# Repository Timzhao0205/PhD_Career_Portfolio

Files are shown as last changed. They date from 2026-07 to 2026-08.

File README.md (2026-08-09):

# PhD_Career_Portfolio

Yiming "Tim" Zhao — Stanford EE PhD (Senesky group). Three tracks, kept
separate on purpose.

| Folder | What lives there | Index |
|---|---|---|
| `01_PhD_Research/` | GaN Hall-effect magnetic sensing for fusion diagnostics in the HSX stellarator: the experimental line, its publications, and the analysis packages built around it. | `01_PhD_Research_Folder_Info.md` |
| `02_Startup/` | Venture research — five rounds of searching for a company to found around 2029–2030 — plus two hands-on technical projects spun out of it. | `02_Startup_Folder_Info.md` |
| `03_Investments_and_Finance/` | Market learning lab and equity benchmarking missions. | — |

## Conventions

Two-digit prefixes order folders at every level, and the same numbering runs
inside each project: `01_` mission, `05_`/`80_` durable state, `90_` sources,
`98_` run metrics, `99_` audit.

Most numbered folders are self-contained Claude Code packages with their own
binding `CLAUDE.md`, a `00_README_START_HERE.md`, and `.claude/agents/`. Launch
`claude` from the package folder, not from here, so its rules and agents load.

Markdown is the source of truth everywhere. `.html` files are generated mirrors
— regenerate rather than edit them.

## Two things worth knowing about

- **`02_Startup/00_SOURCE_DATABASE/`** — every source any startup round ever
  gathered, 3,432 of them, merged into one queryable database with full
  provenance. Search it before starting new research.
- **Snapshot folders.** Two run packages vendored full copies of research that
  already lives elsewhere in this repository. Those copies were removed and
  replaced by a manifest and a `rehydrate.py` that rebuilds them on demand:
  `01_PhD_Research/09_PAP06_Career_Portfolio_Synthesis_2026-07/sources/` and
  `02_Startup/07_Frontier_Ideas_Interactive_2026-07/src/06/`. Each has a README.

`REORGANIZATION_2026-08.md` records the 2026-08-08 cleanup that produced the
current layout.

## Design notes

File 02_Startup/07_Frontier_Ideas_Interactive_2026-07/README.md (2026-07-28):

# Folder 06 interactive Fable rerun — no budget stop

This is a fresh standalone package for Windows PowerShell 5.1 and Claude Code
interactive mode. It preserves the complete validated Folder 06 corpus but
does not reuse the previous PowerShell stream parser, response sentinel,
per-stage child launchers, or budget/turn-stop machinery.

## One command to start or resume

Extract to a short path, preferably:

```text
C:\AI\F06I
```

Open **Windows PowerShell**, enter the extracted folder, and run:

```powershell
powershell -NoProfile -ExecutionPolicy Bypass -File .\START.ps1
```

The same command:

1. checks the exact PowerShell target and package/source hashes;
2. parses every active PowerShell script using the installed PS 5.1 parser;
3. runs offline fixtures for every stage and every hook;
4. starts a persistent interactive Claude Code session on Fable 5/xhigh;
5. resumes the recorded session on later runs;
6. keeps working through all eight stage pilots and full stages;
7. validates and checkpoints every stage;
8. stops only after the final audited release passes.

There is no package-defined monetary, turn, token, or time shutdown.

## Required setup

1. Use the memorized runtime:

   ```text
   Windows PowerShell 5.1.26100.8875 Desktop
   Build 10.0.26100.8875
   CLR 4.0.30319.42000
   ```

2. Install and sign in to Claude Code. Confirm:

   ```powershell
   claude --version
   claude
   ```

   If Claude opens successfully, exit that test session and return to this
   folder.

3. Keep the package at a short path. Do not run it from inside another Claude
   project.

4. Run the one command above. Claude opens interactively and begins
   automatically. You may observe it, but routine input is not required.

## Model and effort route

| Stage | Main accepted work | Auxiliary work | Pilot |
|---|---|---|---|
| 10_refresh | Fable 5/xhigh reconciliation | Sonnet/high retrieval | Required |
| 20_p4 | Fable 5/xhigh scoring | Sonnet/high mechanical check | Required |
| 30_redteam | Fable 5/xhigh judgment | Sonnet/high retrieval | Required |
| 40_select | Fable 5/xhigh selection | Sonnet/high mechanical check | Required |
| 45_packs | Fable 5/xhigh acceptance | Sonnet/high retrieval/check | Required |
| 50_deep | Fable 5/xhigh deep analysis | Sonnet/high retrieval/check | Required |
| 60_synth | Fable 5/xhigh synthesis | Sonnet/high mechanical check | Required |
| 70_audit | Fable 5/xhigh final audit | Sonnet/high retrieval/check | Required |

The main session remains Fable throughout, so the package no longer has to
switch or parse models between stages.

## Full permissions

The launcher uses:

```text
--permission-mode bypassPermissions
```

This provides unattended read/edit/tool permission. It is powerful. Run only
inside this dedicated folder, preferably in a Windows Sandbox or VM. Project
instructions prohibit writes outside the package and prohibit modification of
`src\06`, but bypass mode itself is not an operating-system sandbox.

## Logging

| File | Contents |
|---|---|
| `logs\status.jsonl` | Model, effort, tokens, context, duration, cost telemetry, limits |
| `logs\events.jsonl` | Session, failure, subagent, compaction, and stop events |
| `state\ACTIVE_SESSION.json` | Resumable session ID and observed model |
| `state\stages\<stage>.json` | Validation result, model/effort, files, hashes |
| `pilot\<stage>` | Required pre-stage pilot |
| `outputs\<stage>` | Accepted full-stage work |
| `outputs\70_audit\FINAL` | Canonical audited package |

Reported dollar values are telemetry; they are not a local spending cutoff.

## Pausing and resuming

- To pause manually, press `Ctrl+C`. The Stop hook does not override a user
  interrupt.
- To resume, rerun the same `START.ps1` command.
- If Claude Code reports an external usage or authentication limit, close it,
  resolve/wait for the external issue, and run the same command.
- Do not delete `state`, `outputs`, `logs`, or `pilot`.

Optional diagnostics:

```powershell
# Offline checks and fixtures only
powershell -NoProfile -ExecutionPolicy Bypass -File .\START.ps1 -CheckOnly

# Verify all completed stages and the final release
powershell -NoProfile -ExecutionPolicy Bypass -File .\VALIDATE.ps1 -All

# Start a fresh interactive session while retaining durable outputs
powershell -NoProfile -ExecutionPolicy Bypass -File .\START.ps1 -NewSession

# Explicitly authorize a fresh attempt after a protected second model event
powershell -NoProfile -ExecutionPolicy Bypass -File .\START.ps1 -RetryFableAfterReview
```

`-AllowCompatiblePS51` accepts another Windows PowerShell 5.1 Desktop patch
level. Use it only when you intentionally changed Windows; the default remains
the exact memorized runtime.

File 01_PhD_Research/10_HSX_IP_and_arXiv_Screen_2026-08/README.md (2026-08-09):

# HSX IP/arXiv review — native Claude Code package

This is a self-contained, publication-only research package. It launches the
native Claude Code interface from Windows PowerShell, requests Claude Fable 5 at
xhigh effort for the parent and critical judgment stages, assigns Sonnet 5 to
cost-efficient support stages, and saves checkpoints after every stage.

It does **not** inherit state, outputs, source counts, or errors from any earlier
package. The large PhD and startup archives are intentionally excluded because
the task is limited to technologies actually disclosed in this manuscript.

## Recommended setup

1. Extract this folder to a short local path, preferably `C:\HSX_IP` or
   `D:\HSX_IP`. Do not run it from inside the ZIP.
2. Open **Windows PowerShell** in that extracted folder.
3. If native Claude Code is not installed, run once:

   ```powershell
   irm https://claude.ai/install.ps1 | iex
   ```

4. If you have never signed in, run `claude` once and complete authentication.
5. Begin or resume with the same single command:

   ```powershell
   powershell -NoProfile -ExecutionPolicy Bypass -File .\START.ps1
   ```

`START.ps1` performs a deterministic preflight, opens the interactive Claude
Code interface, and uses a named session. On later runs it resumes from
`state/STATE.json` and the latest checkpoint.

## Permission warning

The command uses `--dangerously-skip-permissions` because full read/write access
was requested. Native Windows does not sandbox this mode. The project rules tell
Claude to work only in this folder, but the operating-system permission is
broader. Use a dedicated folder and do not place credentials or unrelated
sensitive files beside it. Claude Code may display its own one-time confirmation
the first time bypass mode is used; a project cannot suppress that safeguard.

## Model integrity

- Parent/orchestrator: Fable 5 / xhigh.
- Critical IP, UHV/GDC, red-team, and final stages: Fable 5 / xhigh.
- Structured extraction and source-heavy stages: Sonnet 5 at medium to xhigh.
- Automatic model switching on a safety flag is disabled.
- A first Fable flag is quarantined and retried once with a narrower benign
  prompt; a second pauses with a durable checkpoint.
- No provider or model substitution is silently accepted.

See `MODEL_PLAN.md` for the full table. Actual model, effort, duration, turns,
tokens, web activity, and cost are logged only when Claude Code exposes them;
unknown values are recorded as `not_exposed` rather than guessed.

## Intended outputs

The main decision documents will appear under `outputs`:

- `70_FINAL_OTL_BRIEF.md`
- `70_EXEC_SUMMARY.md`
- `70_MODEL_REPORT.md`
- `50_ARXIV_RISK.md`
- `40_UHV_PACKAGE_VERDICT.md`

The workflow performs research and drafts only. It does not file a patent,
contact Stanford OTL or counsel, modify the submitted manuscript, or upload to
arXiv.

## If interrupted

Run the same command again. Do not delete `state`, `outputs`, or `.claude`.
Consult `RESUME.md` only if the workflow explicitly writes `state/PAUSE.md`.

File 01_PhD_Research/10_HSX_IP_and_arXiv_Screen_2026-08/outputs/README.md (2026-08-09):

# Generated outputs

Claude Code writes stage deliverables here. This placeholder prevents an empty
directory from disappearing during ZIP extraction.

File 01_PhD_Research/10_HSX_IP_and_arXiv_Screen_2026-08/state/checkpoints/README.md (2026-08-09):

# Checkpoints

The parent writes one `XX_done.json` file after each accepted stage. These are
the authoritative resume boundaries.

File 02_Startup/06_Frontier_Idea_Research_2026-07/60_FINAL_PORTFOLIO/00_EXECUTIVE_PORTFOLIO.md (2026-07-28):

# Executive frontier portfolio

## Outcome

The portfolio contains exactly 24 launch-2030 concepts that pass the seven hard gates after adversarial review. It is intentionally a set of testable options rather than a forced single winner: score ranges overlap, buyer access remains unproven for several concepts, and the 2026-2029 program is designed to remove those uncertainties before company formation.

| Rank | Idea | Concept | Lane | Archetype | US | China | Score | Evidence posture |
|---:|---|---|---|---|:---:|:---:|---:|---|
| 1 | `P3R2-D-02` | Reel-to-reel contactless REBCO tape quality metrology (Hall-array critical-current mapping + delamination screening) sold to tape vendors and magnet builders as certified acceptance instrumentation. | L03 | industrial | Y | Y | 65.6 | evidence-rich |
| 2 | `P3R2-C-22` | Electrolyzer stack degradation-emulation and bankability test systems: programmable ripple/intermittency benches that turn stack warranties into measurable engineering | L11 | industrial | Y | Y | 64.6 | evidence-rich |
| 3 | `P3R2-D-01` | Merchant quench-detection-and-protection subsystem for REBCO/HTS magnets: co-wound distributed fiber-optic sensing plus sub-millisecond active energy extraction, sold with a qualification dossier to fusion companies and national labs. | L03 | scientific_big_physics | Y | N | 62.8 | mixed evidence |
| 4 | `P3R2-F-01` | Solid-state microsecond impedance-matching engines (switched SiC/PIN capacitor arrays replacing motorized vacuum-capacitor matchboxes) for pulsed and tailored-waveform RF plasma tools | L06 | industrial | Y | Y | 59.8 | evidence-rich |
| 5 | `P3R2-C-01` | 800-VDC rack power-path protection: integrated solid-state breaker + precharge/inrush control + insulation monitoring + hot-swap sequencing unit for AI racks and power sidecars | L02 | infrastructure_utility_transport | Y | Y | 59.6 | evidence-rich |
| 6 | `P5-USSCI2-S01` | Qualified diamond transmission-dynode membrane and integration cartridge for hybrid MCP-PMTs used in EIC-class photon detectors | L13 | scientific_big_physics | Y | N | 58.2 | mixed evidence |
| 7 | `P3R2-E-14` | Multi-terminal DC fault-discrimination protection relay plus vendor-neutral hardware-in-the-loop qualification platform for MVDC datacenter distribution and HVDC converter stations - the 'SEL of DC grids.' | L08 | infrastructure_utility_transport | Y | N | 56.4 | evidence-rich |
| 8 | `P5R2-CN-01` | Retrofit X-ray computed-laminography kit for advanced-packaging failure analysis | L06 | industrial | Y | Y | 55.6 | evidence-rich |
| 9 | `P3R2-A-14` | 300C-class mixed-signal instrumentation electronics platform (SiC/SOI) for superhot geothermal, downhole, and turbine environments | L15 | industrial | Y | N | 54.6 | mixed evidence |
| 10 | `P3R2-C-13` | Precision GaN pump-driver and laser-power modules: nanosecond-class programmable current drive as a merchant subsystem for industrial and defense-adjacent laser OEMs | L12 | industrial | Y | Y | 54.2 | mixed evidence |
| 11 | `P3R2-C-08` | Thermal-shock-tolerant printed-circuit heat exchangers (PCHE): merchant diffusion-bonded recuperators for sCO2 power, heat pumps, and hydrogen precooling | L04 | industrial | Y | Y | 51.6 | mixed evidence |
| 12 | `P3R2-B-01` | Sealed negative-pressure (subatmospheric) water/low-GWP two-phase cold-plate loop for >2 kW/chip Chinese AI racks - leak-safe by physics (air leaks in, coolant never leaks out), PFAS-free by design | L14 | infrastructure_utility_transport | N | Y | 51.0 | mixed evidence |
| 13 | `P3R2-E-04` | High-density cryogenic interconnect loader with co-packaged 4K readout front-end (superconducting flex harness + cryo-CMOS multiplexing + cryo-LNA), breaking the 256-channel-per-loader wall for quantum computers. | L13 | scientific_big_physics | Y | N | 51.0 | mixed evidence |
| 14 | `P5R2-CN-03` | Field-deployable industrial high-temperature heat-pump commissioning and measurement-and-verification island | L04 | industrial | N | Y | 50.0 | mixed evidence |
| 15 | `P3R2-F-02` | Superconducting-magnet electrical balance-of-plant platform: standardized precision drive-and-dump skids (10 ppm-class high-current DC converters + energy-extraction/dump units + current leads + busbars) | L03 | scientific_big_physics | Y | Y | 49.4 | speculative / validate first |
| 16 | `P3R2-C-04` | PFAS-free pumped two-phase direct-to-chip cooling loop: hermetic, fluid-agnostic evaporator/condenser subsystem co-qualified with low-GWP non-PFAS working fluids | L14 | infrastructure_utility_transport | Y | Y | 49.0 | speculative / validate first |
| 17 | `P3R2-F-12` | Classification-certified DC power and protection stacks for battery-electric and battery-swap inland/coastal vessels (CCS Rules-native string protection, insulation monitoring, containerized-pack power interface) | L10 | infrastructure_utility_transport | N | Y | 47.6 | speculative / validate first |
| 18 | `P3R2-G-01` | Closed-loop UHV chamber conditioning and acceptance-certification systems for China's big-science vacuum supply chain: instrumented vacuum-firing/bakeout stations with measured hydrogen-outgassing endpoints, integrated rate-of-rise/leak/RGA acceptance metrology, and tamper-evident per-chamber certification - sold as equipment plus recurring calibration to the China-registered fabricators who alone may bid HEPS/CEPC-class chamber tenders. | L07 | industrial | N | Y | 47.6 | speculative / validate first |
| 19 | `P3R2-A-10` | Vendor-neutral ion-energy-distribution metrology + tailored-waveform bias control retrofit for plasma etch chambers | L06 | industrial | Y | Y | 47.4 | speculative / validate first |
| 20 | `P3R2-G-03` | DC-conversion acceptance and commissioning instrumentation: a portable measurement island (swept-impedance bus-stability analyzer, IT-network insulation/ground-fault characterization, hot-swap/inrush transient capture) plus standardized acceptance protocols and signed dossiers, for facilities converting legacy UPS power rooms to 240V/336V/+-400V/800VDC and for vendors qualifying DC shelves - the measurement layer of the DC transition, not another in-path power product. | L02 | infrastructure_utility_transport | Y | Y | 47.0 | speculative / validate first |
| 21 | `P3R2-D-12` | Electrohydrodynamically-pumped two-phase cold plates: field-driven, no-moving-parts per-chip flow control for 3-5 kW AI packages, with a non-PFAS working-fluid plan. | L14 | infrastructure_utility_transport | Y | Y | 46.8 | speculative / validate first |
| 22 | `P3R2-F-23` | PEM electrolyzer 'protective operating envelope' controllers with warranty-grade black-box logging: embedded plant hardware that shapes current/OCV stress and produces bankable degradation evidence | L11 | industrial | Y | Y | 44.2 | speculative / validate first |
| 23 | `P3R2-F-06` | Precision wideband DC current/voltage sensing platform (optical and zero-flux hybrid) for HVDC converter stations, electrolyzer plants, and magnet systems | L08 | infrastructure_utility_transport | Y | N | 42.4 | speculative / validate first |
| 24 | `P3R2-F-03` | High-speed permanent-magnet turbo-generator + power-converter 'electrical cartridge' (0.3-20 MW) for waste-heat sCO2 and geothermal/ORC power blocks | L04 | industrial | Y | Y | 37.2 | speculative / validate first |

## Why the portfolio is frontier and credible

The common pattern is a narrow, controllable product inserted where a frontier system becomes measurable, protectable, certifiable, or manufacturable. The coolest ideas are not speculative physics projects: they turn difficult physical behavior into a product boundary that a named operator, laboratory, OEM, or project developer must accept.

Credibility comes from explicit kill rules. The portfolio gives no structural credit to held concepts, access-dependent cheap experiments, generic category spending, or policy aspirations without an exact product job. Ten immediately executable sub-$100k falsifiers test merchant sockets and acceptance boundaries before expensive hardware programs.

## How to use the ranking

Ranks are triage order, not certainty. Start the cheapest decisive tests across several lanes in parallel. Promote only ideas that earn signed access, buyer-owned data, paid evaluation, or interface-control participation; demote any idea whose wedge is absorbed by an incumbent or whose named 2030 trigger slips.

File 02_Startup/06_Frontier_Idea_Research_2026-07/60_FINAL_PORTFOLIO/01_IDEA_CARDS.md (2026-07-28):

# Full idea cards

Every card keeps the same order. Founder fit is intentionally last and carries only 2/100 of the score.

## 1. Reel-to-reel contactless REBCO tape quality metrology (Hall-array critical-current mapping + delamination screening) sold to tape vendors and magnet builders as certified acceptance instrumentation. (`P3R2-D-02`)

**Buyer and painful job.** Commonwealth Fusion Systems (Devens tape/magnet line); Furukawa/SuperPower (several-hundred-km supply deal to Tokamak Energy); Shanghai Superconductor / Shanghai Shangchuang (CN domestic capacity buildout); Western Superconducting Technologies (CN, ITER strand lineage, L03-031, from B-10); ASIPP Hefei high-field magnet program (CN, L03-029/037, from B-10). Fewer than 10 tape vendors supply the world; a single fusion order absorbs a meaningful share of annual output, yet Ic uniformity, strain/delamination and screening-current degradation force magnet builders to over-specify and re-test tape with bespoke, non-comparable acceptance methods (L03-003, L03-019, L03-018, L03-020, L03-021).

**Product.** 77 K reel-to-reel scanner: dense Hall-sensor array plus lock-in thermal imaging maps position-resolved Ic and detects buried delamination/dropouts at m/s line speed, with transport-Ic-calibrated reporting and a shared acceptance data format for vendor and buyer. Merged extensions: 10kA-class cable/CICC acceptance stations and financier/insurer-grade data packages (from C-11); per-meter 'conductor passport' reporting framing (from B-10); conductor/joint QA benches with a Furukawa/Fujikura partnership channel (from E-07).

**Cool frontier vision.** The KLA of superconductors: every kilometer of HTS tape and every finished cable/coil ships with a standardized, instrument-traceable quality map, closing the loop back into deposition process control.

**Extreme edge.** Imaging supercurrents through millimeters of steel and silver at highway speed -- a contactless ammeter for a quantum fluid.

**Current demand proof.** Tokamak Energy and Furukawa Electric Group Strengthen Relationship to Progress Commercial Fusion Energy (L03-044); 全球首条超公里级高温超导电缆投运 (World's first kilometer-class HTS cable enters operation, Shanghai) (L03-041); U.S. Department of Energy Announces Selectees for Fusion Innovation Research Engine Collaboratives and Milestone Program progress (L03-032); Commonwealth Fusion Systems leans on magnets for near-term revenue (L03-035)

**Niche size by bottom-up arithmetic.** Screening case: 18 sites × $300k instrument + 18 × $60k annual calibration/service = $6.48M annualized niche. Named-site counting and buyer quotes must replace the assumptions.

**Competition.** Vendor in-house scanners (THEVA Tapestar-class -- judgment), Lake Shore-style lab instruments, national-lab one-offs. No merchant, buyer-trusted acceptance-metrology vendor in the atlas record set.

**Technical path.** Current TRL 4. 2026-27: benchtop magnetscan rig on purchased tape lots; publish correlation of contactless Ic estimate to transport Ic within a few percent. 2027-28: pilot placements with one US magnet builder and one tape vendor under NRE contracts; extend to coil/cable acceptance heads. 2029: inline-speed prototype at a vendor line; draft an open acceptance-report schema with two counterparties.

**Decisive experiment and budget.** $120,000. Benchtop 77 K reel-to-reel Hall-array scan of 100 m commercial tape; blind-correlate predicted vs transport Ic on 50 cut samples to <5% error (2027). The bounded test attacks the candidate's load-bearing technical and buyer-acceptance assumptions with explicit pass/kill thresholds.

**V1 capital and time.** 1500000; 4000000 Target 18-30 months from frozen interface to qualification-ready v1.

**Risks and kill criteria.** Tape vendors may bundle 'good-enough' in-house QC data; if one instrument maker partners exclusively with the largest vendor, the neutral-referee position is lost. Commercial kill: 2034-06

**US route.** Countable base case. Start with the named buyers, integrators, and qualification facilities in the accepted pack.

**China route.** Countable base case using locally supportable supply, calibration, qualification, and civilian buyer channels; screen counterparties and data flows before engagement.

**Optional side routes.** JP; KR only after the primary route proves repeatability.

**Expansion.** Move from the first exact acceptance boundary into adjacent ratings, facilities, and recurring calibration, software, or qualification evidence only after the core product is paid for.

**Score and confidence.** 65.6/100; medium. Launch thesis: Tape volume triples-to-10x between 2026 and the early-2030s pilot-plant builds; QC pain scales with volume and with new entrants' unproven lines, peaking exactly at launch. Demand trigger: Fusion pilot-plant tape procurement waves (CFS ARC-class; Tokamak Energy ST80-HTS wire deal as precedent, L03-044), Chinese domestic REBCO capacity expansion for import independence (L03-052), and CFETR magnet procurement if construction starts (L03-024). Additional evidenced demand (merged): DOE milestone-program QA needs and CFS magnet-as-product certification (L03-032/035, from C-11); the State Grid Shanghai 35 kV commercial HTS cable and follow-ons (L03-041, from B-10); ASIPP's high-field program (L03-029/037) and WST's ITER-strand QA lineage (L03-031).

**Citations.** [L03-003](https://www.nature.com/articles/s41598-021-81559-z) [L03-019](https://www.sciencedirect.com/science/article/pii/S2772830725000390) [L03-024](https://www.sciencedirect.com/science/article/abs/pii/S0920379622000631) [L03-029](https://www.the-innovation.org/article/id/695a0b800989772a128c5422) [L03-018](https://academic.oup.com/nsr/article/10/3/nwad001/6973212) [L03-044](https://www.furukawaelectric.com/en/release/2023/kenkai_20230112.html) [L03-041](https://www.jiemian.com/article/6938856.html) [L03-052](https://chinacable.com/news/details/3999)

**Founder fit (2/100; last).** The transferable fit is instrumentation, embedded control, electromagnetics, prototyping, and technical research. This note did not rescue demand, competition, capital, geography, or timing failures.

## 2. Electrolyzer stack degradation-emulation and bankability test systems: programmable ripple/intermittency benches that turn stack warranties into measurable engineering (`P3R2-C-22`)

**Buyer and painful job.** US H2Hubs project developers and their lenders (US); Plug Power-class OEM warranty engineering (US); LONGi/Peric/Sungrow hydrogen divisions (CN); Chinese EPC/owner acceptance-test labs for mega-tenders (CN). US: stack warranties are written before the industry knows which stress (OCV rest, ripple amplitude, load-following rate) drives which degradation mode (L11-001/003/004/021/031) - a direct bankability problem for H2Hubs-financed projects (L11-032) and OEMs bleeding order books (L11-047/048). CN: 100+-unit multi-vendor tenders (L11-050/051) and flagship underperformance (Kuqa, L11-049) create buyer-side acceptance-testing demand with no standard test hardware.

**Product.** Turnkey 50-500kW stack test benches with programmable rectifier-ripple synthesis, renewable-profile playback, OCV-cycling protocols, and impedance diagnostics; plus a shared accelerated-vs-field degradation dataset licensed to financiers - the Chroma of electrolysis (battery-formation analogy: L11-043/044).

**Cool frontier vision.** The qualification authority for electrochemical assets: electrolyzers first, then flow batteries, CO2 electrolyzers, and formation lines - whoever owns degradation truth owns the industry's cost of capital.

**Extreme edge.** Synthesizing 20-year renewable-coupled electrochemical stress histories in 90-day campaigns with per-mechanism attribution (catalyst dissolution vs membrane vs contact resistance).

**Current demand proof.** Regional Clean Hydrogen Hubs award announcement -- up to $2.2 billion for Gulf Coast (HyVelocity) and Midwest (MachH2) Hubs (L11-032); Plug Power Reports Q4 and Full Year 2025 Results with Strong Sales Growth and Margin Expansion (L11-046); Nel ASA: Fourth quarter 2025 financial results (L11-047); thyssenkrupp nucera returns to profit in 2024/2025 despite decline in sales (FY2024/25 results) (L11-048)

**Niche size by bottom-up arithmetic.** Screening case: 18 sites × $300k instrument + 18 × $60k annual calibration/service = $6.48M annualized niche. Named-site counting and buyer quotes must replace the assumptions.

**Competition.** Greenlight Innovation-class test-stand vendors (industry name, flag for P4 - not in atlas), battery-test majors extending sideways (Chroma/Hioki, L11-043/044), OEM in-house labs. Wedge: degradation-science depth + financier-facing datasets, not just power hardware.

**Technical path.** Current TRL 5. 2026-27: replicate published degradation stressors on a 10kW bench (university electrochemistry lab); publish accelerated-test correlation study - the field's missing dataset. 2027: decisive 50kW bench (below). 2028: paid pilot campaigns via lab (OEM + one lender consortium). 2029: purchase LOIs; refresh the demand picture - Western OEM health and Chinese tender cadence will have shifted from 2026.

**Decisive experiment and budget.** $250,000. 2027: 50kW programmable-ripple/OCV-cycling bench; 90-day accelerated campaign on two commercial short stacks; publish correlation of induced vs literature degradation signatures. The bounded test attacks the candidate's load-bearing technical and buyer-acceptance assumptions with explicit pass/kill thresholds.

**V1 capital and time.** 4000000; 10000000 Target 18-30 months from frozen interface to qualification-ready v1.

**Risks and kill criteria.** Hydrogen demand volatility caps growth (order books shrinking now, L11-047/048) - but the seed monetizes uncertainty itself; worst case is a slow niche, not a zero. Export separability excellent (test equipment; CN entity straightforward). Kill if neither market yields bench sales nor paid campaigns by end-2033. Commercial kill: 2034

**US route.** Countable base case. Start with the named buyers, integrators, and qualification facilities in the accepted pack.

**China route.** Countable base case using locally supportable supply, calibration, qualification, and civilian buyer channels; screen counterparties and data flows before engagement.

**Optional side routes.** JP; KR only after the primary route proves repeatability.

**Expansion.** Move from the first exact acceptance boundary into adjacent ratings, facilities, and recurring calibration, software, or qualification evidence only after the core product is paid for.

**Score and confidence.** 64.6/100; medium. Launch thesis: Whether hydrogen booms or consolidates by 2030, both outcomes need qualification: boom -> acceptance testing at tender scale (CN); consolidation -> survivors differentiate on warranty credibility (US/EU). Test infrastructure is the hedge position on a volatile industry - deliberately anti-fragile to the L11 demand contradiction. Demand trigger: US: H2Hubs Phase-2 construction/commissioning waves with lender-mandated performance validation (L11-032). CN: second-wave green-H2 base tenders and retrofit/acceptance programs following first-wave underperformance (L11-049/050/051).

**Citations.** [L11-001](https://iopscience.iop.org/article/10.1149/1945-7111/ae1cf1) [L11-002](https://www.sciencedirect.com/science/article/abs/pii/S0016236125036452) [L11-003](https://iopscience.iop.org/article/10.1149/1945-7111/add184) [L11-004](https://www.sciencedirect.com/science/article/pii/S1364032125008433) [L11-021](https://pmc.ncbi.nlm.nih.gov/articles/PMC8877858/) [L11-032](https://www.energy.gov/articles/biden-harris-administration-announces-awards-22-billion-two-regional-clean-hydrogen-hubs) [L11-046](https://www.ir.plugpower.com/press-releases/news-details/2026/Plug-Power-Reports-Q4-and-Full-Year-2025-Results-with-Strong-Sales-Growth-and-Margin-Expansion/default.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) [L11-047](https://nelhydrogen.com/press-release/nel-asa-fourth-quarter-2025-financial-results/)

**Founder fit (2/100; last).** The transferable fit is instrumentation, embedded control, electromagnetics, prototyping, and technical research. This note did not rescue demand, competition, capital, geography, or timing failures.

## 3. Merchant quench-detection-and-protection subsystem for REBCO/HTS magnets: co-wound distributed fiber-optic sensing plus sub-millisecond active energy extraction, sold with a qualification dossier to fusion companies and national labs. (`P3R2-D-01`)

**Buyer and painful job.** Commonwealth Fusion Systems (sells magnets to Realta, WHAM); Tokamak Energy / TE Magnetics; DOE milestone-program fusion awardees; university/national-lab high-field magnet programs; US-ITER/ORNL magnet operations (from A-04/E-07, L03-030). HTS coils have very high minimum quench energy and slow normal-zone propagation, so voltage-tap detection fails; builders must choose between no-insulation windings (poor ramp/control) or unproven fast detection, over-engineering every multi-megajoule magnet (L03-004, L03-018, L03-020, L03-021).

**Product.** Retrofittable quench detection + protection package: Rayleigh-backscatter fiber co-wound in the coil plus RF/acoustic hotspot channels, fused in a deterministic FPGA trigger driving a qualified multi-kV energy-extraction/CLIQ-class dump circuit; delivered with test data at 10-20 T relevant conditions. Merged extensions: delivered with a published acceptance-test protocol and warranty-support framing for merchant magnet sales (from A-04); the accumulated quench-precursor signature dataset across driven-quench campaigns is the compounding moat (from E-07).

**Cool frontier vision.** Become the certification-grade 'flight recorder and ejection seat' for every high-field HTS magnet -- fusion, NMR, accelerator, industrial -- the way rad-hard PLCs became mandatory in nuclear I&C.

**Extreme edge.** Watching a superconductor start to die in real time -- centimeter-resolved strain/temperature along kilometers of tape at kilohertz rates -- and killing a 100 MJ discharge before it burns the coil.

**Current demand proof.** U.S. Department of Energy Announces Selectees for Fusion Innovation Research Engine Collaboratives and Milestone Program progress (L03-032); Tokamak Energy raises $125m to commercialise transformative fusion and magnet technologies (L03-033); Commonwealth Fusion Systems leans on magnets for near-term revenue (L03-035); 한전, 초전도 케이블로 심지 전력 공급한다 (KEPCO to supply downtown power via superconducting cable) (L03-042)

**Niche size by bottom-up arithmetic.** Screening case: 6 facilities × $750k initial system + 6 × $125k annual support = $5.25M annualized niche. This is decision arithmetic, not a sourced market forecast; replace both inputs with quotes before investment.

**Competition.** In-house teams at CFS/TE Magnetics (L03-035, L03-044), national-lab solutions (CERN CLIQ lineage, tuned for LTS), instrumentation vendors without protection power electronics. No merchant vendor of an integrated HTS detection+dump product identified in the atlas.

**Technical path.** Current TRL 3. 2026-27: university magnet-lab access (e.g., high-field magnet facility) and instrumentation of small REBCO pancakes; publish detection-latency benchmarks. 2027-28: DOE SBIR/INFUSE-class grants with a fusion partner; controlled-quench campaigns on 1-2 T coils. 2029: demonstrate 100 ms-class pre-quench warning plus automated dump on a multi-kA coil at a partner lab; freeze v1 architecture and qualification plan.

**Decisive experiment and budget.** $250,000. Co-wind fiber + RF pickup in a 1-2 T REBCO double-pancake, drive controlled quenches, and demonstrate >=100 ms warning before thermal runaway with <1% false-trigger rate (2027, university magnet lab). The bounded test attacks the candidate's load-bearing technical and buyer-acceptance assumptions with explicit pass/kill thresholds.

**V1 capital and time.** 3000000; 8000000 Target 18-30 months from frozen interface to qualification-ready v1.

**Risks and kill criteria.** If no-insulation windings prove fully sufficient at pilot-plant scale, the detection problem shrinks; if a magnet builder open-sources a good solution, differentiation collapses to service/qualification. Commercial kill: 2033-12

**US route.** Countable base case. Start with the named buyers, integrators, and qualification facilities in the accepted pack.

**China route.** Not a countable base case in this round; do not depend on this route.

**Optional side routes.** None required for the base case.

**Expansion.** Move from the first exact acceptance boundary into adjacent ratings, facilities, and recurring calibration, software, or qualification evidence only after the core product is paid for.

**Score and confidence.** 62.8/100; low. Launch thesis: SPARC-class results in 2026-27 convert into pilot-plant magnet builds around 2030; every new builder needs protection it cannot buy today, and qualification data accumulated 2027-2029 is the moat at exactly that moment. Demand trigger: Post-SPARC fusion pilot-plant magnet procurement (CFS ARC-class, Tokamak Energy ST80-HTS follow-on) and the DOE Milestone-Based Fusion Development Program renewal decision after its FY2027 authorization window (L03-032, L03-033, L03-035); CFETR magnet procurement if it opens (L03-024) is upside, not baseline. Side market (from E-07): KEPCO + LS Cable/LS Electric superconducting datacenter-grid MOU as a cable-monitoring channel (L03-042/043); US-ITER/ORNL magnet operations as lab-side buyers (L03-030). CN chapter (from C-17): ASIPP/CFETR demand logic exists (L03-024/029/037) but is served only via license-out and ONLY if export counsel clears - quench protection is dual-use-adjacent; no CN beachhead, flags unchanged.

**Citations.** [L03-004](https://doi.org/10.3390/instruments5030027) [L03-018](https://academic.oup.com/nsr/article/10/3/nwad001/6973212) [L03-020](https://iopscience.iop.org/article/10.1088/1361-6668/ad7f95) [L03-021](https://www.sciencedirect.com/science/article/abs/pii/S0920379623001072) [L03-029](https://www.the-innovation.org/article/id/695a0b800989772a128c5422) [L03-032](https://www.energy.gov/articles/us-department-energy-announces-selectees-107-million-fusion-innovation-research-engine) [L03-033](https://www.prnewswire.com/news-releases/tokamak-energy-raises-125m-to-commercialize-transformative-fusion-and-magnet-technologies-302310607.html) [L03-035](https://techcrunch.com/2026/04/02/commonwealth-fusion-systems-leans-on-magnets-for-near-term-revenue/)

**Founder fit (2/100; last).** The transferable fit is instrumentation, embedded control, electromagnetics, prototyping, and technical research. This note did not rescue demand, competition, capital, geography, or timing failures.

## 4. Solid-state microsecond impedance-matching engines (switched SiC/PIN capacitor arrays replacing motorized vacuum-capacitor matchboxes) for pulsed and tailored-waveform RF plasma tools (`P3R2-F-01`)

**Buyer and painful job.** Lam/AMAT-ecosystem RF integrators via Advanced Energy/MKS-class generator vendors (US); AMEC; NAURA; Piotech (via Hengyunchang/Injet supply chain, mature-node scope). Pulsed and tailored-voltage-waveform plasma processes change impedance faster than motorized vacuum-capacitor matching networks can follow; matching remains an active research problem (L06-001/002/003, L01-012/013) while CN RF-power component localization sits under ~12% (L06-054).

**Product.** Drop-in solid-state matching network family (400 kHz-60 MHz, 1-10 kW initially): switched capacitor/inductor arrays with sub-10-microsecond re-match, pulse-synchronous tuning tables, and health telemetry; sold to RF-generator vendors and tool OEMs; CN line scoped to >=28 nm/panel/display tools. CN chapter delivered as licensing-with-golden-reference (absorbed from F-14): the CN licensee manufactures under milestone-based contracts while the founder retains golden-reference subassemblies, calibration methodology, and factory test benches - certification power stays with the licensor (HK-structured IP entity).

**Cool frontier vision.** The impedance-delivery layer for all fast plasma processing: every pulsed plasma tool, leading-edge or mature-node, tunes in microseconds instead of hundreds of milliseconds, unlocking waveform-level process control as a standard capability.

**Extreme edge.** Pulse-by-pulse impedance trajectory control co-optimized with bias waveform, enabling ion-energy control on tools that never get an IEDF sensor.

**Current demand proof.** Advanced Energy (AEIS) Q4 2025 Earnings Call Transcript (L06-039); Shenzhen CSL Vacuum Science and Technology (Hengyunchang) IPO: customer concentration and financial disclosure (L06-042); Hengyunchang lists on SSE STAR Market, shares surge over 300% (L06-043); Sichuan Injet Electric (Yingjie Dianqi) 2024 Annual Report -- semiconductor RF power segment (L06-044)

**Niche size by bottom-up arithmetic.** Screening case: 12 production lines × $600k subsystem + 12 × $90k annual service/qualification = $8.28M annualized niche. This is a transparent validation target, not a top-down forecast.

**Competition.** Comet (Synertia platform), Advanced Energy and MKS in-house matches, DAIHEN; CN: Hengyunchang/Injet moving up-stack. Domestic-substitution speed in CN is fast at generator level but slow at high-end match-component level.

**Technical path.** Current TRL 4. 2026-27 university-lab prototype (13.56 MHz, 5 kW) and switching-loss/linearity characterization; 2027 export-control counsel gate on CN scope; 2028 two paid evaluations with a generator vendor or tool OEM; 2029 reliability data (1e9 switch events) and design-freeze of a productizable module. CN-chapter licensing mechanics (from F-14): HK-structured IP entity and milestone-based license contracts scoped 2028, know-how held in calibration/test assets.

**Decisive experiment and budget.** $250,000. Build 13.56 MHz/5 kW switched-capacitor matcher; demonstrate <10 us re-match across a pulsed plasma load recipe versus >100 ms motorized baseline, with reflected-power and lifetime data (2027). The bounded test attacks the candidate's load-bearing technical and buyer-acceptance assumptions with explicit pass/kill thresholds.

**V1 capital and time.** 3000000; 8000000 Target 18-30 months from frozen interface to qualification-ready v1.

**Risks and kill criteria.** If AE/MKS ship integrated solid-state matching as a standard feature before a merchant module gains a design win, the socket closes; mitigated by selling to the same incumbents and to CN OEMs the US incumbents cannot serve. Commercial kill: 2034 (kill if no OEM design-in or paid evaluation converts to a production order by end-2033)

**US route.** Countable base case. Start with the named buyers, integrators, and qualification facilities in the accepted pack.

**China route.** Countable base case using locally supportable supply, calibration, qualification, and civilian buyer channels; screen counterparties and data flows before engagement.

**Optional side routes.** KR only after the primary route proves repeatability.

**Expansion.** Move from the first exact acceptance boundary into adjacent ratings, facilities, and recurring calibration, software, or qualification evidence only after the core product is paid for.

**Score and confidence.** 59.8/100; medium. Launch thesis: Pulsed/TVW process adoption broadens through 2030 while incumbent matchboxes remain electromechanical; solid-state matching is demonstrated in literature but not productized as a merchant module, leaving a 2030-2034 design-in window before AE/MKS/Comet fully absorb it. Demand trigger: US: next tool-generation qualification cycles at leading-edge fabs (AE Everest/EVOS-class platform ramps per L06-039/040) requiring pulse-synchronous match; CN: 15th/16th Five-Year-Plan semiconductor-equipment localization programs and SMIC/YMTC mature-node expansions pulling domestic RF component content above today's <12% (L06-051/052/054).

**Citations.** [L06-001](https://pubs.aip.org/avs/jvb/article/42/2/022212/3277858/Modeling-and-control-of-L-type-network-impedance) [L06-002](https://pubs.aip.org/aip/jap/article/137/3/033301/3331468/Impedance-matching-assistance-based-on-frequency) [L06-003](https://www.mdpi.com/2079-9292/10/17/2074) [L06-009](https://pubs.aip.org/aip/pop/article/31/3/033508/3279954/Voltage-waveform-tailoring-for-high-aspect-ratio) [L01-012](https://pubs.aip.org/avs/jva/article/37/2/021303/247270/Experimental-demonstration-of-multifrequency) [L06-039](https://www.fool.com/earnings/call-transcripts/2026/02/10/advanced-energy-aeis-q4-2025-earnings-transcript/) [L06-042](https://www.cls.cn/detail/2060122) [L06-043](https://www.cls.cn/detail/2272598)

**Founder fit (2/100; last).** The transferable fit is instrumentation, embedded control, electromagnetics, prototyping, and technical research. This note did not rescue demand, competition, capital, geography, or timing failures.

## 5. 800-VDC rack power-path protection: integrated solid-state breaker + precharge/inrush control + insulation monitoring + hot-swap sequencing unit for AI racks and power sidecars (`P3R2-C-01`)

**Buyer and painful job.** Vertiv (US); Eaton (US); Schneider Electric (US ops); Google/Meta/Microsoft via OCP (US); Huawei-class DC integrators (CN); Alibaba datacenter power suppliers e.g. Shenzhen Autrans (CN). US: 800VDC racks specified by NVIDIA/OCP have no converged DC fault-interruption, precharge, grounding, or hot-swap solution (L02-043, L02-044; SSCB still research-stage L08-017, L08-001/003/004). CN: Huawei-ecosystem trade engineering flags 800V DC protection, grounding, hot-plug, and inlet-node oscillation as unresolved integration pain (L02-054); China HVDC datacenter penetration was only ~12% vs 78% UPS, so the conversion wave is ahead, not behind (L02-048).

**Product.** A shelf-format 800V/250-500A hybrid solid-state protection-and-sequencing unit: <100 us fault clearing, arc-signature detection (L08-018/019/020/021 methods), managed precharge, IMD, and blind-mate hot-swap logic, pre-certified to IEC 62477-1 (L02-112). Imports from merged duplicates: fleet-wide DC arc-signature analytics with a UL/IEC listing-path emphasis (from A-01); synthesized-virtual-impedance active bus damping and capacitor-health (ripple/ESR) telemetry (from B-03); arc rate-of-change dataset moat built from accumulated fault-signature libraries (from E-01).

**Cool frontier vision.** Become the de facto 'circuit-breaker layer' for all DC-native infrastructure: 800V racks, 1500V sidecars, MVDC campus feeders, EV megawatt charging, and DC industrial parks.

**Extreme edge.** Sub-100-microsecond bidirectional fault interruption at 800V/500A in a hot-swappable shelf form factor, with arc discrimination that avoids nuisance trips at 1MW-rack transient levels.

**Current demand proof.** OCP Members Tout DC Power in the Data Center to Meet Growing AI Energy Demands (L02-044); Wolfspeed (WOLF) Q3 2026 Earnings Call Transcript (L02-047); GE Vernova Q1 2026 earnings call transcript (L08-033); Delta Partners with Alibaba to Launch "Data Center Panama Power Supply," Opening a New Chapter in IDC Power (L02-048)

**Niche size by bottom-up arithmetic.** Screening case: 15 projects × $500k deployment + 15 × $75k annual qualification/support = $8.63M annualized niche. Treat project count and price as falsifiable planning inputs.

**Competition.** US 2030: Eaton/Vertiv/Schneider integrated shelves, ABB/Siemens industrial DC breakers, 1-2 funded SSCB startups. CN 2030: Huawei in-house, Delta China, Autrans (L02-049), Innoscience-device-based designs (L02-050). Window: incumbents sell whole shelves; a certified merchant protection layer that all shelf vendors can embed is unoccupied.

**Technical path.** Current TRL 4. 2026-27: publish comparative SSCB topology benchmark from lab work; join OCP power workstream; file 2-3 provisional patents on combined precharge+breaking+arc-discrimination. 2027: decisive brassboard experiment (below). 2028: second-gen unit tested in a partner rack lab (integrator MOU, no company needed); UL/IEC pre-compliance data. 2029: design-in discussions with 2 US integrators and 1 CN ODM via licensing LOIs; refresh 2029 market/pricing evidence before incorporation.

**Decisive experiment and budget.** $48,000. Merchant-module boundary falsification (4 months; $48,000). Pre-register: Freeze combined-module boundary, three required counterparties, evidence form, 2029 design-in horizon, and no-credit rules for verbal interest. Pass: Two integrators provide written requirement redlines; At least one counterparty signs a paid evaluation assigning protection, precharge, IMD, and sequencing to a replaceable third-party module through 2029. Kill: All counterparties allocate functions to fuses, internal shelves, or platform standards; No paid evaluation or replaceable socket. Budget: specification mapping $10,000, fmeca and safety case $6,000, interface control document $8,000, integrator workshops $8,000, china screening and counsel $8,000, evaluation contracting $4,000, independent review $4,000. If the merchant socket is absent, no affordable technical prototype can create it. The outreach is executable without assuming access and has a binary company-kill rule.

**V1 capital and time.** 8000000; 20000000 Target 18-30 months from frozen interface to qualification-ready v1.

**Risks and kill criteria.** Export-control separability: good - protection electronics are conventional industrial power electronics (largely EAR99); China variant can use domestic GaN/SiC (Innoscience, L02-050) built by a licensed CN entity while the US entity serves OCP customers; main risks are hyperscaler vertical integration, UL/IEC certification timeline, and any future US controls on high-performance power semiconductors. 2026 specs/prices must be refreshed in 2029. Commercial kill: 2034

**US route.** Countable base case. Start with the named buyers, integrators, and qualification facilities in the accepted pack.

**China route.** Countable base case using locally supportable supply, calibration, qualification, and civilian buyer channels; screen counterparties and data flows before engagement.

**Optional side routes.** None required for the base case.

**Expansion.** Move from the first exact acceptance boundary into adjacent ratings, facilities, and recurring calibration, software, or qualification evidence only after the core product is paid for.

**Score and confidence.** 59.6/100; medium. Launch thesis: 800VDC ramps 2027-2029 with ad hoc protection; by 2030 hyperscalers demand standardized, certified protection at gigawatt-campus scale while DC breakers remain unconverged (L08-001/003/004/017) - a component vacuum a focused entrant can own. Demand trigger: US: post-2027 NVIDIA Kyber/Rubin-Ultra 800VDC production architecture scaling into 2030-2034 gigawatt campus buildouts (L02-043) plus OCP Mount Diablo spec revisions institutionalizing DC power shelves (L02-044). CN: implementation cycle of the April 2026 national AI-energy action plan (Guo-Neng-Fa-Ke-Ji [2026] No.34, L14-036) and conversion of the historically low (~12%) HVDC penetration base in Chinese datacenters (L02-048).

**Citations.** [L08-001](https://www.sciopen.com/article/10.17775/CSEEJPES.2021.05040) [L08-003](https://www.nature.com/articles/s41598-025-27261-w) [L08-004](https://www.mdpi.com/1996-1073/18/5/1147) [L08-017](https://www.mdpi.com/1996-1073/18/14/3613) [L08-018](https://www.mdpi.com/2072-666X/10/5/314) [L02-044](https://www.datacenterdynamics.com/en/news/ocp-members-tout-dc-power-in-the-data-center-to-meet-growing-ai-power-demands/) [L02-047](https://www.fool.com/earnings/call-transcripts/2026/05/05/wolfspeed-wolf-q3-2026-earnings-transcript/) [L08-033](https://www.fool.com/earnings/call-transcripts/2026/04/22/ge-vernova-gev-q1-2026-earnings-transcript/)

**Founder fit (2/100; last).** The transferable fit is instrumentation, embedded control, electromagnetics, prototyping, and technical research. This note did not rescue demand, competition, capital, geography, or timing failures.

## 6. Qualified diamond transmission-dynode membrane and integration cartridge for hybrid MCP-PMTs used in EIC-class photon detectors (`P5-USSCI2-S01`)

**Buyer and painful job.** Brookhaven National Laboratory LDRD-26-055 hybrid MCP-PMT project; Brookhaven EIC Detector II instrumentation program if funded; US detector laboratories developing RICH, time-of-flight, and fast-photon systems. Large-area MCP-PMTs lose photoelectrons at the first plate's non-pore area and must run high MCP gain to recover single photons, increasing accumulated charge and lifetime risk. Brookhaven's 2026 RFI is unusually exact: it asks outside organizations to supply and process thin diamond films, perform laser or RIE thickness reduction, create negative-electron-affinity surfaces, and measure secondary-electron yield for a hybrid MCP-PMT.

**Product.** A reproducible, serialized transmission-dynode membrane package: thickness-controlled conductive CVD diamond, vacuum-stable negative-electron-affinity termination, guarded mount and electrode geometry, incoming electron-yield map, vacuum bake record, and a tube-integrator acceptance dossier. The startup supplies the difficult membrane/process interface and qualification data, not the MCP, photocathode, Timepix4 ASIC, or complete vacuum tube.

**Cool frontier vision.** Insert a thin, radiation-hard electron preamplifier ahead of any microchannel plate so detector builders can trade transmission gain for lower MCP voltage, longer life, and higher effective photon-detection efficiency across collider, neutron, medical, and ultrafast-imaging instruments.

**Extreme edge.** Target transmission secondary-electron gain of at least 8 at 1-3 keV while preserving timing and vacuum stability, allowing roughly an order-of-magnitude reduction in MCP charge gain for an equal downstream pulse in the validated operating point.

**Current demand proof.** RFI - Development of Hybrid MCP-PMT with a Diamond Transmission Dynode (P5-USSCI2-D01); FY2027 LDRD Type B proposal: Development of hybrid MCP-PMT with an integrated TimePix4 readout for EIC Detector II (P5-USSCI2-D02); EIC HRPPD requirements and 2026 PDE contract (P5-USSCI2-D03); EIC M17 full detail schedule (P5-USSCI2-D04)

**Niche size by bottom-up arithmetic.** Screening case: 6 facilities × $750k initial system + 6 × $125k annual support = $5.25M annualized niche. This is decision arithmetic, not a sourced market forecast; replace both inputs with quotes before investment.

**Competition.** Closest competitors are Incom's EIC HRPPD/LAPPD products, Exosens/Photonis Planacon and PhotonPix MCP-PMTs, Hamamatsu MCP-PMTs, and BNL's own tube architecture. Incom is already delivering EIC tiles and Exosens claims collection efficiency approaching 100 percent, so incumbent convergence is real. The non-cosmetic wedge is the qualified upstream diamond transmission-gain membrane/process cartridge, which can reduce the charge multiplication demanded from the MCP and is precisely the capability BNL is seeking externally; it is not a different package around an ordinary MCP.

**Technical path.** Current TRL 3. 2026: reproduce published transmission-yield measurements on commercial CVD diamond coupons and negotiate test access with a US electron-source/vacuum lab. 2027: down-select thickness, doping, front electrode, and NEA treatment on at least 12 membranes. 2028: deliver four serialized dynode cartridges for independent SEY, vacuum-bake, and lifetime testing. 2029: require a paid BNL/US-lab qualification, funded Detector II work package, or signed tube-integrator design-in; a research collaboration without a purchasing path does not count.

**Decisive experiment and budget.** $94,000. 2027-2028, nine months: procure at least 12 CVD diamond films spanning thickness and doping; laser/RIE thin them; apply two NEA treatments and two electrode schemes; map reflection and transmission electron yield in UHV before and after a 200 C bake and after an accumulated input charge test. Pass only if four membranes independently show transmission yield >=8 at <=3 keV, within-wafer yield coefficient of variation <=15%, dark current <=10 nA at the operating bias, <=10% yield loss after bake, and <=20% loss after the accelerated charge dose. Kill on surface instability in air transfer, destructive charging, timing spread >50 ps attributable to the dynode in a pulsed-electron test, or if two tube integrators say the mount cannot be sealed. The bounded test attacks the candidate's load-bearing technical and buyer-acceptance assumptions with explicit pass/kill thresholds.

**V1 capital and time.** 1800000; 4500000 Target 18-30 months from frozen interface to qualification-ready v1.

**Risks and kill criteria.** EIC Detector II may never receive construction funding, Exosens or Incom may close the collection-efficiency gap without a dynode, or BNL may internalize the process after the LDRD. Do not count base-ePIC procurement. Kill the commercial thesis at end-2029 unless a US lab or tube maker pays for qualification or writes the cartridge into a funded post-freeze detector plan. Commercial kill: 2034, with an earlier commercial kill at 2029-12-31 absent paid qualification or a funded design-in

**US route.** Countable base case. Start with the named buyers, integrators, and qualification facilities in the accepted pack.

**China route.** Not a countable base case in this round; do not depend on this route.

**Optional side routes.** None required for the base case.

**Expansion.** Move from the first exact acceptance boundary into adjacent ratings, facilities, and recurring calibration, software, or qualification evidence only after the core product is paid for.

**Score and confidence.** 58.2/100; medium-low. Launch thesis: Base ePIC photosensor procurement is too early for a 2030 entrant and is explicitly excluded from the base case. The open socket is the separately named EIC Detector II hybrid-MCP-PMT program, post-installation upgrades, replacement lots, and other US fast-photon programs. BNL is doing enabling LDRD and outside-capability market research in 2026, while the EIC master schedule extends detector integration, installation, commissioning, and operations work through 2035. Four years is enough to qualify a supplied membrane/process module without attempting to design the complete detector tube. Demand trigger: A funded EIC Detector II or ePIC upgrade/spares package that carries the hybrid MCP-PMT beyond LDRD, plus US detector programs purchasing radiation-tolerant, high-rate photon sensors during EIC commissioning and early operation. The trigger is valid only if at least one program funds external dynode hardware by end-2029.

**Citations.** [P5-USSCI2-D01](https://sam.gov/opp/c4efe4e23fad4659885b0591235e2714/view) [P5-USSCI2-D02](https://indico.bnl.gov/event/30996/?view=indico_weeks_view) [P5-USSCI2-D03](https://indico.bnl.gov/event/32132/attachments/68970/118388/ayk-2026-01-21-epic-bnl-meeting-hrppds.pdf) [P5-USSCI2-D04](https://indico.bnl.gov/event/26584/attachments/62174/106780/ePIC_28May2025_Full%20Detail.pdf) [P5-USSCI2-D05](https://www.sbir.gov/awards/189057) [P5-USSCI2-D06](https://pmc.ncbi.nlm.nih.gov/articles/PMC5456955/) [P5-USSCI2-D07](https://www.sciencedirect.com/science/article/abs/pii/S0169433202001496) [P5-USSCI2-D08](https://www.sciencedirect.com/science/article/abs/pii/S0169433296007313)

**Founder fit (2/100; last).** The transferable fit is instrumentation, embedded control, electromagnetics, prototyping, and technical research. This note did not rescue demand, competition, capital, geography, or timing failures.

## 7. Multi-terminal DC fault-discrimination protection relay plus vendor-neutral hardware-in-the-loop qualification platform for MVDC datacenter distribution and HVDC converter stations - the 'SEL of DC grids.' (`P3R2-E-14`)

**Buyer and painful job.** Pattern Energy-class US HVDC developers (Southern Spirit, $2.6B private + $360M DOE: L08-041); GE Vernova-class converter vendors (~$10B HVDC backlog + $2.4B/qtr datacenter orders: L08-033); US TSOs under NERC PRC-029-1 compliance (L08-043). DC faults must clear in single-digit milliseconds without zero-crossings; discrimination algorithms (traveling-wave, non-unit) are still being re-derived paper-by-paper, DC breakers remain non-converged, and there is no merchant DC protection relay or neutral qualification suite - so meshed DC grids cannot be built with confidence. Evidence: L08-004, L08-005, L08-006, L08-007, L08-017, L08-019, L08-020, L08-021.

**Product.** A DC protection relay implementing benchmarked traveling-wave/non-unit discrimination with <1ms decision latency, plus an open RTDS/HIL test suite that qualifies any vendor's breaker/relay/converter combination - sold to developers, converter vendors, and (as compliance tooling) to TSOs.

**Cool frontier vision.** Become the independent protection-and-qualification authority for the DC century: datacenter MVDC, offshore multi-terminal HVDC, and DC industrial parks.

**Extreme edge.** An open, published DC-protection benchmark that becomes the de facto acceptance standard - the startup owns the test everyone must pass.

**Current demand proof.** Southern Spirit Transmission project (ERCOT-Southeast US 525kV VSC-HVDC interconnector) (L08-041); GE Vernova Q1 2026 earnings call transcript (L08-033); West Coast (Saemangeum-Hwaseong) HVDC 'Energy Expressway' project overview and supplier landscape (L08-038); West Coast HVDC 'Energy Expressway' construction kickoff (KEPCO) (L08-039)

**Niche size by bottom-up arithmetic.** Screening case: 15 projects × $500k deployment + 15 × $75k annual qualification/support = $8.63M annualized niche. Treat project count and price as falsifiable planning inputs.

**Competition.** Hitachi Energy/Siemens/GE in-house protection integrated with their converters (L08-052), SEL-class AC-relay incumbents extending to DC, academic tools; the neutral-qualification niche is empty in 2026. Scope coordination (adjudication): E-14 owns the relay + qualification layer; P3R2-A-02 owns breaker hardware; P3R2-A-03 (if its 2027 gate passes) is the field MW-emulation complement.

**Technical path.** Current TRL 3. 2026-27: graduate work benchmarking published discrimination algorithms on a 4-terminal RTDS model; release open benchmark. 2027-28: relay prototype hitting <1ms decisions; publish; patents on discrimination/selectivity. 2028-29: HIL studies sold to one converter vendor and one Korean HVDC-localization supplier as engagements; LOIs; incorporate 2030.

**Decisive experiment and budget.** $300,000. 2027: RTDS/HIL benchmark of three published DC fault-discrimination algorithms on a 4-terminal MVDC model plus a relay prototype demonstrating <1ms trip decisions; publish as an open benchmark. The bounded test attacks the candidate's load-bearing technical and buyer-acceptance assumptions with explicit pass/kill thresholds.

**V1 capital and time.** 3000000; 8000000 Target 18-30 months from frozen interface to qualification-ready v1.

**Risks and kill criteria.** If US/offshore DC stays point-to-point through 2034, fast discrimination demand defers; converter vendors may refuse third-party protection in their stations. Commercial kill: 2034-12 if no multi-terminal project or vendor engagement by 2033

**US route.** Countable base case. Start with the named buyers, integrators, and qualification facilities in the accepted pack.

**China route.** Not a countable base case in this round; do not depend on this route.

**Optional side routes.** None required for the base case.

**Expansion.** Move from the first exact acceptance boundary into adjacent ratings, facilities, and recurring calibration, software, or qualification evidence only after the core product is paid for.

**Score and confidence.** 56.4/100; medium. Launch thesis: US interregional HVDC construction (Southern Spirit starts 2029) and first meshed offshore/datacenter MVDC designs hit protection-qualification needs exactly in 2030-2033, when no incumbent offers vendor-neutral DC relaying. Demand trigger: Named: Southern Spirit Transmission construction (2029) toward 2032 in-service (L08-041), the continuing GE Vernova-class HVDC/datacenter electrification order wave (L08-033), and KEPCO's West Coast HVDC procurement/localization cycle as the side-market mirror (L08-038, L08-039). CN chapter (from C-16, license-only): Chinese converter-valve/protection suppliers (XJ Electric-class) need factory-acceptance-test infrastructure and State Grid test institutes buy HIL benches - State Grid UHV/DC tender cadence documented at RMB1.275bn first-batch scale (L08-034); served via licensed test-suite packages only, no CN entity or beachhead (flags unchanged).

**Citations.** [L08-004](https://www.mdpi.com/1996-1073/18/5/1147) [L08-005](https://www.nature.com/articles/s41598-025-19589-0) [L08-006](https://ietresearch.onlinelibrary.wiley.com/doi/10.1049/rpg2.12903) [L08-007](https://doi.org/10.3390/app16115186) [L08-017](https://www.mdpi.com/1996-1073/18/14/3613) [L08-041](https://patternenergy.com/projects/southern-spirit-transmission/) [L08-033](https://www.fool.com/earnings/call-transcripts/2026/04/22/ge-vernova-gev-q1-2026-earnings-transcript/) [L08-038](https://dealsite.co.kr/articles/150180)

**Founder fit (2/100; last).** The transferable fit is instrumentation, embedded control, electromagnetics, prototyping, and technical research. This note did not rescue demand, competition, capital, geography, or timing failures.

## 8. Retrofit X-ray computed-laminography kit for advanced-packaging failure analysis (`P5R2-CN-01`)

**Buyer and painful job.** Guangzhou Guangxin Packaging Substrate and Wuxi Shennan Circuits X-ray inspection teams (CN); NIST CHIPS advanced-packaging metrology programs and US packaging failure-analysis laboratories (US). Flat multilayer substrates and advanced packages hide cracks, voids, bridges, and layer offsets behind overlapping 2D projections. Buyers already procure X-ray inspection cabinets, while high-resolution CT/XRM systems are costly, slow, and usually sold as complete cabinets.

**Product.** A tilted precision stage, cabinet-specific geometry calibration target, sparse-view reconstruction software, and package-defect classifier retrofitted to qualifying installed 2D X-ray cabinets. It does not replace the X-ray source or shielding enclosure.

**Cool frontier vision.** Make the frontier system deployable by turning its hardest physical acceptance boundary into a merchant product.

**Extreme edge.** ZEISS, Sigray, Nikon, and Nordson sell complete inspection systems. The wedge is installed-base reuse plus tilted laminography geometry for flat packages, with a two-brand calibration and repeatability dossier. A software-only classifier would be cosmetic; the stage, geometry calibration, and cabinet-compatibility qualification are the product.

**Current demand proof.** Guangzhou Guangxin Packaging Substrate X-RAY inspection machine procurement (P5R2-CN-S01); Wuxi Shennan Circuits online X-ray inspection machine rebid (P5R2-CN-S02); NIST acquisition of ZEISS Xradia Versa XRM 730 system (P5R2-CN-S03); JCET proposed RMB 7.8 billion Shanghai Lingang high-end advanced-packaging factory (P5-CNREGEN-S07)

**Niche size by bottom-up arithmetic.** Screening case: 18 sites × $300k instrument + 18 × $60k annual calibration/service = $6.48M annualized niche. Named-site counting and buyer quotes must replace the assumptions.

**Competition.** Complete-cabinet competitors include ZEISS Versa XRM 730, Sigray Apex-class systems, Nikon XT H, and Nordson DAGE Quadra. They can add laminography modes or discount new cabinets. The thesis survives only if a retrofit produces useful 3D defect separation on at least two installed cabinet brands at a small fraction of cabinet-replacement cost.

**Technical path.** Current TRL 4. 2026-2027: build the tilted-stage and calibration stack on rented or partner cabinets. 2028: blinded coupon study and two-cabinet-brand port. 2029: paid evaluation at one CN substrate/package facility and one US failure-analysis laboratory; freeze the compatibility list and service procedure.

**Decisive experiment and budget.** $120,000. Use one rented and one partner 2D X-ray cabinet to image 100 blinded flat-package or substrate coupons with seeded 10-30 micrometre void, crack, bridge, and layer-offset defects. Compare against destructive sectioning or trusted reference CT. A lower public estimate exists, but no sub-$100k portfolio credit is awarded without signed facility access and project-specific quotes; use the conservative planning envelope.

**V1 capital and time.** 350000; 900000 Target 18-30 months from frozen interface to qualification-ready v1.

**Risks and kill criteria.** JCET's Lingang advanced-packaging factory has phase-one production-equipment completion targeted for H2 2028, while the official 2026-2030 national plan calls for decisive integrated-circuit breakthroughs. A 2030 launch enters the post-installation yield-learning and recurring failure-analysis cycle rather than trying to win the original cabinet order. Commercial kill: 2029-12-31

**US route.** Countable base case. Start with the named buyers, integrators, and qualification facilities in the accepted pack.

**China route.** Countable base case using locally supportable supply, calibration, qualification, and civilian buyer channels; screen counterparties and data flows before engagement.

**Optional side routes.** None required for the base case.

**Expansion.** Move from the first exact acceptance boundary into adjacent ratings, facilities, and recurring calibration, software, or qualification evidence only after the core product is paid for.

**Score and confidence.** 55.6/100; medium. Launch thesis: JCET's Lingang advanced-packaging factory has phase-one production-equipment completion targeted for H2 2028, while the official 2026-2030 national plan calls for decisive integrated-circuit breakthroughs. A 2030 launch enters the post-installation yield-learning and recurring failure-analysis cycle rather than trying to win the original cabinet order. Demand trigger: Yield ramp, package-mix expansion, and service retrofits after 2028 advanced-packaging tool installation, plus recurring US CHIPS metrology and failure-analysis demand. Revalidate the installed 2D-cabinet population and paid retrofit appetite in 2029.

**Citations.** [P5R2-CN-S01](https://chinabidding.mofcom.gov.cn/bidDetail/bidding/bulletin/202602/ff8080819a82040b019c98b9dc8a140c.html) [P5R2-CN-S02](https://en.chinabidding.mofcom.gov.cn/bidDetail/bidding/bulletin/202603/ff8080819a82040b019ce651241065d5.html) [P5R2-CN-S03](https://sam.gov/workspace/contract/opp/96effae327354fae8e9363b8b2a98541/view) [P5R2-CN-S04](https://www.sciencedirect.com/science/article/pii/S0026271425001076) [L15-001](https://pmc.ncbi.nlm.nih.gov/articles/PMC6631602/) [L15-005](https://api.crossref.org/works/10.3390/en17164105) [L15-017](https://spj.science.org/doi/pdf/10.34133/space.0268) [L15-025](https://www.mdpi.com/2673-3978/5/2/7)

**Founder fit (2/100; last).** The transferable fit is instrumentation, embedded control, electromagnetics, prototyping, and technical research. This note did not rescue demand, competition, capital, geography, or timing failures.

## 9. 300C-class mixed-signal instrumentation electronics platform (SiC/SOI) for superhot geothermal, downhole, and turbine environments (`P3R2-A-14`)

**Buyer and painful job.** Baker Hughes; SLB; Ormat/EGS pilots; FORGE awardees (Welltec, PetroQuip); DARPA/ARPA-E performers. Commercial high-temp ICs top out at 225C and the two incumbent lines are obsolete/exiting (CISSOID CHT last-time-buy; Honeywell legacy), while funded US programs now target 375C+ reservoirs and 800C ICs - existing buyers face a live sourcing gap between what they can buy and where they must operate.

**Product.** A qualified 300C mixed-signal instrumentation platform: SiC/SOI front-ends (ADC, mux, drivers), high-temp passives/packaging stack, and a reference logging/telemetry module - sold as chipset + qualified module to downhole/geothermal tool OEMs. Merged extensions: packaging-first qualification strategy - advanced die-attach/ceramic packaging is the documented true bottleneck (L15-005, L15-025) and leads the roadmap (from E-09); a 400C SiC-JFET instrumentation tier (NASA-heritage JFET front ends, partitioned hot-front-end + insulated-DSP architecture) as the roadmap step above 300C (from D-14).

**Cool frontier vision.** Native electronics for hot places: superhot geothermal, aero-engine and hypersonics instrumentation, Venus-class space missions, and close-coupled power-device gate drive.

**Extreme edge.** Mixed-signal circuits living for months at 300C where every commercial IC datasheet ends - the temperature frontier of electronics as a product.

**Current demand proof.** SUPERHOT: Stimulate Utilization of Plentiful Energy in Rocks through High-temperature Original Technologies (L15-029); DOE FORGE R&D Solicitation 2020-1: high-temperature zonal-isolation and geothermal tool awards (L15-027); DOE FORGE R&D Solicitation 2022-2: reservoir stimulation, high-temperature proppants, and packer tool awards (L15-028); Baker Hughes 2025 Digital Annual Report -- R&D spend, New Energy/geothermal bookings, and ORC power-plant equipment award (L15-040)

**Niche size by bottom-up arithmetic.** Screening case: 12 production lines × $600k subsystem + 12 × $90k annual service/qualification = $8.28M annualized niche. This is a transparent validation target, not a top-down forecast.

**Competition.** TI HT-line silicon (175-210C), CISSOID remnants (EU), in-house electronics at SLB/Halliburton (200C class), Ozark IC-class niche design houses; nobody selling a qualified 300C platform.

**Technical path.** Current TRL 4. 2026-27: 300C building-block circuits via university SiC/SOI runs (Arkansas/NASA-Glenn lineage methods); packaging/die-attach thermal-cycling study. 2028: 1,000-hour 300C soak of a mixed-signal front-end; present at FORGE/SUPERHOT community events; discovery with 10+ tool OEM engineering leads. 2029: field-representative logging-module prototype survives 500 hours in a heated test well/autoclave; LOI from one service company. Added roadmap steps: the 1,000h powered-soak artifact is the flagship qualification datum (from E-09); a FORGE-well field-trial step for the logging module follows in 2029 (from D-14). B-17's China chapter NOT imported: the atlas contains no named Chinese HT-electronics procurement (self-flagged inferential), so CN stays out of the demand base; revisit only if named evidence appears.

**Decisive experiment and budget.** $850,000. 2028: 300C/1,000-hour continuous operation of an 8-channel SiC/SOI acquisition front-end (ADC + mux + reference) with <1% drift, independently witnessed; thermal-cycling of the packaging stack to 500 cycles. The bounded test attacks the candidate's load-bearing technical and buyer-acceptance assumptions with explicit pass/kill thresholds.

**V1 capital and time.** 8000000; 18000000 Target 18-30 months from frozen interface to qualification-ready v1.

**Risks and kill criteria.** If superhot drilling slips, the 300C market stays program-funded; oilfield in-house teams may capture the niche for their own tools only. Commercial kill: 2034

**US route.** Countable base case. Start with the named buyers, integrators, and qualification facilities in the accepted pack.

**China route.** Not a countable base case in this round; do not depend on this route.

**Optional side routes.** None required for the base case.

**Expansion.** Move from the first exact acceptance boundary into adjacent ratings, facilities, and recurring calibration, software, or qualification evidence only after the core product is paid for.

**Score and confidence.** 54.6/100; high. Launch thesis: SUPERHOT/FORGE-funded drilling reaches wells hotter than any purchasable electronics by ~2030; CISSOID/Honeywell exit leaves buyers without a roadmap exactly as EGS scales on datacenter power demand. Demand trigger: Superhot-rock EGS drilling campaigns 2030-2034 seeded by ARPA-E SUPERHOT (awards from Nov 2025, L15-029) and DOE FORGE cohorts (L15-027/028), plus Baker Hughes-scale geothermal orders (L15-040) and SLB-Ormat commercial EGS expansion (L15-041); DARPA THERMAL Phase II completion ~2029 derisks 500C+ follow-on (L15-026).

**Citations.** [L15-001](https://pmc.ncbi.nlm.nih.gov/articles/PMC6631602/) [L15-004](https://ieeexplore.ieee.org/document/10496700/) [L15-009](https://pubs.aip.org/aip/adv/article/6/12/125119/991931/Prolonged-silicon-carbide-integrated-circuit) [L15-005](https://api.crossref.org/works/10.3390/en17164105) [L15-025](https://www.mdpi.com/2673-3978/5/2/7) [L15-029](https://arpa-e.energy.gov/programs-and-initiatives/view-all-programs/superhot) [L15-027](https://www.energy.gov/hgeo/geothermal/forge-rd) [L15-028](https://www.energy.gov/hgeo/geothermal/forge-rd)

**Founder fit (2/100; last).** The transferable fit is instrumentation, embedded control, electromagnetics, prototyping, and technical research. This note did not rescue demand, competition, capital, geography, or timing failures.

## 10. Precision GaN pump-driver and laser-power modules: nanosecond-class programmable current drive as a merchant subsystem for industrial and defense-adjacent laser OEMs (`P3R2-C-13`)

**Buyer and painful job.** nLIGHT and Coherent in the United States; US-entity-only primes on a strictly separated line; and Han's Laser in China only after fresh official-list and ownership screening. Raycus is excluded as a buyer and remains market-timing context only. US: laser-diode drive remains an active research area (GaN pulsed drivers, LLC modulation, ps-resolution control - L12-025/026/027), so every OEM carries driver NRE while A&D laser demand accelerates (nLIGHT A&D $175.3M, L12-033). CN: the fiber-laser price war (high-power revenue -6.6% on +30% units at Han's, L12-037) forces cost-down and outsourcing of non-core electronics while export volumes boom (Raycus handheld +66%, L12-038).

**Product.** A qualified driver family: multi-channel GaN pump drivers (kA-class aggregate, ns edge control, integrated safety interlocks) plus TMI-aware pump-modulation firmware hooks (L12-016/017/018), sold as modules/reference designs to laser OEMs; separate US-only line for directed-energy primes. Imported differentiator (from merged A-18): integrated diode-health telemetry (droop, threshold-drift tracking) in every driver; TMI-aware pump-modulation firmware remains the durable moat.

**Cool frontier vision.** The power-electronics backbone of photonics: pump drive, pulse shaping, and energy recovery for industrial lasers, DEW, medical lasers, and CPO laser sources - electronics margin extracted from a photonics industry that undervalues it.

**Extreme edge.** Kiloamp-aggregate current steering with nanosecond programmability and functional-safety interlocks in a palm-size module.

**Current demand proof.** nLIGHT, Inc. Form 10-K FY2025 (Annual Report) (L12-033); Coherent Corp. 2025 Analyst and Investor Day (L12-036); nLIGHT Awarded $627 Million Joint Laser Weapon System (JLWS) Contract (L12-032); Han's Laser Technology Industry Group 2025 Annual Report (L12-037)

**Niche size by bottom-up arithmetic.** Screening case: 12 production lines × $600k subsystem + 12 × $90k annual service/qualification = $8.28M annualized niche. This is a transparent validation target, not a top-down forecast.

**Competition.** In-house driver teams at IPG/Raycus/Han's (L12-034/051/037), analog-semi reference designs (TI/ADI-class), 1-2 module startups. Moat: qualified reliability data + TMI-aware firmware integration.

**Technical path.** Current TRL 4. 2026-27: driver research with a university fiber-laser lab; demonstrate TMI-mitigation via pump modulation; publish + patents. 2027: decisive multi-channel demo (below). 2028: evaluation units with one US OEM; CN OEM cost/performance benchmark via academic partner. 2029: design-in LOIs both markets; export-control partition review (commercial vs DEW line). FIX gate (2028): OEM buy-vs-build discovery must convert to two PAID evaluations (one US, one CN commercial); if OEM appetite fails, fold the driver line into P3R2-D-10 as its power stage and stop standalone.

**Decisive experiment and budget.** $72,000. Cross-market make-versus-buy and paid-evaluation gate (5 months; $72,000). Pre-register: Name prospects, freeze interface and claimed telemetry/TMI value, minimum $25,000 evaluation, incompatible-control rule, and no-credit rules for host-system spending. Pass: Two paid evaluations >=$25,000 each, one per market; Both accept a merchant electrical interface; US controls remain compatible with a fully separated screened CN line. Kill: Fewer than two paid evaluations; OEMs keep drivers as core IP; Required cross-market controls make the economics nonviable. Budget: interface bom and safety plan $12,000, tmi and health data room $10,000, twelve oem workshops $18,000, export and counterparty screening $12,000, paid evaluation contracting $10,000, independent make buy analysis $5,000, contingency $5,000. The make-versus-buy boundary and lawful two-market architecture are load-bearing; failure kills the standalone module before a costly build.

**V1 capital and time.** 5000000; 12000000 Target 18-30 months from frozen interface to qualification-ready v1.

**Risks and kill criteria.** Export-control separability is manageable but sharp-edged: commercial drivers are low-sensitivity; any DEW-affiliated line must be strictly US-entity with no CN ownership links, or US primes will not buy - structure two entities from day one, accept that a forced choice may drop one market (then reassign batch). Chinese OEMs may refuse external drivers (NIH culture) - test willingness in 2028 discovery. FIX: the US(DEW)/commercial two-entity partition is a day-one structural requirement, not a contingency. Commercial kill: 2034

**US route.** Countable base case. Start with the named buyers, integrators, and qualification facilities in the accepted pack.

**China route.** Countable base case using locally supportable supply, calibration, qualification, and civilian buyer channels; screen counterparties and data flows before engagement.

**Optional side routes.** JP only after the primary route proves repeatability.

**Expansion.** Move from the first exact acceptance boundary into adjacent ratings, facilities, and recurring calibration, software, or qualification evidence only after the core product is paid for.

**Score and confidence.** 54.2/100; medium. Launch thesis: By 2030 Chinese OEMs are margin-starved commodity manufacturers hungry for cost-down subsystems, and US OEMs are scaling DEW/industrial output - both need drive electronics they under-invest in; a specialist enters with cross-market volume economics no in-house team matches. Demand trigger: US: JLWS-generation directed-energy fielding programs scaling 2030-2034 ($847M ceiling structure today, L12-031/032 - US-entity line only) plus industrial/CPO laser source growth (L12-036). CN: continued export-driven handheld/cutting volume growth and consolidation-driven outsourcing (L12-037/038). CN demand chapter (merged from B-19): the fiber-laser price war is pushing Han's/Raycus up-market into ultrafast/UV drilling for AI-server advanced PCB/substrate capacity (L12-037/038) - exactly the platforms that need qualified precision drivers.

**Citations.** [L12-025](https://onlinelibrary.wiley.com/doi/10.1002/cta.70354) [L12-026](https://doi.org/10.3390/electronics15010210) [L12-027](https://www.mdpi.com/2304-6732/9/9/652) [L12-016](https://doi.org/10.3390/mi15101237) [L12-017](https://pubs.aip.org/aip/app/article/9/6/066114/3299153/Theory-of-transverse-mode-instability-in-fiber) [L12-033](https://www.sec.gov/Archives/edgar/data/1124796/000112479626000012/lasr-20251231.htm) [L12-036](https://www.coherent.com/news/press-releases/2025-analyst-investor-day) [L12-031](https://defensescoop.com/2026/07/09/pentagon-joint-laser-weapon-system-defeat-drone-swarms/)

**Founder fit (2/100; last).** The transferable fit is instrumentation, embedded control, electromagnetics, prototyping, and technical research. This note did not rescue demand, competition, capital, geography, or timing failures.

## 11. Thermal-shock-tolerant printed-circuit heat exchangers (PCHE): merchant diffusion-bonded recuperators for sCO2 power, heat pumps, and hydrogen precooling (`P3R2-C-08`)

**Buyer and painful job.** GTI/SwRI/GE Vernova STEP-lineage sCO2 programs (US); TerraPower-class advanced-reactor BOP chains (US); A-CAES/heat-pump developers (DOE LPO-backed) (US); CNNC/CAS-IET sCO2 projects and steel-sintering retrofit fleet (CN, via licensed entity); TC Energy-Hanwha pipeline waste-heat lineage (US/KR, L04-047, from E-08). US: PCHE recuperators are the most-cited sCO2 bottleneck; pilot integrators build bespoke units in-house (L04-039, L04-029, L04-004/005/006), and advanced-reactor BOP components come from a tiny qualified-vendor pool (L04-045). CN: China commercialized waste-heat sCO2 first (Chaotan One 30 MW, L04-048/051) with a state-media-estimated ~300-unit steel-sintering retrofit fleet (single-source figure, flagged) and CAS-IET actively researching thermal-cycling-tolerant PCHEs (L04-029) - i.e., no merchant supplier meets the rapid-cycling spec in either market.

**Product.** Diffusion-bonded microchannel recuperators engineered for >20 C/min thermal transients (the L04-029 target), with creep/fatigue qualification per ASTM E139 (L04-112) and Sandia-documented materials selections (L04-113); sold as certified cores to cycle OEMs. Merged extensions: sold as catalog frames with published delivery times, not EPC subprojects (from A-12); graded-channel cores with compliant headers distributing transient thermal strain away from bond planes (from B-07); the acceptance-test protocol positioned to substitute for the missing sCO2 performance-test standard (from E-08).

**Cool frontier vision.** The Intel of high-temperature compact heat exchange: standard cores across sCO2 power, industrial heat pumps, thermal storage, hydrogen liquefaction precooling, and fusion-blanket-adjacent heat trains.

**Extreme edge.** Surviving 500-700 C, 20+ MPa, and >20 C/min transients for 20-year life in a bonded microchannel core - simultaneous creep, fatigue, and corrosion frontier (L04-113).

**Current demand proof.** STEP Demo pilot plant achieves full operational conditions for Phase 1 of testing (L04-039); TerraPower Announces Contract Awards for Natrium Vendors (L04-045); LPO Announces Conditional Commitment for Long Duration Compressed Air Energy Storage to Enable a Diverse and Reliable Generation Mix (L04-114); Chaotan One: World's 1st supercritical CO2 power unit starts in China (L04-048)

**Niche size by bottom-up arithmetic.** Screening case: 12 production lines × $600k subsystem + 12 × $90k annual service/qualification = $8.28M annualized niche. This is a transparent validation target, not a top-down forecast.

**Competition.** Heatric/VPE-class incumbent PCHE makers (industry names, not in atlas - flag for P4), OEM in-house shops (L04-039), Chinese institute-affiliated fabricators (L04-029). Differentiation: qualified rapid-transient tolerance + code documentation, not capacity.

**Technical path.** Current TRL 5. 2026-27: materials/bonding research via university + national-lab user facility; subscale core fabrication; publish cycling-durability data addressing the L04-029 gap. 2028: decisive cycling experiment (below); begin ASME code-case conversations. 2029: supply LOIs with one US cycle developer and one CN licensee for the retrofit market; refresh China retrofit-fleet economics from eligible sources (current figure is single-source state media). Added task (from E-08): pre-commitment triangulation of the CN retrofit TAM from eligible sources - the RMB100bn-class figure stays single-source-flagged until then. Structural pairing (adjudication): develop jointly with P3R2-C-19 as one high-temperature-components company.

**Decisive experiment and budget.** $65,000. Incumbent-limit and buyer-funded qualification gate (5 months; $65,000). Pre-register: Freeze VPE/Heatric comparison, full-core transient envelope, required measured incumbent failure, funding threshold, and no-credit rule for missing public datasheets. Pass: Buyer provides a measured incumbent transient limit; Buyer names a required target the incumbent cannot meet; Paid development agreement funds the subsequent $400k-$600k core program. Kill: No measured incumbent gap; Buyer will not fund development; Target is already inside incumbent capability. Budget: transient requirement definition $12,000, oem epc workshops $14,000, incumbent gap benchmark $10,000, paid development contracting $8,000, bonder and test quotes $8,000, fto and code review $9,000, independent review $2,000, contingency $2,000. A new PCHE company cannot exist without a buyer-proven incumbent failure and cost sharing. The test resolves both.

**V1 capital and time.** 15000000; 35000000 Target 18-30 months from frozen interface to qualification-ready v1.

**Risks and kill criteria.** Export separability: heat exchangers for CN steel/waste-heat retrofits are low-sensitivity; nuclear-qualified US product line kept in US entity (no CN transfer). Risks: sCO2 commercialization slips (kill if no >=10MW-class merchant order by end-2033); Chinese institutes verticalize; manufacturing capex heavier than electronics seeds. All 2026 project schedules must be re-verified 2029. Commercial kill: 2034

**US route.** Countable base case. Start with the named buyers, integrators, and qualification facilities in the accepted pack.

**China route.** Countable base case using locally supportable supply, calibration, qualification, and civilian buyer channels; screen counterparties and data flows before engagement.

**Optional side routes.** None required for the base case.

**Expansion.** Move from the first exact acceptance boundary into adjacent ratings, facilities, and recurring calibration, software, or qualification evidence only after the core product is paid for.

**Score and confidence.** 51.6/100; medium. Launch thesis: US pilots (STEP scale-up, NET-Power lineage, advanced reactors post-NRC Part 53) and China's first-set-designated sCO2 rollouts both hit equipment-ordering phases 2030-2034; the recuperator is the choke-point component with documented unresolved specs, ideal for a focused merchant entrant. Demand trigger: US: advanced-reactor BOP procurement following NRC Part 53 (effective 2026-04, L04-031) and post-STEP commercial sCO2 units (L04-039); DOE LPO-backed long-duration storage builds (L04-114). CN: CNNC Xinjiang molten-salt+sCO2 completion (~2028, L04-051) triggering 'first-set' follow-on procurement and steel-sintering retrofit wave.

**Citations.** [L04-004](https://www.sciencedirect.com/science/article/abs/pii/S1359431125034787) [L04-005](https://www.tandfonline.com/doi/full/10.1080/01457632.2022.2164683) [L04-006](https://www.tandfonline.com/doi/full/10.1080/01457632.2022.2140640) [L04-101](https://asmedigitalcollection.asme.org/energyresources/article/145/12/121705/1166577/) [L04-109](https://pubs.acs.org/doi/10.1021/acsomega.2c05531) [L04-039](https://www.swri.org/newsroom/press-releases/step-demo-pilot-plant-achieves-full-operational-conditions-phase-1-of-testing) [L04-045](https://www.terrapower.com/terrapower-announces-contract-awards-for-natrium-vendors) [L04-114](https://www.energy.gov/edf/articles/lpo-announces-conditional-commitment-long-duration-compressed-air-energy-storage)

**Founder fit (2/100; last).** The transferable fit is instrumentation, embedded control, electromagnetics, prototyping, and technical research. This note did not rescue demand, competition, capital, geography, or timing failures.

## 12. Sealed negative-pressure (subatmospheric) water/low-GWP two-phase cold-plate loop for >2 kW/chip Chinese AI racks - leak-safe by physics (air leaks in, coolant never leaks out), PFAS-free by design (`P3R2-B-01`)

**Buyer and painful job.** Envicool (Shenzhen CDU/thermal vendor, one of 7 vendors building Google Deschutes-class CDUs, L14-043); Alibaba-class hyperscale operators already running HVDC datacenters (L02-048, L02-049); Chinese colocation operators facing GB 40879 PUE caps (L14-035). Chinese operators must hit PUE <=1.25/1.2 caps (GB 40879 revision, L14-035) and 'high-efficiency cooling' policy direction (Guo-Neng-Fa-Ke-Ji [2026] No.34, L14-036 - NB: primary text has NO 100%-liquid-cooling mandate) while chip TDP heads to 3-5 kW and 800-1,000 W/cm2 (L14-010), beyond single-phase cold-plate margins; two-phase alternatives historically depended on discontinued PFAS dielectric fluids (two-phase literature L14-001/002/003/029).

**Product.** A rack-level two-phase loop that runs water or low-GWP fluid below atmospheric pressure through microchannel evaporator cold plates (mechanism: saturation temperature tuned via vacuum setpoint; latent heat absorbs >2 kW/chip at near-isothermal junction; any seal failure leaks air inward, detected by vacuum decay, instead of coolant onto boards). Ships as evaporator plates + manifold + compact vacuum-condenser CDU compatible with T/CIEP 0263-2025 interfaces (L14-039).

**Cool frontier vision.** Become the default leak-safe two-phase thermal architecture for East-Asian AI infrastructure, then extend the same negative-pressure loop to power electronics, EV fast-charge cabinets and aerospace power-dense converters.

**Extreme edge.** Same loop physics scales to 1,000 W/cm2-class WBG power modules and directed-energy thermal buses.

**Current demand proof.** Project Deschutes: A 2MW Coolant Distribution Unit (CDU) specification (L14-043); 2026年南网电算工程公司数据中心液冷技术及能效调优公开招标项目 (2026 Southern Power Grid Computing Technology Digital Engineering (Guangdong) Data Center Liquid Cooling Technology and Energy Efficiency Optimization Public Tender) (P3R2-B-01-S03); 2.07亿！国产化万卡智算大单，阿里拿下 (RMB 207M: Alibaba wins the domestic 10,000-card intelligent computing pool order) — China Telecom Guangdong Phase 2 tender (P3R2-B-01-S04)

**Niche size by bottom-up arithmetic.** Screening case: 15 projects × $500k deployment + 15 × $75k annual qualification/support = $8.63M annualized niche. Treat project count and price as falsifiable planning inputs.

**Competition.** Envicool and other Chinese CDU incumbents (7+ vendors already building to Deschutes spec, L14-043) will dominate single-phase; ITRI-fed Taiwan ODM two-phase lines (L14-053) are the closest technical rival; expect at least one Chinese two-phase startup. Differentiator must be the negative-pressure leak-safety mechanism plus fluid-supply independence.

**Technical path.** Current TRL 4. 2026-2027: university/lab-hosted loop testbed; replicate ITRI-class low-pressure results (L14-053 reports 2.4 kW/chip) on a 1 kW simulated die; file 2-3 core patents (vacuum-setpoint control, inward-leak detection, manifold blind-mate). 2027-2028: joint evaluation agreements (pre-company MOUs) with one Chinese thermal vendor and one TW/JP ODM lab; publish peer-reviewed validation. 2028-2029: 20-50 kW rack demonstrator with a partner lab in HK/Shenzhen; customer discovery with 10+ Chinese operators/ODM thermal teams on GB 40879 compliance economics; qualify supply chain for pumps/vacuum hardware.

**Decisive experiment and budget.** $55,000. Incumbent teardown and paid leak-direction requirement gate (4 months; $55,000). Pre-register: Freeze Envicool comparison, inward-leak definition, three buyer targets, mandatory paid-criterion evidence, and incumbent-addability rule. Pass: One buyer states inward-leak behavior is mandatory and unmet; Buyer signs paid evaluation; Incumbent cannot add feature without material redesign. Kill: Incumbent already controls subatmospheric pressure; No buyer prices leak direction; Feature is an easy incumbent firmware/control addition. Budget: incumbent material and teardown $10,000, function map $8,000, three cn buyer workshops $12,000, standards and service analysis $8,000, paid evaluation contracting $8,000, ip and licensing counsel $5,000, independent review $2,000, contingency $2,000. The residual wedge is commercial, not two-phase feasibility. This test kills it directly.

**V1 capital and time.** 3000000; 8000000 Target 18-30 months from frozen interface to qualification-ready v1.

**Risks and kill criteria.** Foreign-founder access: direct sales to Chinese hyperscalers unrealistic; route is IP licensing/joint development with a Chinese thermal vendor (Envicool-class) or ODM design-in via HK entity. Risk that Chinese incumbents productize two-phase in-house before 2030; mitigated by patent position and the documented non-convergence of two-phase architectures. Commercial kill: 2034-06-30: kill if no Chinese or Taiwanese ODM/thermal-vendor paid pilot (>=100 kW deployment) by mid-2034.

**US route.** Not a countable base case in this round; do not depend on this route.

**China route.** Countable base case using locally supportable supply, calibration, qualification, and civilian buyer channels; screen counterparties and data flows before engagement.

**Optional side routes.** TW; JP only after the primary route proves repeatability.

**Expansion.** Move from the first exact acceptance boundary into adjacent ratings, facilities, and recurring calibration, software, or qualification evidence only after the core product is paid for.

**Score and confidence.** 51.0/100; medium. Launch thesis: Single-phase cold plates commoditize by 2030 in China, but >2 kW/chip parts push past single-phase margins exactly as hub-node PUE caps tighten; two-phase is still non-converged in 2026 (four competing architectures, L12-021-class CPO thermal debate; L14-001/002/003) so a 2030 entrant with a leak-safe niche is early, not late. Demand trigger: Named: (a) GB 40879 revised PUE caps (<=1.25 new large DCs, <=1.2 national hub nodes) enforced through 2030-2034 buildout (L14-035); (b) East-Data-West-Computing (Dong-Shu-Xi-Suan) hub-node datacenter parks explicitly referenced as active buildout in accepted CN sources (L02-049); (c) national AI-energy action plan cooling-efficiency line (L14-036).

**Citations.** [L14-001](https://www.sciencedirect.com/science/article/abs/pii/S0017931024014030) [L14-002](https://link.springer.com/article/10.1007/s10973-025-14006-0) [L14-003](https://www.sciencedirect.com/science/article/abs/pii/S1364032125006677) [L14-006](https://www.mdpi.com/2075-5309/15/6/905) [L14-009](https://www.sciencedirect.com/science/article/abs/pii/S0017931025004016) [L14-043](https://arpa-e.energy.gov/sites/default/files/2026-01/Day1_06b_Google_Kabbani.pdf) [L14-035](https://std.samr.gov.cn/gb/search/gbDetailed?id=2E4DD4D8E2E84A4BE06397BE0A0AE354) [L14-036](https://www.nea.gov.cn/20260508/4dae97ca01d348e4871bb8654be34b3a/c.html)

**Founder fit (2/100; last).** The transferable fit is instrumentation, embedded control, electromagnetics, prototyping, and technical research. This note did not rescue demand, competition, capital, geography, or timing failures.
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

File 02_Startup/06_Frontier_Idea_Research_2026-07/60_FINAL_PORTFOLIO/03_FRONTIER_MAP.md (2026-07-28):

# Frontier map

The portfolio is organized by who owns the painful job, then connected by reusable physics and product boundaries.

## Industrial

- `P3R2-D-02` — Reel-to-reel contactless REBCO tape quality metrology (Hall-array critical-current mapping + delamination screening) sold to tape vendors and magnet builders as certified acceptance instrumentation. (L03, diagnostic_test).
- `P3R2-C-22` — Electrolyzer stack degradation-emulation and bankability test systems: programmable ripple/intermittency benches that turn stack warranties into measurable engineering (L11, diagnostic_test).
- `P3R2-F-01` — Solid-state microsecond impedance-matching engines (switched SiC/PIN capacitor arrays replacing motorized vacuum-capacitor matchboxes) for pulsed and tailored-waveform RF plasma tools (L06, process_output).
- `P5R2-CN-01` — Retrofit X-ray computed-laminography kit for advanced-packaging failure analysis (L06, diagnostic_test).
- `P3R2-A-14` — 300C-class mixed-signal instrumentation electronics platform (SiC/SOI) for superhot geothermal, downhole, and turbine environments (L15, process_output).
- `P3R2-C-13` — Precision GaN pump-driver and laser-power modules: nanosecond-class programmable current drive as a merchant subsystem for industrial and defense-adjacent laser OEMs (L12, process_output).
- `P3R2-C-08` — Thermal-shock-tolerant printed-circuit heat exchangers (PCHE): merchant diffusion-bonded recuperators for sCO2 power, heat pumps, and hydrogen precooling (L04, process_output).
- `P5R2-CN-03` — Field-deployable industrial high-temperature heat-pump commissioning and measurement-and-verification island (L04, diagnostic_test).
- `P3R2-G-01` — Closed-loop UHV chamber conditioning and acceptance-certification systems for China's big-science vacuum supply chain: instrumented vacuum-firing/bakeout stations with measured hydrogen-outgassing endpoints, integrated rate-of-rise/leak/RGA acceptance metrology, and tamper-evident per-chamber certification - sold as equipment plus recurring calibration to the China-registered fabricators who alone may bid HEPS/CEPC-class chamber tenders. (L07, process_output).
- `P3R2-A-10` — Vendor-neutral ion-energy-distribution metrology + tailored-waveform bias control retrofit for plasma etch chambers (L06, process_output).
- `P3R2-F-23` — PEM electrolyzer 'protective operating envelope' controllers with warranty-grade black-box logging: embedded plant hardware that shapes current/OCV stress and produces bankable degradation evidence (L11, process_output).
- `P3R2-F-03` — High-speed permanent-magnet turbo-generator + power-converter 'electrical cartridge' (0.3-20 MW) for waste-heat sCO2 and geothermal/ORC power blocks (L04, process_output).

## Scientific Big Physics

- `P3R2-D-01` — Merchant quench-detection-and-protection subsystem for REBCO/HTS magnets: co-wound distributed fiber-optic sensing plus sub-millisecond active energy extraction, sold with a qualification dossier to fusion companies and national labs. (L03, scientific_system).
- `P5-USSCI2-S01` — Qualified diamond transmission-dynode membrane and integration cartridge for hybrid MCP-PMTs used in EIC-class photon detectors (L13, process_output).
- `P3R2-E-04` — High-density cryogenic interconnect loader with co-packaged 4K readout front-end (superconducting flex harness + cryo-CMOS multiplexing + cryo-LNA), breaking the 256-channel-per-loader wall for quantum computers. (L13, scientific_system).
- `P3R2-F-02` — Superconducting-magnet electrical balance-of-plant platform: standardized precision drive-and-dump skids (10 ppm-class high-current DC converters + energy-extraction/dump units + current leads + busbars) (L03, scientific_system).
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

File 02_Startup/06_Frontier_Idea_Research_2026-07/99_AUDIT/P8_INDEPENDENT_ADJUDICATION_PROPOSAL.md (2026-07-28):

# P8 independent substantive adjudication proposal

**Verdict: PASS**  
**Date:** 2026-07-14  
**Runtime model / effort:** `unknown` / `unknown` (not exposed; not inferred)

This independent proposal does not modify the frozen selection, shared state, routing log, `FABLE_ADJUDICATION.md`, or `FINAL_AUDIT.md`.
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

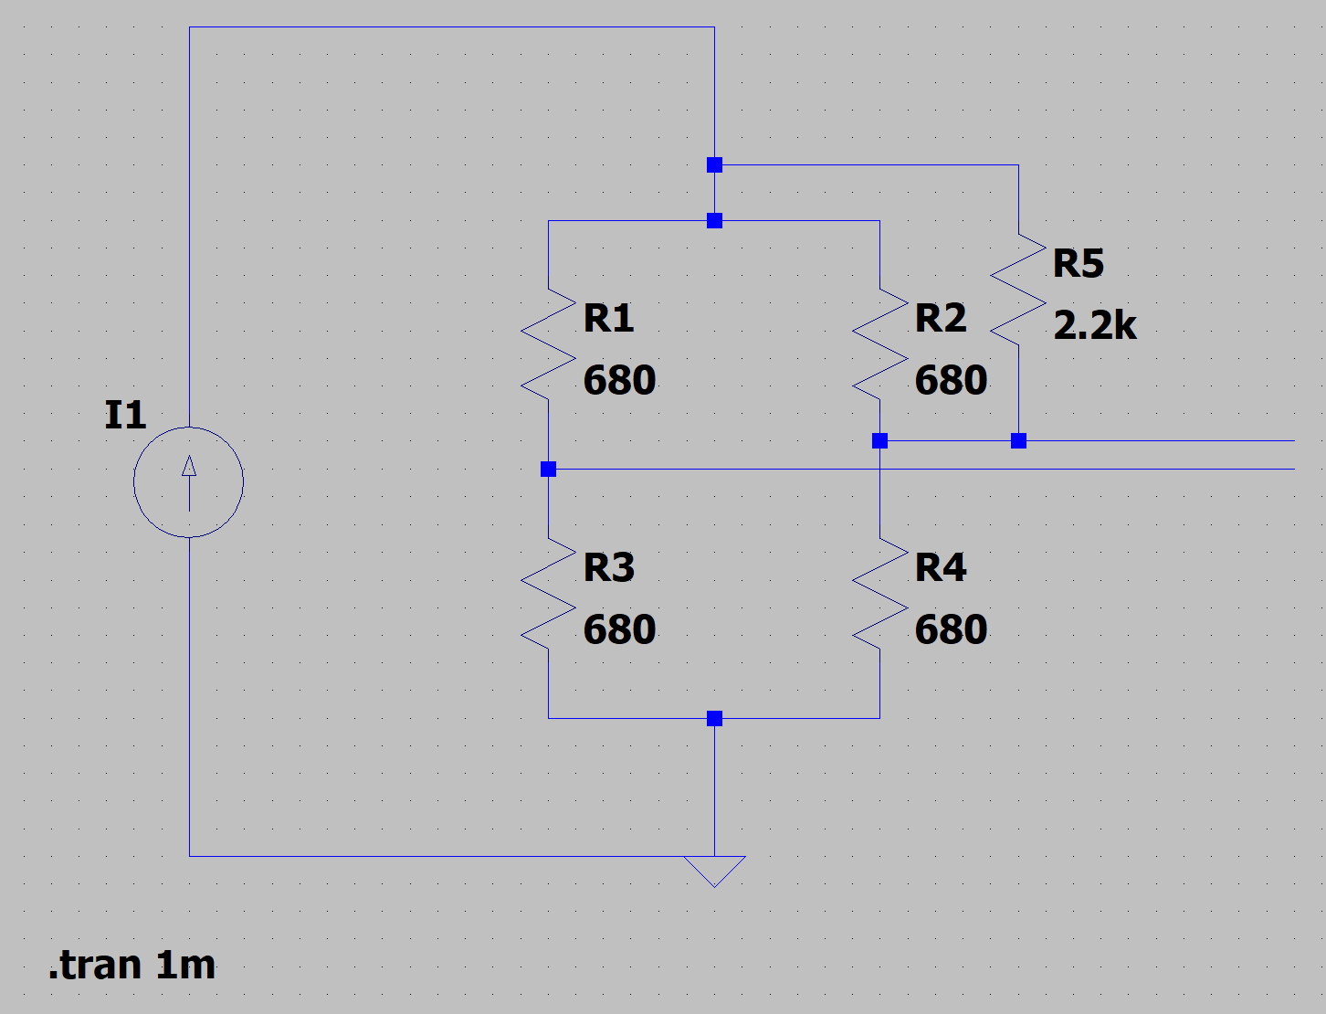
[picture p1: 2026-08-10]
01_PhD_Research/02_HSX_Hall_Sensor_Readout/analysis/figures/2026-07-15_emulator_bridge_schematic.png

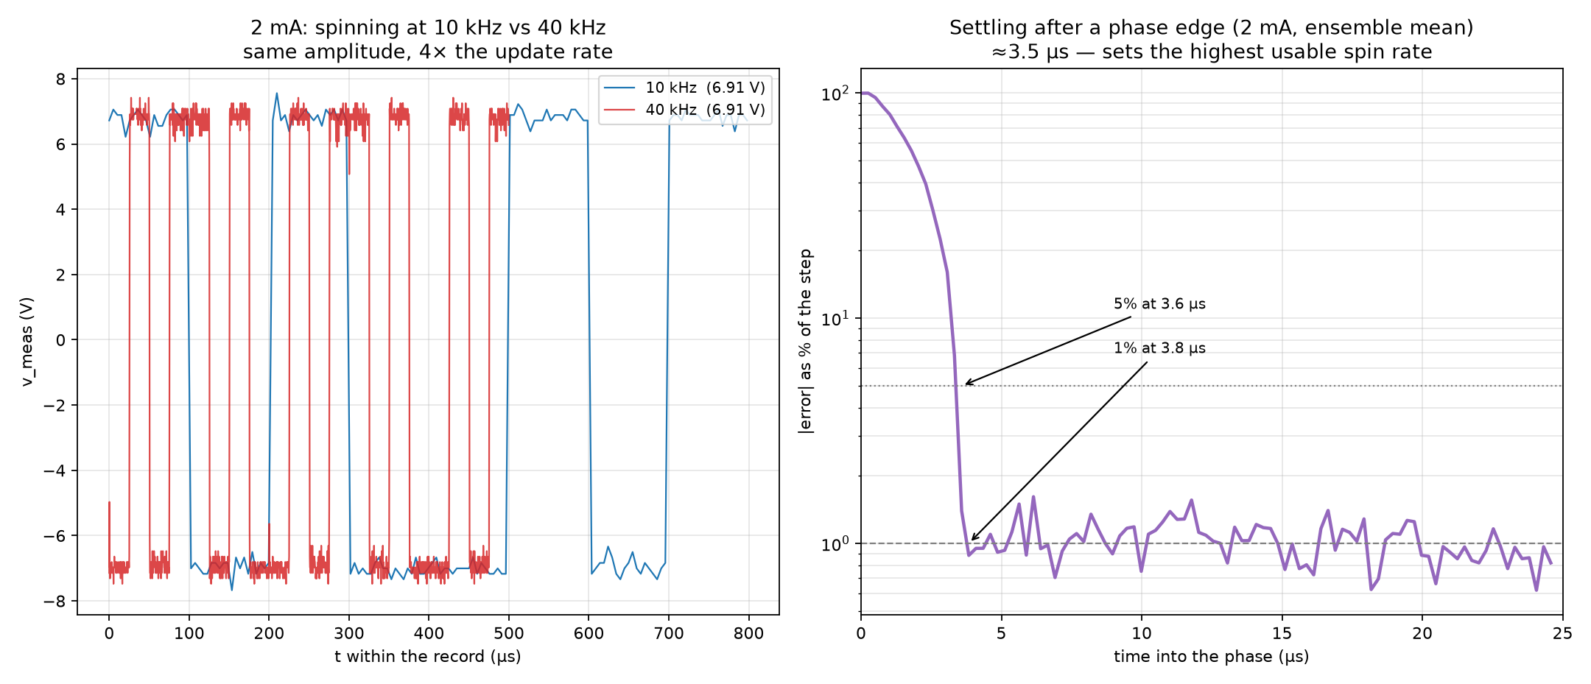
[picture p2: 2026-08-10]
01_PhD_Research/02_HSX_Hall_Sensor_Readout/analysis/figures/2026-07-10_spin_frequency.png

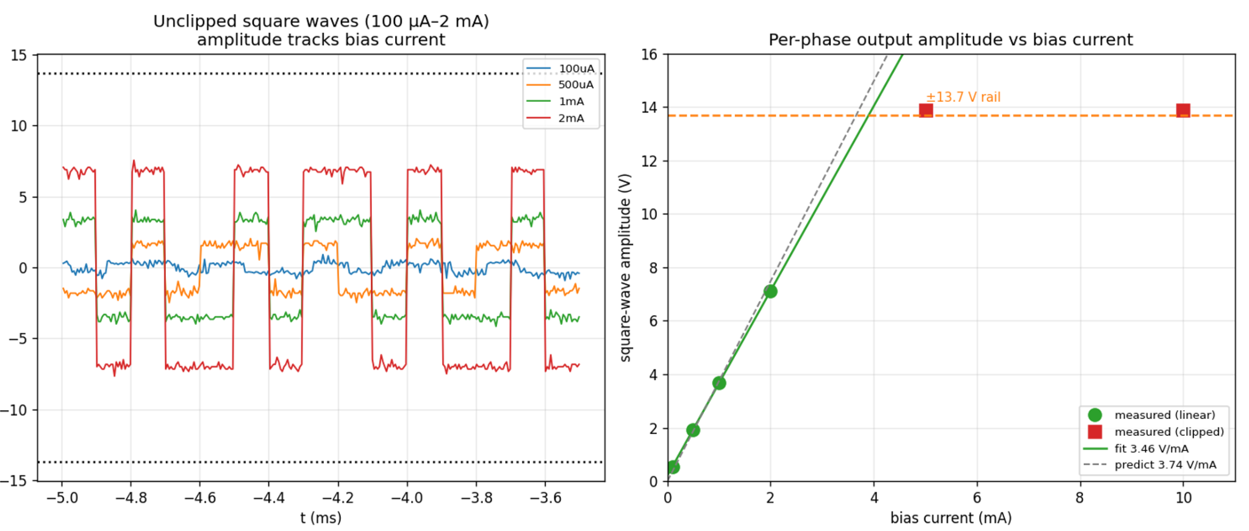
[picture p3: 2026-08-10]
01_PhD_Research/02_HSX_Hall_Sensor_Readout/analysis/figures/2026-07-15_bias_sweep.png

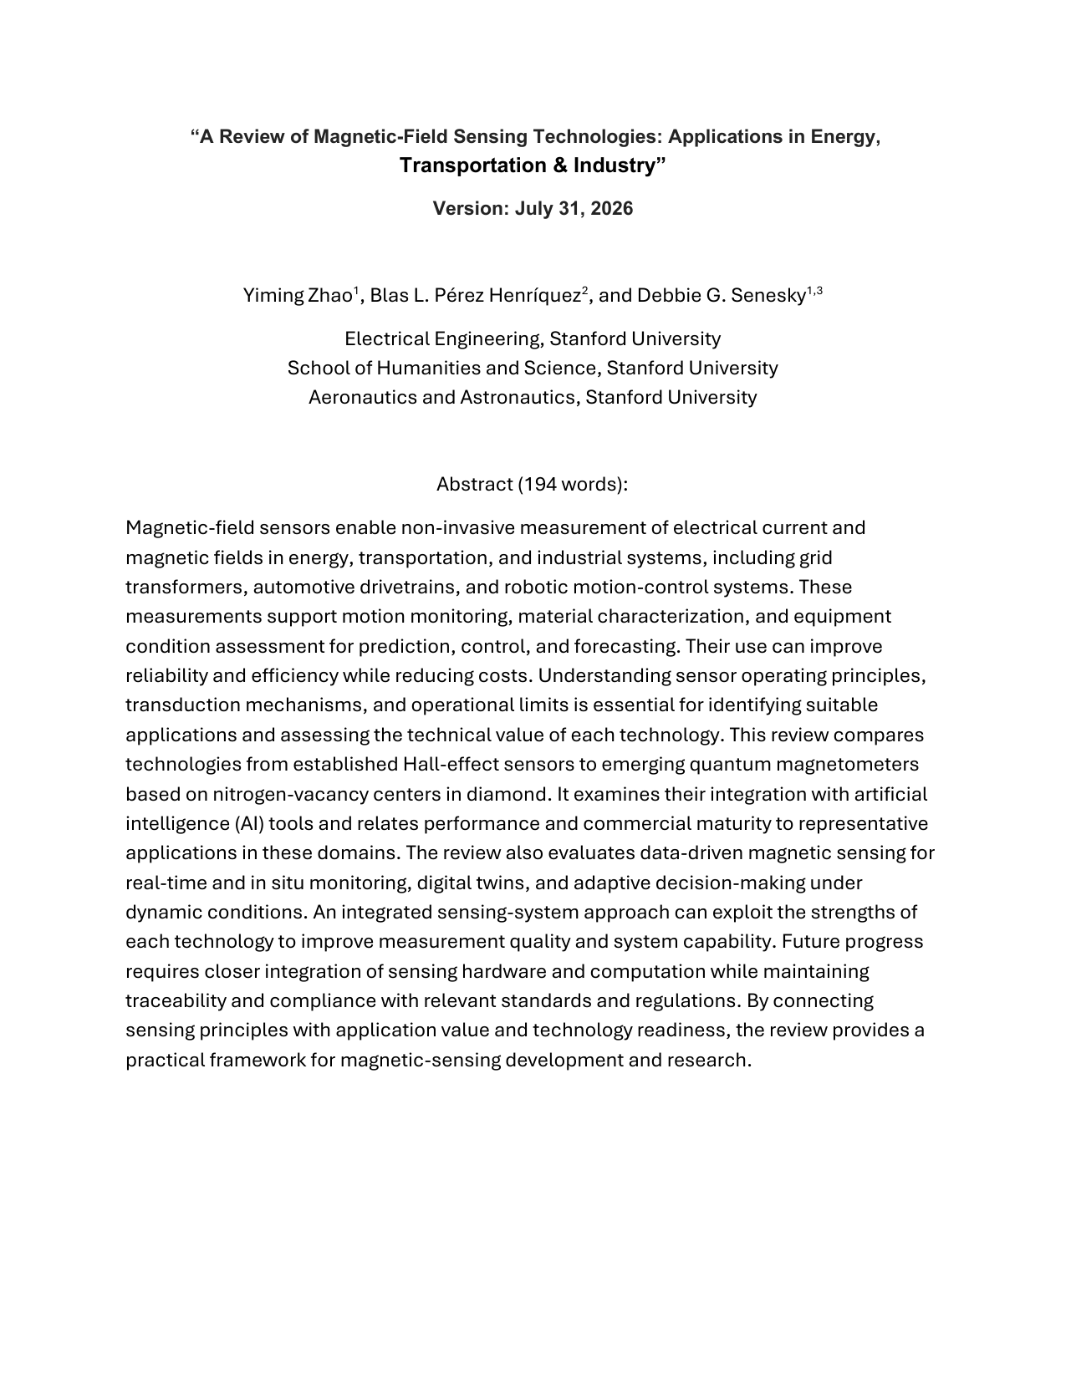
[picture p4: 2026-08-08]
01_PhD_Research/04_Magnetic_Sensor_Review_Sensors2026/advisor_review/advisor_abstract/render_final/page-1.png

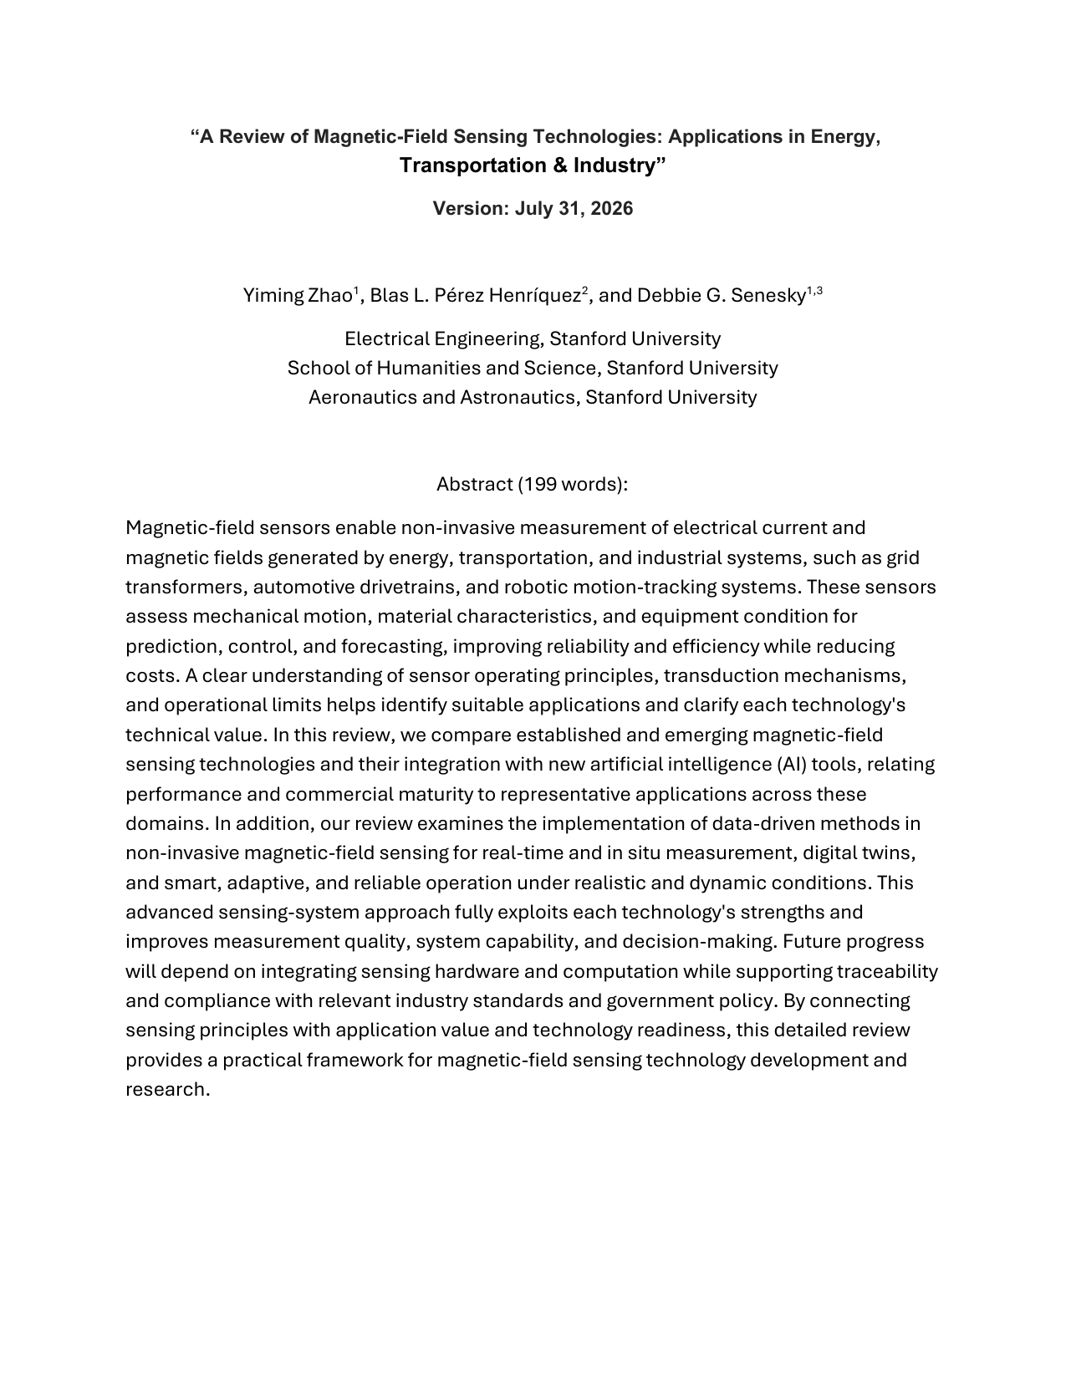
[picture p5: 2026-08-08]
01_PhD_Research/04_Magnetic_Sensor_Review_Sensors2026/advisor_review/advisor_abstract/render_advisor_close/page-1.png

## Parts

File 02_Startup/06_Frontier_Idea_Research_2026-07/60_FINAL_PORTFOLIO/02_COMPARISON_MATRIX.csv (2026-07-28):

idea_id | rank | concept | primary_lane | sector_cluster | product_role | primary_customer_archetype | primary_market | current_trl | precompany_validation_by_2029 | launch_2030_fit | timing_window | first_experiment_budget_usd | us_beachhead | china_beachhead | secondary_markets | asia_beachhead | score_total | confidence
P3R2-D-02 | 1 | Reel-to-reel contactless REBCO tape quality metrology (Hall-array critical-current mapping + delamination screening) sold to tape vendors and magnet builders as certified acceptance instrumentation. | L03 | superconductor manufacturing metrology | diagnostic_test | industrial | US+CN | 4 | True | True | Tape vendors may bundle 'good-enough' in-house QC data; if one instrument maker partners exclusively with the largest vendor, the neutral-referee position is lost. | 120000 | True | True | JP;KR | True | 65.6 | medium
P3R2-C-22 | 2 | Electrolyzer stack degradation-emulation and bankability test systems: programmable ripple/intermittency benches that turn stack warranties into measurable engineering | L11 | electrochemical test | diagnostic_test | industrial | US+CN | 5 | True | True | Hydrogen demand volatility caps growth (order books shrinking now, L11-047/048) - but the seed monetizes uncertainty itself; worst case is a slow niche, not a zero. Export separability excellent (test equipment; CN entity straightforward). Kill if neither market yields bench sales nor paid campaigns by end-2033. | 250000 | True | True | JP;KR | True | 64.6 | medium
P3R2-D-01 | 3 | Merchant quench-detection-and-protection subsystem for REBCO/HTS magnets: co-wound distributed fiber-optic sensing plus sub-millisecond active energy extraction, sold with a qualification dossier to fusion companies and national labs. | L03 | fusion/big-science superconducting magnets | scientific_system | scientific_big_physics | US | 3 | True | True | If no-insulation windings prove fully sufficient at pilot-plant scale, the detection problem shrinks; if a magnet builder open-sources a good solution, differentiation collapses to service/qualification. | 250000 | True | False |  | False | 62.8 | low
P3R2-F-01 | 4 | Solid-state microsecond impedance-matching engines (switched SiC/PIN capacitor arrays replacing motorized vacuum-capacitor matchboxes) for pulsed and tailored-waveform RF plasma tools | L06 | semiconductor_subsystems | process_output | industrial | US+CN | 4 | True | True | If AE/MKS ship integrated solid-state matching as a standard feature before a merchant module gains a design win, the socket closes; mitigated by selling to the same incumbents and to CN OEMs the US incumbents cannot serve. | 250000 | True | True | KR | True | 59.8 | medium
P3R2-C-01 | 5 | 800-VDC rack power-path protection: integrated solid-state breaker + precharge/inrush control + insulation monitoring + hot-swap sequencing unit for AI racks and power sidecars | L02 | AI datacenter power | infrastructure | infrastructure_utility_transport | US+CN | 4 | True | True | Export-control separability: good - protection electronics are conventional industrial power electronics (largely EAR99); China variant can use domestic GaN/SiC (Innoscience, L02-050) built by a licensed CN entity while the US entity serves OCP customers; main risks are hyperscaler vertical integration, UL/IEC certification timeline, and any future US controls on high-performance power semiconductors. 2026 specs/prices must be refreshed in 2029. | 48000 | True | True |  | True | 59.6 | medium
P5-USSCI2-S01 | 6 | Qualified diamond transmission-dynode membrane and integration cartridge for hybrid MCP-PMTs used in EIC-class photon detectors | L13 | Big-science photon-detector hardware | process_output | scientific_big_physics | US | 3 | True | True | EIC Detector II may never receive construction funding, Exosens or Incom may close the collection-efficiency gap without a dynode, or BNL may internalize the process after the LDRD. Do not count base-ePIC procurement. Kill the commercial thesis at end-2029 unless a US lab or tube maker pays for qualification or writes the cartridge into a funded post-freeze detector plan. | 94000 | True | False |  | False | 58.2 | medium-low
P3R2-E-14 | 7 | Multi-terminal DC fault-discrimination protection relay plus vendor-neutral hardware-in-the-loop qualification platform for MVDC datacenter distribution and HVDC converter stations - the 'SEL of DC grids.' | L08 | DC grid protection | infrastructure | infrastructure_utility_transport | US | 3 | True | True | If US/offshore DC stays point-to-point through 2034, fast discrimination demand defers; converter vendors may refuse third-party protection in their stations. | 300000 | True | False |  | False | 56.4 | medium
P5R2-CN-01 | 8 | Retrofit X-ray computed-laminography kit for advanced-packaging failure analysis | L06 | new_supplemental_idea | diagnostic_test | industrial | US+CN | 4 | True | True | JCET's Lingang advanced-packaging factory has phase-one production-equipment completion targeted for H2 2028, while the official 2026-2030 national plan calls for decisive integrated-circuit breakthroughs. A 2030 launch enters the post-installation yield-learning and recurring failure-analysis cycle rather than trying to win the original cabinet order. | 120000 | True | True |  | True | 55.6 | medium
P3R2-A-14 | 9 | 300C-class mixed-signal instrumentation electronics platform (SiC/SOI) for superhot geothermal, downhole, and turbine environments | L15 | Harsh-environment electronics | process_output | industrial | US | 4 | True | True | If superhot drilling slips, the 300C market stays program-funded; oilfield in-house teams may capture the niche for their own tools only. | 850000 | True | False |  | False | 54.6 | high
P3R2-C-13 | 10 | Precision GaN pump-driver and laser-power modules: nanosecond-class programmable current drive as a merchant subsystem for industrial and defense-adjacent laser OEMs | L12 | photonics power electronics | process_output | industrial | US+CN | 4 | True | True | Export-control separability is manageable but sharp-edged: commercial drivers are low-sensitivity; any DEW-affiliated line must be strictly US-entity with no CN ownership links, or US primes will not buy - structure two entities from day one, accept that a forced choice may drop one market (then reassign batch). Chinese OEMs may refuse external drivers (NIH culture) - test willingness in 2028 discovery. FIX: the US(DEW)/commercial two-entity partition is a day-one structural requirement, not a contingency. | 72000 | True | True | JP | True | 54.2 | medium
P3R2-C-08 | 11 | Thermal-shock-tolerant printed-circuit heat exchangers (PCHE): merchant diffusion-bonded recuperators for sCO2 power, heat pumps, and hydrogen precooling | L04 | heat-to-power components | process_output | industrial | US+CN | 5 | True | True | Export separability: heat exchangers for CN steel/waste-heat retrofits are low-sensitivity; nuclear-qualified US product line kept in US entity (no CN transfer). Risks: sCO2 commercialization slips (kill if no >=10MW-class merchant order by end-2033); Chinese institutes verticalize; manufacturing capex heavier than electronics seeds. All 2026 project schedules must be re-verified 2029. | 65000 | True | True |  | True | 51.6 | medium
P3R2-B-01 | 12 | Sealed negative-pressure (subatmospheric) water/low-GWP two-phase cold-plate loop for >2 kW/chip Chinese AI racks - leak-safe by physics (air leaks in, coolant never leaks out), PFAS-free by design | L14 | AI datacenter thermal | infrastructure | infrastructure_utility_transport | CN | 4 | True | True | Foreign-founder access: direct sales to Chinese hyperscalers unrealistic; route is IP licensing/joint development with a Chinese thermal vendor (Envicool-class) or ODM design-in via HK entity. Risk that Chinese incumbents productize two-phase in-house before 2030; mitigated by patent position and the documented non-convergence of two-phase architectures. | 55000 | False | True | TW;JP | True | 51.0 | medium
P3R2-E-04 | 13 | High-density cryogenic interconnect loader with co-packaged 4K readout front-end (superconducting flex harness + cryo-CMOS multiplexing + cryo-LNA), breaking the 256-channel-per-loader wall for quantum computers. | L13 | quantum infrastructure | scientific_system | scientific_big_physics | US | 3 | True | True | On-chip multiplexing (1000:1) or optical cryo-links could leapfrog external harness density; quantum capex is cyclical and government-dependent. Substitution risks kept on record (from D-17): on-chip 1000:1 multiplexing, SFQ readout, cryo-CMOS moving control fully cold, and optical cryo-links could each leapfrog external harness density; roadmap-validation angle - the only public density roadmap is a single vendor's unvalidated claim, so independent validated density data is itself a wedge. | 60000 | True | False |  | False | 51.0 | medium
P5R2-CN-03 | 14 | Field-deployable industrial high-temperature heat-pump commissioning and measurement-and-verification island | L04 | new_supplemental_idea | diagnostic_test | industrial | US+CN | 5 | True | True | China's official heat-pump action plan sets 2030 deployment and industrialization objectives, while MIIT's 2026-2028 program explicitly calls for industrial heat pumps and wide-range actual-load efficiency evaluation. The validation window precedes the scale-up and acceptance wave. | 120000 | False | True |  | True | 50.0 | medium
P3R2-F-02 | 15 | Superconducting-magnet electrical balance-of-plant platform: standardized precision drive-and-dump skids (10 ppm-class high-current DC converters + energy-extraction/dump units + current leads + busbars) | L03 | fusion_bigscience | scientific_system | scientific_big_physics | US+CN | 6 | True | True | Fusion schedule slip pushes serial magnet builds past 2034; hedge is research/industrial magnet and accelerator PSU demand that exists regardless of fusion outcomes. | 400000 | True | True | JP;KR | True | 49.4 | medium
P3R2-C-04 | 16 | PFAS-free pumped two-phase direct-to-chip cooling loop: hermetic, fluid-agnostic evaporator/condenser subsystem co-qualified with low-GWP non-PFAS working fluids | L14 | AI datacenter thermal | infrastructure | infrastructure_utility_transport | US+CN | 4 | True | True | Fluid availability is the binding risk - if no non-PFAS two-phase fluid reaches datacenter-scale qualification by 2031, single-phase water wins another cycle (kill trigger). Export separability good: thermal hardware is uncontrolled; CN entity can localize manufacturing. Do not rely on the unconfirmed Chinese '100% liquid-cooling mandate' (contradicted by primary text, L14-036). FIX: the 2031 fluid-availability kill trigger is retained and extended to cover the subatmospheric-water variant. | 400000 | True | True | KR;JP;TW | True | 49.0 | medium
P3R2-F-12 | 17 | Classification-certified DC power and protection stacks for battery-electric and battery-swap inland/coastal vessels (CCS Rules-native string protection, insulation monitoring, containerized-pack power interface) | L10 | heavy_electrification | infrastructure | infrastructure_utility_transport | CN | 5 | True | True | Access is the honest risk: if CATL bundles the full electrical stack with packs, the merchant socket closes; the wedge is non-CATL integrators and class-rule complexity. | 75000 | False | True | KR;JP | True | 47.6 | medium
P3R2-G-01 | 18 | Closed-loop UHV chamber conditioning and acceptance-certification systems for China's big-science vacuum supply chain: instrumented vacuum-firing/bakeout stations with measured hydrogen-outgassing endpoints, integrated rate-of-rise/leak/RGA acceptance metrology, and tamper-evident per-chamber certification - sold as equipment plus recurring calibration to the China-registered fabricators who alone may bid HEPS/CEPC-class chamber tenders. | L07 | big-science vacuum / ultraclean process hardware | process_output | industrial | CN | 4 | True | True | CEPC slip is the dominant risk (single lumpy anchor - the exact defect that killed B-12); mitigated by multi-facility cadence (HEPS upgrades, ASIPP, CSNS-class - BINDING P4 pre-promotion condition: >=2 additional chamber-class tenders evidenced, else no promotion) and by equipment+calibration economics that work at fabricator level, not only facility level. Access risk: foreign founder cannot bid tenders directly - sells equipment/certification to eligible fabricators via licensed CN entity; margins mid; IP risk is bench absorption, countered by calibrated reference standards and model updates rather than a one-time transferable recipe. | 300000 | False | True | KR;JP | True | 47.6 | medium
P3R2-A-10 | 19 | Vendor-neutral ion-energy-distribution metrology + tailored-waveform bias control retrofit for plasma etch chambers | L06 | Semiconductor fab subsystems | process_output | industrial | US+CN | 4 | True | True | OEMs may lock chamber data behind proprietary interfaces; if generator vendors integrate good-enough IEDF inference by 2030 the retrofit market narrows to process-development labs. | 450000 | True | True | JP;KR;TW | True | 47.4 | medium
P3R2-G-03 | 20 | DC-conversion acceptance and commissioning instrumentation: a portable measurement island (swept-impedance bus-stability analyzer, IT-network insulation/ground-fault characterization, hot-swap/inrush transient capture) plus standardized acceptance protocols and signed dossiers, for facilities converting legacy UPS power rooms to 240V/336V/+-400V/800VDC and for vendors qualifying DC shelves - the measurement layer of the DC transition, not another in-path power product. | L02 | DC power infrastructure test & measurement | diagnostic_test | infrastructure_utility_transport | US+CN | 4 | True | True | Datacenter-adjacency declared honestly: demand is deliberately anchored to retrofit/acceptance of the EXISTING installed base and per-project commissioning spend, not to incremental AI capex (the downturn-resistant slice, F-19 precedent); a total freeze of DC investment would still slow it - stated, not hidden. Core demand risk: operators may accept vendor self-certification instead of paying for third-party acceptance - the 2029 frame-agreement gate is binding. CN access: services/instrument sales via licensed entity; hardware is copyable, so the moat must be the validated methodology + sequence library + dossier credibility; margins on instrument plus per-project license; State-Grid-facing work is explicitly out of scope (commercial operators/integrators only), avoiding the F-06/C-12 domestic-only trap. | 38000 | True | True | TW;JP;KR | True | 47.0 | low
P3R2-D-12 | 21 | Electrohydrodynamically-pumped two-phase cold plates: field-driven, no-moving-parts per-chip flow control for 3-5 kW AI packages, with a non-PFAS working-fluid plan. | L14 | AI datacenter extreme thermal | infrastructure | infrastructure_utility_transport | US+CN | 3 | True | True | EHD is a documented enthusiasm zone: two 2025 reviews note no industrial-scale deployment (L16-003, L16-004); fluid qualification (dielectric + low-GWP + non-PFAS) may not intersect; hyperscalers may brute-force with bigger CDUs. Hard fluid-intersection gate (FIX): the working fluid must simultaneously be dielectric, non-PFAS, and low-GWP; if no candidate passes qualification, kill regardless of EHD results. | 180000 | True | True | TW;KR | True | 46.8 | low
P3R2-F-23 | 22 | PEM electrolyzer 'protective operating envelope' controllers with warranty-grade black-box logging: embedded plant hardware that shapes current/OCV stress and produces bankable degradation evidence | L11 | electrochemical_plant | process_output | industrial | US+CN | 5 | True | True | If hydrogen FIDs stay depressed (documented order-book contraction), volume never arrives; the device concept then retargets battery/fuel-cell assets (same physics of warranty). | 45000 | True | True | JP | True | 44.2 | low
P3R2-F-06 | 23 | Precision wideband DC current/voltage sensing platform (optical and zero-flux hybrid) for HVDC converter stations, electrolyzer plants, and magnet systems | L08 | dc_grids | infrastructure | infrastructure_utility_transport | US | 5 | True | True | Component-margin business with entrenched incumbents; if HVDC protection stays vertically bundled inside converter OEMs, merchant sensing stays niche. | 35000 | True | False | KR | True | 42.4 | medium
P3R2-F-03 | 24 | High-speed permanent-magnet turbo-generator + power-converter 'electrical cartridge' (0.3-20 MW) for waste-heat sCO2 and geothermal/ORC power blocks | L04 | heat_to_power | process_output | industrial | US+CN | 5 | True | True | If sCO2 retrofit demand stays CNNC-internal and ORC incumbents keep generators in-house, the merchant socket is small; mitigated by multi-cycle applicability and the documented turbine capacity shortage. | 68000 | True | True | KR;JP | True | 37.2 | low

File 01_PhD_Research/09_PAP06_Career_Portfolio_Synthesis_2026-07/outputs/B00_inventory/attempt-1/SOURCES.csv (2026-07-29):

claim_id | url | title | publisher | published_date | accessed_date | source_type | stage_file | confidence | limitation
FRESH-01 | https://www.epa.gov/stationary-sources-air-pollution/ethylene-oxide-commercial-sterilization-and-fumigation-operations | Ethylene Oxide Commercial Sterilization and Fumigation Operations (EPA program page) | U.S. Environmental Protection Agency | 2025-11-24 (page 'Last updated' marker; no proposal/finalization date found on this specific page) | 2026-07-28 | government_regulatory | INPUT_MAP.json freshness_gaps.targeted_web_checks_performed_this_attempt | LOW-INCONCLUSIVE | Opened to check whether a newer dated action exists beyond the 2026-03-13 EPA proposal cited in outputs/A30_verify/attempt-1/COMPARE.json; this specific EPA URL did not surface that proposal text (A30 cited a different EPA page/document). Recorded as an inconclusive freshness check, not a contradiction of A30's finding and not a re-adjudication of any old06/new06 disagreement. A later stage should open the specific EPA docket/Federal Register page A30 cited, not this general program page, for a conclusive freshness read.
FRESH-02 | https://www.uspto.gov/patents/search/patent-public-search | Patent Public Search | United States Patent and Trademark Office (USPTO) | not stated on search result | 2026-07-28 | government_primary_search_tool | INPUT_MAP.json freshness_gaps.targeted_web_checks_performed_this_attempt | MODERATE | Accessed via WebSearch result summary only (page not independently opened with WebFetch in this attempt); used only to confirm the domain is live and actively changing (search results indicated last update 2026-07-20 and a scheduled 2026-07-24 Assignment/Export search change), establishing that startup/03's 2026-07 patent-landscape snapshot is on a domain with ongoing operational changes. No specific patent claim, grant, or expiration status was checked, asserted, or used to judge any corpus's IP claims.

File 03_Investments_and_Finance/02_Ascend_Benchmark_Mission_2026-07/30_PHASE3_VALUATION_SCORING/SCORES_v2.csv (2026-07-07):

Educational benchmark for a paper-trading learning exercise. Simulated allocations | not investment advice or recommendations. | FINAL at Gate PG2 2026-07-07: consolidated after 19/19 FR reviews + 5 re-red-teams (600839/002156/688519/688347/688141) with all challenges answered in REDTEAM_RESPONSES_v2.md (R5.1-R5.5); total_v1 = v1 SCORES.csv total (NEW = PP1 patch addition | baseline in SCORING_NOTES_v2 §1); delta = total - total_v1.
ticker | name | W1 | W2 | W3 | W4 | W5 | W6 | total | rank | cell_sources | total_v1 | delta | fr_status
688629 | 华丰科技 Huafeng Technology | 3 | 5 | 2 | 1 | 4 | 0 | 2.70 | 1 | W1:V_688629+REDTEAM_688629(R1.1);W2:V_688629+F_688629+REDTEAM_RESPONSES(R0.1);W3:F_688629+S700+REDTEAM_688629(R1.3);W4:VAL_688629+REDTEAM_RESPONSES(R0.2);W5:V_688629+F_688629+REDTEAM_688629(R1.5);W6:V_688629+REDTEAM_688629(R1.6);ALL:FR_688629(all six confirmed; top-1 filing-explicit 152973.27万=60.52pct S1170-S1171) | 2.70 | 0.00 | REVIEWED
000034 | 神州数码 Digital China | 5 | 1 | 1 | 1 | 1 | 3 | 2.00 | 2 | W1:V_000034;W2:V_000034(5.18pct ceiling);W3:F_000034;W4:VAL_000034;W5:V_000034+RB_02;W6:V_000034+F_000034;ALL:FR_000034(all six confirmed; W2 label imprecision noted: 5.18pct is a ceiling not a point, band unaffected S1178) | 2.00 | 0.00 | REVIEWED
300308 | 中际旭创 Innolight | 2 | 1 | 4 | 1 | 4 | 0 | 2.00 | 3 | W1:V_300308+REDTEAM_300308(R2.1);W2:V_300308(ceiling<10pct)+REDTEAM_RESPONSES(R0.1);W3:F_300308+S709+REDTEAM_300308(R2.3);W4:VAL_300308+REDTEAM_RESPONSES(R0.2);W5:V_300308+REDTEAM_300308(R2.5);W6:V_300308(S213)+REDTEAM_300308(R2.6);ALL:FR_300308(all six re-earned; independent top-5 bound corroborates ceiling S1182-S1183) | 2.00 | 0.00 | REVIEWED
002916 | 深南电路 Shennan Circuits | 1 | 0 | 4 | 1 | 4 | 4 | 2.00 | 4 | W1:V_002916;W2:V_002916(NOT-ESTIMABLE);W3:F_002916;W4:VAL_002916(PFP)+FR_002916+REDTEAM_RESPONSES_v2(R0.5a: tier-1 chain-relevant AI-server narrative -> 1);W5:V_002916+RB_02;W6:V_002916+F_002916;ALL:FR_002916(18.42/7.46pct re-verified exact S1194-S1195) | 1.80 | 0.20 | REVIEWED
688981 | 中芯国际 SMIC | 3 | 0 | 2 | 1 | 4 | 2 | 1.90 | 5 | W1:V_688981;W2:V_688981(NOT-ESTIMABLE);W3:F_688981;W4:VAL_688981;W5:V_688981+RB_02;W6:V_688981;ALL:FR_688981(all six confirmed; Hua Hong second-source presupposes SMIC link, trims forward exclusivity S1186-S1187) | 1.90 | 0.00 | REVIEWED
002261 | 拓维信息 Talkweb | 4 | 2 | 1 | 1 | 1 | 0 | 1.70 | 6 | W1:V_002261+REDTEAM_002261(C1);W2:S716+REDTEAM_002261(C2)+FR_002261(straddle alone would be 0; S716 FY2025 segment point 27.0pct rescues point-in-band per R0.6, minus one notch for -59.0pct segment collapse -> 2);W3:F_002261+VAL_002261+REDTEAM_002261(C3);W4:VAL_002261+REDTEAM_RESPONSES(R0.2)+FR_002261(narrative tier-A);W5:V_002261+RB_02;W6:V_002261(S150,S153)+REDTEAM_002261(C4);ALL:FR_002261(S624 27x-2026E fails recomputation S1198-S1199) | 1.70 | 0.00 | REVIEWED
002281 | 光迅科技 Accelink | 1 | 0 | 4 | 0 | 4 | 3 | 1.70 | 7 | W1:V_002281;W2:V_002281(NOT-ESTIMABLE);W3:F_002281;W4:VAL_002281(PFP on tier-C narrative)+FR_002281(177x ttm re-derived);W5:V_002281+RB_02;W6:V_002281+F_002281+FR_002281(top-5 +10.6pp YoY to 48.49pct; 71pct single-segment -> 3);ALL:FR_002281(echo chain re-confirmed to single caifuhao origin S1190-S1193) | 1.80 | -0.10 | REVIEWED
301236 | 软通动力 iSoftStone | 4 | 1 | 1 | 1 | 1 | 1 | 1.60 | 8 | W1:V_301236+REDTEAM_301236(C1);W2:S729+S300+REDTEAM_301236(C2)+FR_301236(W2=1 rests on proven-minimum ~1.3pct named wins per R0.6, not the 19-45 band-spanning bound);W3:F_301236+REDTEAM_301236(C3);W4:VAL_301236+REDTEAM_RESPONSES(R0.2)+FR_301236(narrative tier-A/B);W5:F_301236+REDTEAM_301236(C5);W6:V_301236+F_301236+REDTEAM_301236(C6);ALL:FR_301236(first tier-1 artifact: cninfo abstract via jina S1202-S1203, all figures exact; top-8 coverage per REDTEAM_RESPONSES_v2 status note: v1 memo + R4 + FR) | 1.60 | 0.00 | REVIEWED
688519 | 南亚新材 Nanya New Material | 3 | 0 | 2 | 1 | 2 | 2 | 1.60 | 9 | W1:V_688519+FR_688519(tier-1 parse S1167)+REDTEAM_688519_v2+REDTEAM_RESPONSES_v2(R5.3: prose names customers' chips not a Nanya-Huawei business; 华为认证 leg relay-B; R1.1 no-interpolation-above-file -> B maps to 3);W2:V_688519(17.70pct ceiling)+FR_688519(two-band span -> 0 per R0.6; numerator 9.25亿 relay-grade, note on file);W3:F_688519+REDTEAM_688519_v2+REDTEAM_RESPONSES_v2(R5.3+R0.7: R1.3 stack + SSE inquiry S983 + 监管警示 S989 -> 2);W4:VAL_688519(PFP 215x)+REDTEAM_RESPONSES_v2(R5.3: hold 1, aggravator logged - 75.8pct of FY2025 growth commodity-grade in industry hike wave S1267);W5:V_688519+RB_02+REDTEAM_RESPONSES_v2(R5.3: 82pct commodity mix at anchor-1 economics, grade-ladder facts -> 2);W6:F_688519(top5 34.96pct all PCB fabs)+REDTEAM_RESPONSES_v2(R5.3: single-ecosystem + receivables amplifier + AVL substitution -> 2);BASE:SCORING_NOTES_v2§1 | NEW |  | REVIEWED+RT2
002371 | 北方华创 NAURA | 2 | 0 | 2 | 1 | 3 | 2 | 1.55 | 10 | W1:V_002371+REDTEAM_002371(§W1);W2:V_002371(NOT-ESTIMABLE);W3:F_002371+REDTEAM_002371(§W3);W4:VAL_002371+REDTEAM_RESPONSES(R0.2);W5:V_002371+REDTEAM_002371(§W5,S741-S743);W6:V_002371+REDTEAM_002371(§W6,S740);ALL:FR_002371(all six confirmed; segment 93.34pct + top5 39.02pct re-verified S1210-S1211) | 1.55 | 0.00 | REVIEWED
301018 | 申菱环境 Shenling Environment | 1 | 0 | 3 | 0 | 4 | 3 | 1.55 | 11 | W1:V_301018+FR_301018(H公司 alias names neither Huawei nor business line -> C);W2:V_301018(NOT-ESTIMABLE);W3:F_301018;W4:VAL_301018(PFP on tier-C narrative)+FR_301018(231.45x re-derived exact);W5:V_301018+RB_02;W6:V_301018;ALL:FR_301018(S221 36.72/14.30pct re-fetched confirmed S1214-S1215) | 1.55 | 0.00 | REVIEWED
002436 | 兴森科技 Fastprint | 2 | 0 | 2 | 0 | 3 | 3 | 1.45 | 12 | W1:V_002436+FR_002436(official-reply generic-Huawei above C-floor -> 2, documented interpolation);W2:V_002436(FCBGA 0.37pct loss-making)+FR_002436(S956 digit discrepancy resolved);W3:F_002436+FR_002436;W4:VAL_002436(PFP on tier-C narrative, 497x)+FR_002436;W5:V_002436+FR_002436(subscale substrate position);W6:V_002436+F_002436+FR_002436;BASE:SCORING_NOTES_v2§1 | NEW |  | REVIEWED-NEW
600498 | 烽火通信 FiberHome | 4 | 0 | 1 | 1 | 1 | 1 | 1.40 | 13 | W1:V_600498+REDTEAM_600498(§W1)+FR_600498(both legs re-fetched verbatim S1218-S1219);W2:REDTEAM_600498(§W2 floor invalidated)+FR_600498(no estimable bound);W3:F_600498+REDTEAM_600498(§W3);W4:VAL_600498+REDTEAM_RESPONSES(R0.2)+FR_600498(narrative = tier-A 长江计算 story -> 1);W5:V_600498+REDTEAM_600498(§W5);W6:V_600498+REDTEAM_600498(§W6);ALL:FR_600498(all six confirmed) | 1.40 | 0.00 | REVIEWED
600839 | 四川长虹 Sichuan Changhong | 2 | 0 | 2 | 1 | 1 | 3 | 1.35 | 14 | W1:V_600839(tier-A debunk of claimed channel)+REDTEAM_600839_v2(S1250-S1252)+REDTEAM_RESPONSES_v2(R5.1: CJH company-voice Huawei AI-hardware distribution + tier-1 subsidiary trail -> 2 per FR_002436 precedent; stale 8016.HK corrected to 3991);W2:V_600839+FR_600839+REDTEAM_600839_v2(S1250: CJH split 42.94pct consumer/36.75pct enterprise/20.31pct other -> enterprise ceiling ~13.7pct of group, spans 10pct boundary -> 0 per R0.6; R0.1-era rescore SUPERSEDED);W3:F_600839+FR_600839(R1.3-precedent -> 2);W4:VAL_600839(NEUTRAL on headline basis)+REDTEAM_RESPONSES_v2(R5.1: 90.83pct of FY2025 headline NP non-recurring, core-basis ~333x, 扣非 -78pct two prints -> PFP -> 1 on tier-A/B generic-Huawei narrative);W5:V_600839+REDTEAM_600839_v2(CJH sleeve margins 1.49-2.63pct S1250);W6:V_600839+F_600839+REDTEAM_RESPONSES_v2(R5.1: W2/W6 symmetry + top-5 MISSING x3 + sleeve = 22.6pct of attributable NP ~ 2.5x core 扣非 + privatization concentration -> 3);ALL:REDTEAM_RESPONSES_v2(R5.1) | 2.40 | -1.05 | REVIEWED+RT2
688535 | 华海诚科 Huahai Chengke | 1 | 0 | 2 | 0 | 3 | 4 | 1.35 | 15 | W1:V_688535+FR_688535(weakest-hop C; GMC mass-supply win is NAND non-Huawei);W2:V_688535(GMC zero-revenue; 2026-05-20 still verification-stage S1162)+FR_688535;W3:F_688535+FR_688535(non-like-for-like M&A + record-low 扣非 NM + 3yr negative FCF -> 2);W4:VAL_688535(PFP on tier-C narrative, 746x; pro-forma bound ~277x)+FR_688535;W5:V_688535+FR_688535;W6:F_688535(top5 23.22pct max 7.48pct)+FR_688535(integration risk priced in W3);BASE:SCORING_NOTES_v2§1 | NEW |  | REVIEWED-NEW
688141 | 杰华特 Joulwatt | 2 | 0 | 1 | 1 | 2 | 2 | 1.25 | 16 | W1:V_688141(S924 single-outlet placement)+FR_688141+REDTEAM_688141_v2(S1282 tier-1 HK-roadshow Huawei-silent; S1284 second house frames same line non-Ascend)+REDTEAM_RESPONSES_v2(R5.5: R2.1 substance-thin-B cap -> 2);W2:V_688141(A8: anonymous top-1 30.04pct not equatable)+FR_688141+REDTEAM_RESPONSES_v2(R5.5 confirm);W3:F_688141+REDTEAM_RESPONSES_v2(R5.5: hold 1; aggravators logged - 0.42x short-maturity coverage; 未弥补亏损达实收股本三分之一 agenda item S1352; audit-opinion type unverifiable this session, PP4 spot-check candidate);W4:VAL_688141(PFP, no earnings floor)+REDTEAM_RESPONSES_v2(R5.5: hold 1 per R0.2/R0.5, four aggravators logged incl. HK-IPO overhang);W5:V_688141+RB_02+REDTEAM_RESPONSES_v2(R5.5: entrant position, cohort-half GM falling 4 periods, price-war layer -> 2);W6:F_688141(top1 ~26-31pct 3yrs)+REDTEAM_RESPONSES_v2(R5.5: Fork-B election per A8; concentration + related-party anonymization precedent S926 -> 2);BASE:SCORING_NOTES_v2§1 | NEW |  | REVIEWED+RT2
002156 | 通富微电 TFME | 1 | 0 | 3 | 0 | 3 | 1 | 1.20 | 17 | W1:V_002156+FR_002156(tier C re-confirmed S1206);W2:V_002156(NOT-ESTIMABLE);W3:F_002156+REDTEAM_002156_v2+REDTEAM_RESPONSES_v2(R5.2: conjunctive 5-anchor, net debt 11x NP widening, GM fell in boom year, 3yr FCF -754M -> 3);W4:VAL_002156(PFP)+REDTEAM_RESPONSES_v2(R5.2+R0.5b: priced narrative = AMD, zero chain nexus -> 0; FR_002156 upgrade reversed);W5:V_002156+RB_02+REDTEAM_RESPONSES_v2(R5.2: R2.5 overseas-chain content growth does not earn RB_02 premium -> 3);W6:V_002156(52.29pct single customer)+REDTEAM_002156_v2(S1258/S1260)+REDTEAM_RESPONSES_v2(R5.2: concentration + upstream premium capture + 2026 agreement horizon + MI308 policy trigger = both prongs -> 1);ALL:REDTEAM_RESPONSES_v2(R5.2) | 1.60 | -0.40 | REVIEWED+RT2
688347 | 华虹公司 Hua Hong | 1 | 0 | 1 | 0 | 2 | 2 | 0.85 | 18 | W1:V_688347+FR_688347+REDTEAM_688347_v2(C1)+REDTEAM_RESPONSES_v2(R5.4+R0.8: deal perimeter verified Fab-5-only, Ascend-linked Fab 6 excluded and retained by group S1350/S1277/S1274 -> listco link = C-grade residue -> 1);W2:V_688347(verified 0pct current; prospective NOT-ESTIMABLE; catalyst clause removed per C6c)+FR_688347;W3:F_688347+REDTEAM_688347_v2(C2)+REDTEAM_RESPONSES_v2(R5.4: both anchor-1 elements + consolidated TOTAL loss 3 periods via minority absorption -> 1);W4:VAL_688347(1141x)+REDTEAM_RESPONSES_v2(R5.4: priced narrative = excluded-asset scarcity story = C-residue per R0.5/R0.8 -> 0; aggravators logged incl. 61.81bn market cost of share consideration = 10.98pct of mktcap, 7.48x consideration framing);W5:V_688347+RB_02+REDTEAM_RESPONSES_v2(R5.4: peak-cycle GM 11.8-16pct USD with total-basis losses; capacity added into same nodes -> 2);W6:F_688347(top5 34.18pct rising)+REDTEAM_RESPONSES_v2(R5.4: BIS action company-named + related-party issuance stack + CSRC gate -> 2);BASE:SCORING_NOTES_v2§1 | NEW |  | REVIEWED+RT2
000628 | 高新发展 Gaoxin Development | 0 | 0 | 2 | 0 | 1 | 3 | 0.75 | 19 | W1:V_000628(tier-A debunk)+FR_000628(debunk reconfirmed thru 2026-07-04 S1222);W2:V_000628(0pct);W3:F_000628;W4:VAL_000628(PFP on debunked narrative -> 0 per R0.5);W5:V_000628+F_000628;W6:V_000628+F_000628;ALL:FR_000628(revenue/NP/PE re-verified exact) | 0.75 | 0.00 | REVIEWED

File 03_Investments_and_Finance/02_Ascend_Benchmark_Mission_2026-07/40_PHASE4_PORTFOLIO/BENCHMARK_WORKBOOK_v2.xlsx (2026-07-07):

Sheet: Scores
Educational benchmark for a paper-trading learning exercise. Simulated allocations, not investment advice or recommendations. | v2 accuracy patch. Data as-of 2026-07-07 (quotes: 2026-07-07 A-share close; filings: FY2025/Q1-2026). Universe 19 = v1's 14 + PP1 additions 688347/688141/002436/688535/688519. | FINAL v2 post-re-red-team (REDTEAM_RESPONSES_v2.md); total_v1/delta columns give the v1 side-by-side per PATCH_BRIEF.
ticker | name | W1 | W2 | W3 | W4 | W5 | W6 | total | rank | cell_sources | total_v1 | delta | fr_status
688629 | 华丰科技 Huafeng Technology | 3 | 5 | 2 | 1 | 4 | 0 | 2.7 | 1 | W1:V_688629+REDTEAM_688629(R1.1);W2:V_688629+F_688629+REDTEAM_RESPONSES(R0.1);W3:F_688629+S700+REDTEAM_688629(R1.3);W4:VAL_688629+REDTEAM_RESPONSES(R0.2);W5:V_688629+F_688629+REDTEAM_688629(R1.5);W6:V_688629+REDTEAM_688629(R1.6);ALL:FR_688629(all six confirmed; top-1 filing-explicit 152973.27万=60.52pct S1170-S1171) | 2.7 | 0 | REVIEWED
34 | 神州数码 Digital China | 5 | 1 | 1 | 1 | 1 | 3 | 2 | 2 | W1:V_000034;W2:V_000034(5.18pct ceiling);W3:F_000034;W4:VAL_000034;W5:V_000034+RB_02;W6:V_000034+F_000034;ALL:FR_000034(all six confirmed; W2 label imprecision noted: 5.18pct is a ceiling not a point, band unaffected S1178) | 2 | 0 | REVIEWED
300308 | 中际旭创 Innolight | 2 | 1 | 4 | 1 | 4 | 0 | 2 | 3 | W1:V_300308+REDTEAM_300308(R2.1);W2:V_300308(ceiling<10pct)+REDTEAM_RESPONSES(R0.1);W3:F_300308+S709+REDTEAM_300308(R2.3);W4:VAL_300308+REDTEAM_RESPONSES(R0.2);W5:V_300308+REDTEAM_300308(R2.5);W6:V_300308(S213)+REDTEAM_300308(R2.6);ALL:FR_300308(all six re-earned; independent top-5 bound corroborates ceiling S1182-S1183) | 2 | 0 | REVIEWED
2916 | 深南电路 Shennan Circuits | 1 | 0 | 4 | 1 | 4 | 4 | 2 | 4 | W1:V_002916;W2:V_002916(NOT-ESTIMABLE);W3:F_002916;W4:VAL_002916(PFP)+FR_002916+REDTEAM_RESPONSES_v2(R0.5a: tier-1 chain-relevant AI-server narrative -> 1);W5:V_002916+RB_02;W6:V_002916+F_002916;ALL:FR_002916(18.42/7.46pct re-verified exact S1194-S1195) | 1.8 | 0.2 | REVIEWED
688981 | 中芯国际 SMIC | 3 | 0 | 2 | 1 | 4 | 2 | 1.9 | 5 | W1:V_688981;W2:V_688981(NOT-ESTIMABLE);W3:F_688981;W4:VAL_688981;W5:V_688981+RB_02;W6:V_688981;ALL:FR_688981(all six confirmed; Hua Hong second-source presupposes SMIC link, trims forward exclusivity S1186-S1187) | 1.9 | 0 | REVIEWED
2261 | 拓维信息 Talkweb | 4 | 2 | 1 | 1 | 1 | 0 | 1.7 | 6 | W1:V_002261+REDTEAM_002261(C1);W2:S716+REDTEAM_002261(C2)+FR_002261(straddle alone would be 0; S716 FY2025 segment point 27.0pct rescues point-in-band per R0.6, minus one notch for -59.0pct segment collapse -> 2);W3:F_002261+VAL_002261+REDTEAM_002261(C3);W4:VAL_002261+REDTEAM_RESPONSES(R0.2)+FR_002261(narrative tier-A);W5:V_002261+RB_02;W6:V_002261(S150,S153)+REDTEAM_002261(C4);ALL:FR_002261(S624 27x-2026E fails recomputation S1198-S1199) | 1.7 | 0 | REVIEWED
2281 | 光迅科技 Accelink | 1 | 0 | 4 | 0 | 4 | 3 | 1.7 | 7 | W1:V_002281;W2:V_002281(NOT-ESTIMABLE);W3:F_002281;W4:VAL_002281(PFP on tier-C narrative)+FR_002281(177x ttm re-derived);W5:V_002281+RB_02;W6:V_002281+F_002281+FR_002281(top-5 +10.6pp YoY to 48.49pct; 71pct single-segment -> 3);ALL:FR_002281(echo chain re-confirmed to single caifuhao origin S1190-S1193) | 1.8 | -0.1 | REVIEWED
301236 | 软通动力 iSoftStone | 4 | 1 | 1 | 1 | 1 | 1 | 1.6 | 8 | W1:V_301236+REDTEAM_301236(C1);W2:S729+S300+REDTEAM_301236(C2)+FR_301236(W2=1 rests on proven-minimum ~1.3pct named wins per R0.6, not the 19-45 band-spanning bound);W3:F_301236+REDTEAM_301236(C3);W4:VAL_301236+REDTEAM_RESPONSES(R0.2)+FR_301236(narrative tier-A/B);W5:F_301236+REDTEAM_301236(C5);W6:V_301236+F_301236+REDTEAM_301236(C6);ALL:FR_301236(first tier-1 artifact: cninfo abstract via jina S1202-S1203, all figures exact; top-8 coverage per REDTEAM_RESPONSES_v2 status note: v1 memo + R4 + FR) | 1.6 | 0 | REVIEWED
688519 | 南亚新材 Nanya New Material | 3 | 0 | 2 | 1 | 2 | 2 | 1.6 | 9 | W1:V_688519+FR_688519(tier-1 parse S1167)+REDTEAM_688519_v2+REDTEAM_RESPONSES_v2(R5.3: prose names customers' chips not a Nanya-Huawei business; 华为认证 leg relay-B; R1.1 no-interpolation-above-file -> B maps to 3);W2:V_688519(17.70pct ceiling)+FR_688519(two-band span -> 0 per R0.6; numerator 9.25亿 relay-grade, note on file);W3:F_688519+REDTEAM_688519_v2+REDTEAM_RESPONSES_v2(R5.3+R0.7: R1.3 stack + SSE inquiry S983 + 监管警示 S989 -> 2);W4:VAL_688519(PFP 215x)+REDTEAM_RESPONSES_v2(R5.3: hold 1, aggravator logged - 75.8pct of FY2025 growth commodity-grade in industry hike wave S1267);W5:V_688519+RB_02+REDTEAM_RESPONSES_v2(R5.3: 82pct commodity mix at anchor-1 economics, grade-ladder facts -> 2);W6:F_688519(top5 34.96pct all PCB fabs)+REDTEAM_RESPONSES_v2(R5.3: single-ecosystem + receivables amplifier + AVL substitution -> 2);BASE:SCORING_NOTES_v2§1 | NEW |  | REVIEWED+RT2
2371 | 北方华创 NAURA | 2 | 0 | 2 | 1 | 3 | 2 | 1.55 | 10 | W1:V_002371+REDTEAM_002371(§W1);W2:V_002371(NOT-ESTIMABLE);W3:F_002371+REDTEAM_002371(§W3);W4:VAL_002371+REDTEAM_RESPONSES(R0.2);W5:V_002371+REDTEAM_002371(§W5,S741-S743);W6:V_002371+REDTEAM_002371(§W6,S740);ALL:FR_002371(all six confirmed; segment 93.34pct + top5 39.02pct re-verified S1210-S1211) | 1.55 | 0 | REVIEWED
301018 | 申菱环境 Shenling Environment | 1 | 0 | 3 | 0 | 4 | 3 | 1.55 | 11 | W1:V_301018+FR_301018(H公司 alias names neither Huawei nor business line -> C);W2:V_301018(NOT-ESTIMABLE);W3:F_301018;W4:VAL_301018(PFP on tier-C narrative)+FR_301018(231.45x re-derived exact);W5:V_301018+RB_02;W6:V_301018;ALL:FR_301018(S221 36.72/14.30pct re-fetched confirmed S1214-S1215) | 1.55 | 0 | REVIEWED
2436 | 兴森科技 Fastprint | 2 | 0 | 2 | 0 | 3 | 3 | 1.45 | 12 | W1:V_002436+FR_002436(official-reply generic-Huawei above C-floor -> 2, documented interpolation);W2:V_002436(FCBGA 0.37pct loss-making)+FR_002436(S956 digit discrepancy resolved);W3:F_002436+FR_002436;W4:VAL_002436(PFP on tier-C narrative, 497x)+FR_002436;W5:V_002436+FR_002436(subscale substrate position);W6:V_002436+F_002436+FR_002436;BASE:SCORING_NOTES_v2§1 | NEW |  | REVIEWED-NEW
600498 | 烽火通信 FiberHome | 4 | 0 | 1 | 1 | 1 | 1 | 1.4 | 13 | W1:V_600498+REDTEAM_600498(§W1)+FR_600498(both legs re-fetched verbatim S1218-S1219);W2:REDTEAM_600498(§W2 floor invalidated)+FR_600498(no estimable bound);W3:F_600498+REDTEAM_600498(§W3);W4:VAL_600498+REDTEAM_RESPONSES(R0.2)+FR_600498(narrative = tier-A 长江计算 story -> 1);W5:V_600498+REDTEAM_600498(§W5);W6:V_600498+REDTEAM_600498(§W6);ALL:FR_600498(all six confirmed) | 1.4 | 0 | REVIEWED
600839 | 四川长虹 Sichuan Changhong | 2 | 0 | 2 | 1 | 1 | 3 | 1.35 | 14 | W1:V_600839(tier-A debunk of claimed channel)+REDTEAM_600839_v2(S1250-S1252)+REDTEAM_RESPONSES_v2(R5.1: CJH company-voice Huawei AI-hardware distribution + tier-1 subsidiary trail -> 2 per FR_002436 precedent; stale 8016.HK corrected to 3991);W2:V_600839+FR_600839+REDTEAM_600839_v2(S1250: CJH split 42.94pct consumer/36.75pct enterprise/20.31pct other -> enterprise ceiling ~13.7pct of group, spans 10pct boundary -> 0 per R0.6; R0.1-era rescore SUPERSEDED);W3:F_600839+FR_600839(R1.3-precedent -> 2);W4:VAL_600839(NEUTRAL on headline basis)+REDTEAM_RESPONSES_v2(R5.1: 90.83pct of FY2025 headline NP non-recurring, core-basis ~333x, 扣非 -78pct two prints -> PFP -> 1 on tier-A/B generic-Huawei narrative);W5:V_600839+REDTEAM_600839_v2(CJH sleeve margins 1.49-2.63pct S1250);W6:V_600839+F_600839+REDTEAM_RESPONSES_v2(R5.1: W2/W6 symmetry + top-5 MISSING x3 + sleeve = 22.6pct of attributable NP ~ 2.5x core 扣非 + privatization concentration -> 3);ALL:REDTEAM_RESPONSES_v2(R5.1) | 2.4 | -1.05 | REVIEWED+RT2
688535 | 华海诚科 Huahai Chengke | 1 | 0 | 2 | 0 | 3 | 4 | 1.35 | 15 | W1:V_688535+FR_688535(weakest-hop C; GMC mass-supply win is NAND non-Huawei);W2:V_688535(GMC zero-revenue; 2026-05-20 still verification-stage S1162)+FR_688535;W3:F_688535+FR_688535(non-like-for-like M&A + record-low 扣非 NM + 3yr negative FCF -> 2);W4:VAL_688535(PFP on tier-C narrative, 746x; pro-forma bound ~277x)+FR_688535;W5:V_688535+FR_688535;W6:F_688535(top5 23.22pct max 7.48pct)+FR_688535(integration risk priced in W3);BASE:SCORING_NOTES_v2§1 | NEW |  | REVIEWED-NEW
688141 | 杰华特 Joulwatt | 2 | 0 | 1 | 1 | 2 | 2 | 1.25 | 16 | W1:V_688141(S924 single-outlet placement)+FR_688141+REDTEAM_688141_v2(S1282 tier-1 HK-roadshow Huawei-silent; S1284 second house frames same line non-Ascend)+REDTEAM_RESPONSES_v2(R5.5: R2.1 substance-thin-B cap -> 2);W2:V_688141(A8: anonymous top-1 30.04pct not equatable)+FR_688141+REDTEAM_RESPONSES_v2(R5.5 confirm);W3:F_688141+REDTEAM_RESPONSES_v2(R5.5: hold 1; aggravators logged - 0.42x short-maturity coverage; 未弥补亏损达实收股本三分之一 agenda item S1352; audit-opinion type unverifiable this session, PP4 spot-check candidate);W4:VAL_688141(PFP, no earnings floor)+REDTEAM_RESPONSES_v2(R5.5: hold 1 per R0.2/R0.5, four aggravators logged incl. HK-IPO overhang);W5:V_688141+RB_02+REDTEAM_RESPONSES_v2(R5.5: entrant position, cohort-half GM falling 4 periods, price-war layer -> 2);W6:F_688141(top1 ~26-31pct 3yrs)+REDTEAM_RESPONSES_v2(R5.5: Fork-B election per A8; concentration + related-party anonymization precedent S926 -> 2);BASE:SCORING_NOTES_v2§1 | NEW |  | REVIEWED+RT2
2156 | 通富微电 TFME | 1 | 0 | 3 | 0 | 3 | 1 | 1.2 | 17 | W1:V_002156+FR_002156(tier C re-confirmed S1206);W2:V_002156(NOT-ESTIMABLE);W3:F_002156+REDTEAM_002156_v2+REDTEAM_RESPONSES_v2(R5.2: conjunctive 5-anchor, net debt 11x NP widening, GM fell in boom year, 3yr FCF -754M -> 3);W4:VAL_002156(PFP)+REDTEAM_RESPONSES_v2(R5.2+R0.5b: priced narrative = AMD, zero chain nexus -> 0; FR_002156 upgrade reversed);W5:V_002156+RB_02+REDTEAM_RESPONSES_v2(R5.2: R2.5 overseas-chain content growth does not earn RB_02 premium -> 3);W6:V_002156(52.29pct single customer)+REDTEAM_002156_v2(S1258/S1260)+REDTEAM_RESPONSES_v2(R5.2: concentration + upstream premium capture + 2026 agreement horizon + MI308 policy trigger = both prongs -> 1);ALL:REDTEAM_RESPONSES_v2(R5.2) | 1.6 | -0.4 | REVIEWED+RT2
688347 | 华虹公司 Hua Hong | 1 | 0 | 1 | 0 | 2 | 2 | 0.85 | 18 | W1:V_688347+FR_688347+REDTEAM_688347_v2(C1)+REDTEAM_RESPONSES_v2(R5.4+R0.8: deal perimeter verified Fab-5-only, Ascend-linked Fab 6 excluded and retained by group S1350/S1277/S1274 -> listco link = C-grade residue -> 1);W2:V_688347(verified 0pct current; prospective NOT-ESTIMABLE; catalyst clause removed per C6c)+FR_688347;W3:F_688347+REDTEAM_688347_v2(C2)+REDTEAM_RESPONSES_v2(R5.4: both anchor-1 elements + consolidated TOTAL loss 3 periods via minority absorption -> 1);W4:VAL_688347(1141x)+REDTEAM_RESPONSES_v2(R5.4: priced narrative = excluded-asset scarcity story = C-residue per R0.5/R0.8 -> 0; aggravators logged incl. 61.81bn market cost of share consideration = 10.98pct of mktcap, 7.48x consideration framing);W5:V_688347+RB_02+REDTEAM_RESPONSES_v2(R5.4: peak-cycle GM 11.8-16pct USD with total-basis losses; capacity added into same nodes -> 2);W6:F_688347(top5 34.18pct rising)+REDTEAM_RESPONSES_v2(R5.4: BIS action company-named + related-party issuance stack + CSRC gate -> 2);BASE:SCORING_NOTES_v2§1 | NEW |  | REVIEWED+RT2
628 | 高新发展 Gaoxin Development | 0 | 0 | 2 | 0 | 1 | 3 | 0.75 | 19 | W1:V_000628(tier-A debunk)+FR_000628(debunk reconfirmed thru 2026-07-04 S1222);W2:V_000628(0pct);W3:F_000628;W4:VAL_000628(PFP on debunked narrative -> 0 per R0.5);W5:V_000628+F_000628;W6:V_000628+F_000628;ALL:FR_000628(revenue/NP/PE re-verified exact) | 0.75 | 0 | REVIEWED
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

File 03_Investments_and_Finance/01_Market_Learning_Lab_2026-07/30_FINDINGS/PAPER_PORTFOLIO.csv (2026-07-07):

trade_id | date | action | ticker | name | qty | ccy | price | thesis_link | exit_criteria | status | close_date | close_price | result_pct | lesson
T000 | 2026-07-05 | BUY | EXAMPLE | delete-me-example-row | 100 | CNY | 10.00 | 10_RESEARCH/RB_02_ascend_supply_chain_map.md | close if thesis falsified or -15% | OPEN |  |  |  | format demo only

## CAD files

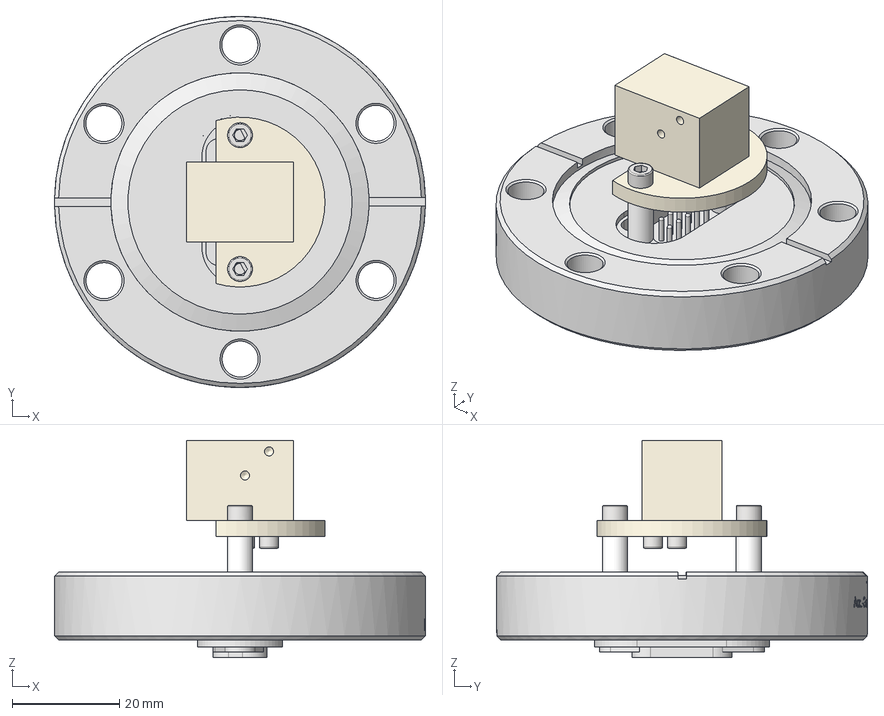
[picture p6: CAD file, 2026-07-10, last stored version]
01_PhD_Research/09/sources/phd/P/01/05_HSX_ChatGPT_Windows_App/inputs/reference/cad/new_3d_idea_assembled.stp
69.3 x 69.3 x 40.6 mm
platform_v2
cube_package_v3
100200 AGP
stand x 2
ANSI B18.3 - No. 2 - 56 UNC - 1/4 HS HCS x 2
ANSI B18.3 - No. 4 - 40 UNC - 9/16 HS HCS x 2
pcb x 2
die x 2

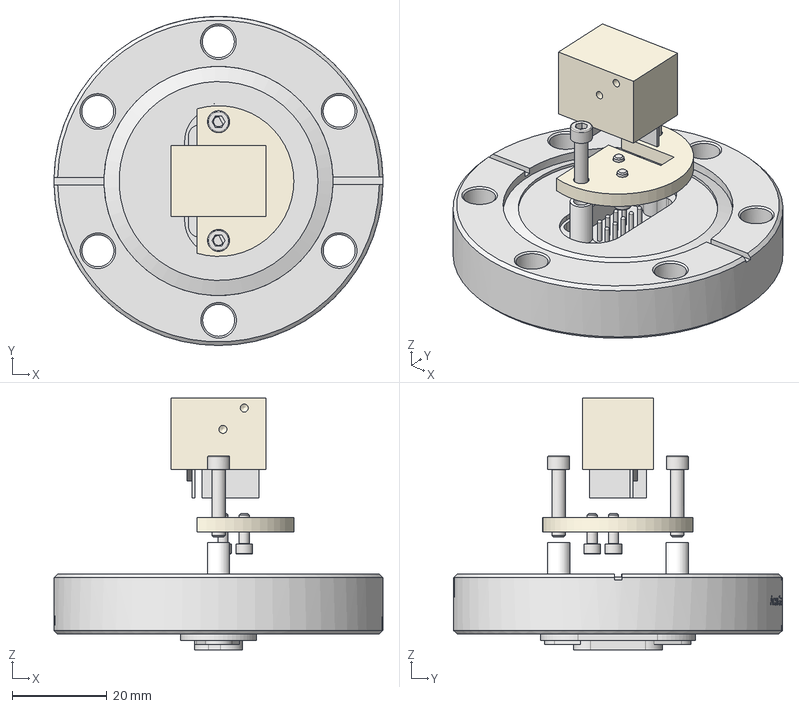
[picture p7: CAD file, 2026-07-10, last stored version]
01_PhD_Research/09/sources/phd/P/01/05_HSX_ChatGPT_Windows_App/inputs/reference/cad/new_3d_idea_disassembled.stp
69.3 x 69.3 x 53.0 mm
platform_v2
cube_package_v3
100200 AGP
stand x 2
ANSI B18.3 - No. 2 - 56 UNC - 1/4 HS HCS x 2
ANSI B18.3 - No. 4 - 40 UNC - 9/16 HS HCS x 2
pcb x 2
die x 2

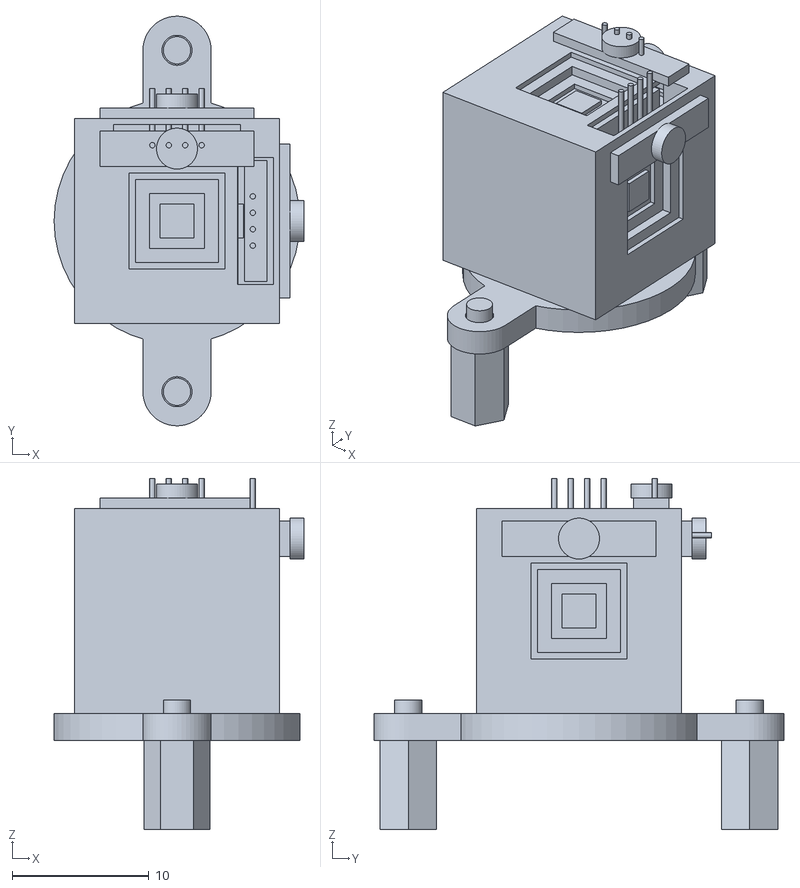
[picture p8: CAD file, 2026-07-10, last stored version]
01_PhD_Research/05_HSX_Readout_Review_PromptPack/80_3D_PACKAGING/concept_A_slot_refined/concept_A.stl
18.3 x 30.0 x 25.7

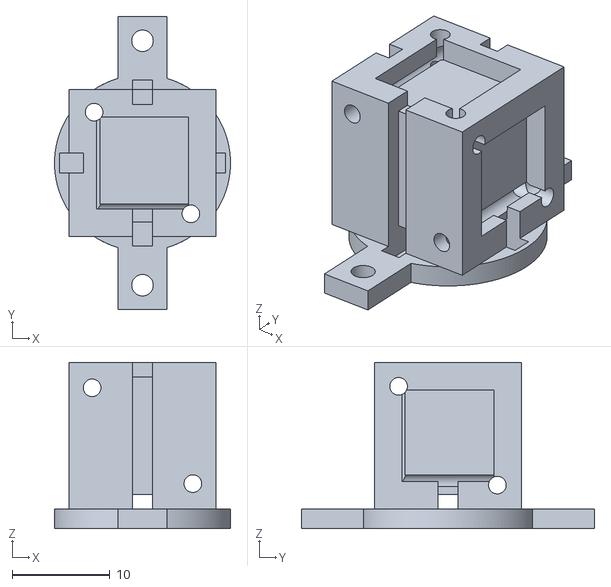
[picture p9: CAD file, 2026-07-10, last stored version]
01_PhD_Research/05_HSX_Readout_Review_PromptPack/80_3D_PACKAGING/concept_B_springclamp_cube/concept_B_zirconia_body.stl
18.0 x 30.0 x 17.0

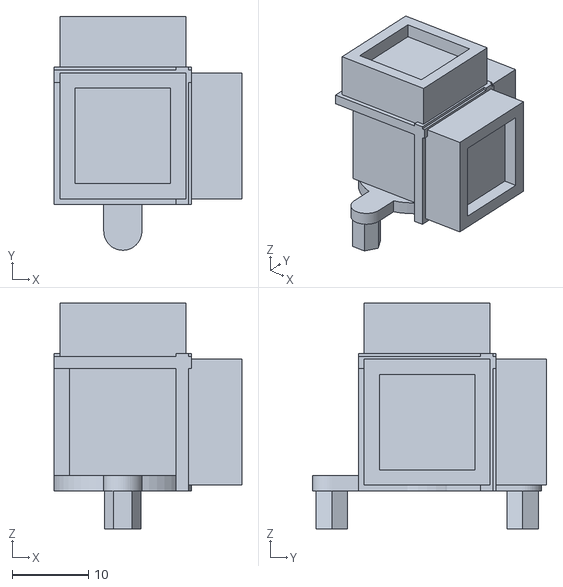
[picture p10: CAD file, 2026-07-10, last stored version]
01_PhD_Research/05_HSX_Readout_Review_PromptPack/80_3D_PACKAGING/concept_C_cots_socket/concept_C.stl
24.6 x 30.6 x 29.6

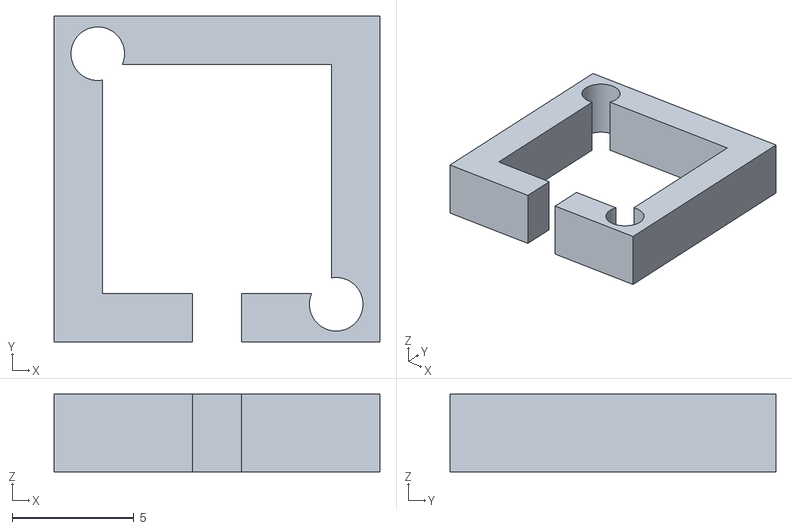
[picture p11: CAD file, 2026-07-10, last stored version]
01_PhD_Research/05_HSX_Readout_Review_PromptPack/80_3D_PACKAGING/concept_D_triplate_corner/concept_D_seat_plate.stl
13.4 x 13.4 x 3.20

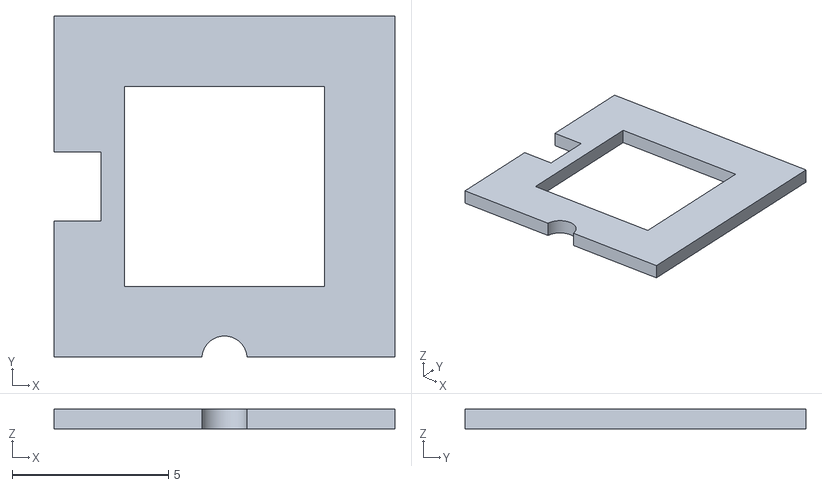
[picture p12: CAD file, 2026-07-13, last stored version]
01_PhD_Research/09/sources/phd/P/01/05_HSX_ChatGPT_Windows_App/outputs/cad/50B_GUARD_NFF.stl
10.9 x 10.9 x 0.635

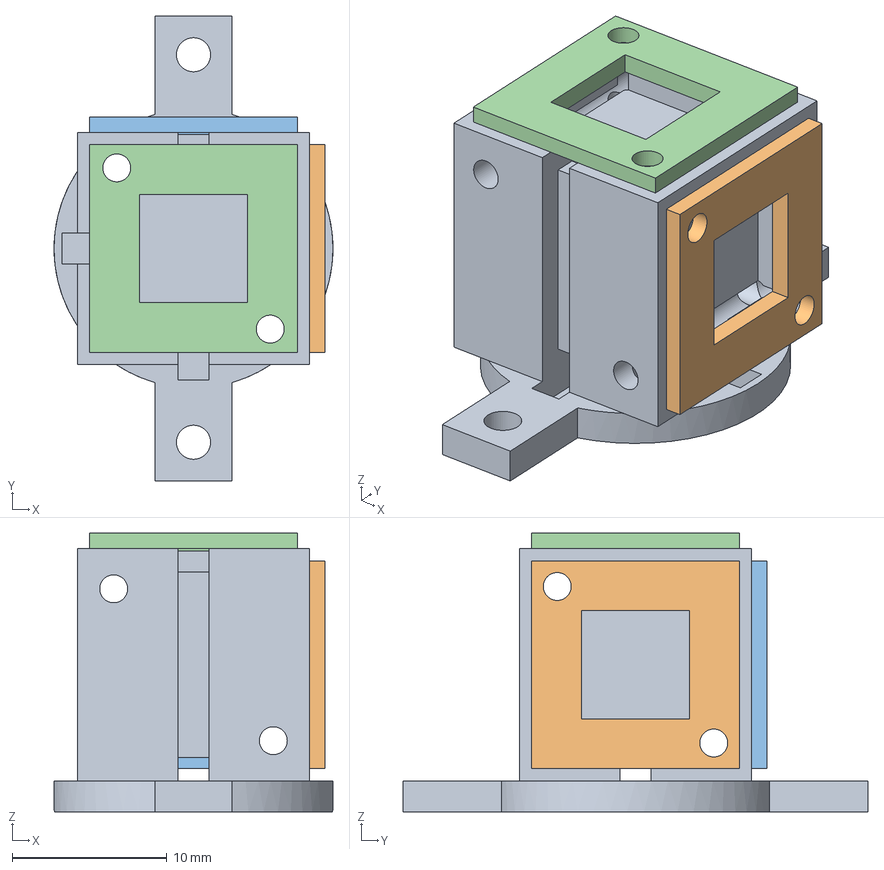
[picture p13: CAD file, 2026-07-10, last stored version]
01_PhD_Research/05_HSX_Readout_Review_PromptPack/80_3D_PACKAGING/concept_B_springclamp_cube/concept_B.step
18.0 x 30.0 x 18.0 mm

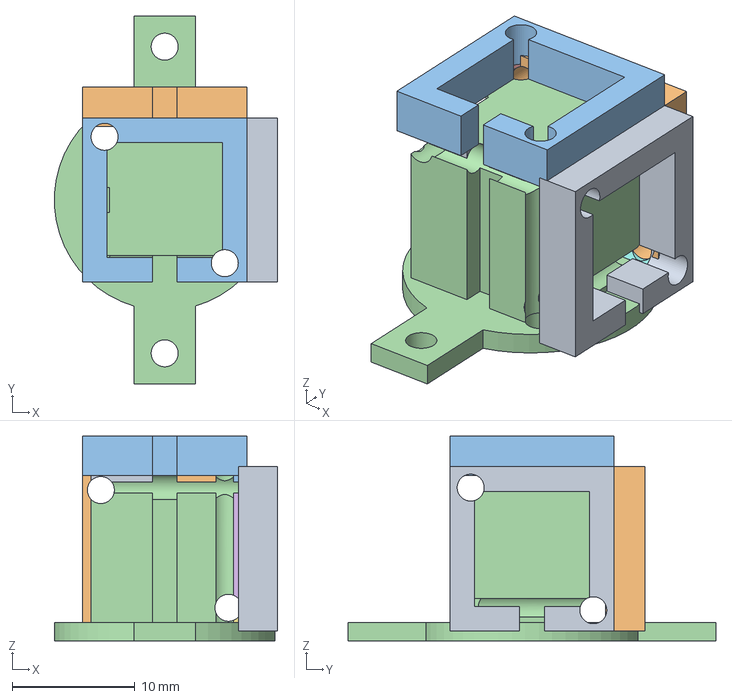
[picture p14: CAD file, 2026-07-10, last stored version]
01_PhD_Research/05_HSX_Readout_Review_PromptPack/80_3D_PACKAGING/concept_D_triplate_corner/concept_D.step
18.2 x 30.0 x 16.7 mm

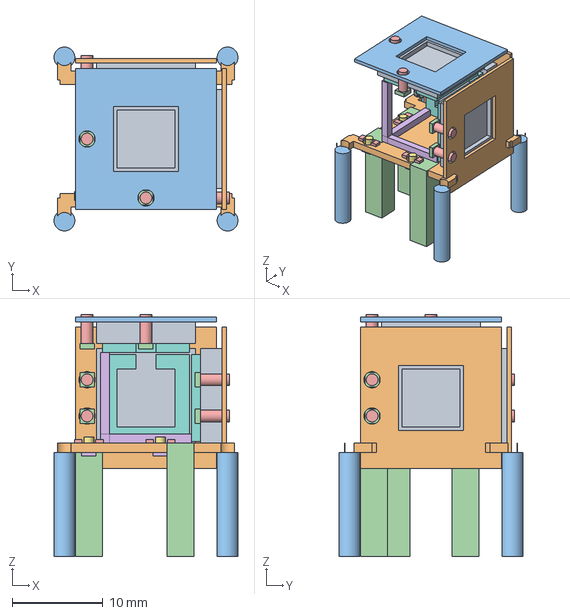
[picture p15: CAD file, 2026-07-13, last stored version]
01_PhD_Research/09/sources/phd/P/01/05_HSX_ChatGPT_Windows_App/outputs/cad/30A_triplate_cage_NOT_FOR_FABRICATION.step
20.3 x 20.3 x 26.7 mm

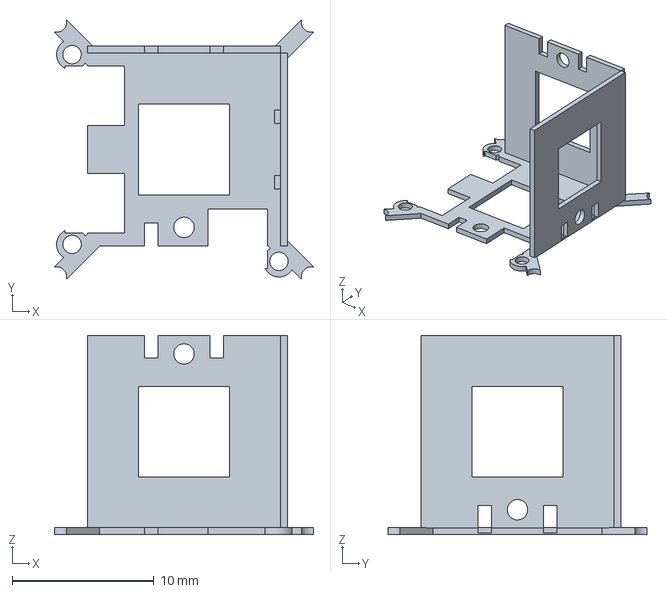
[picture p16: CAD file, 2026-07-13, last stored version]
01_PhD_Research/09/sources/phd/P/01/05_HSX_ChatGPT_Windows_App/outputs/cad/50B_BRACKET_NFF.step
18.3 x 18.3 x 14.1 mm

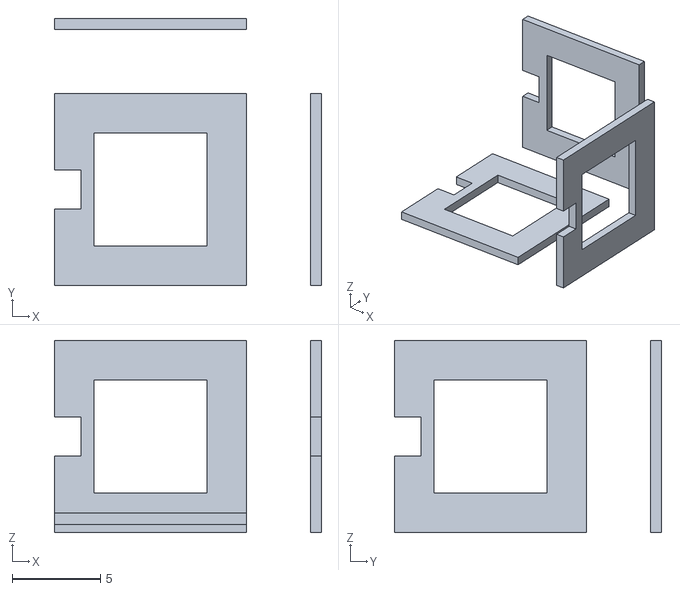
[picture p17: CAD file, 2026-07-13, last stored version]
01_PhD_Research/09/sources/phd/P/01/05_HSX_ChatGPT_Windows_App/outputs/cad/30D_GUARD_NFF.stl
15.1 x 15.1 x 10.9

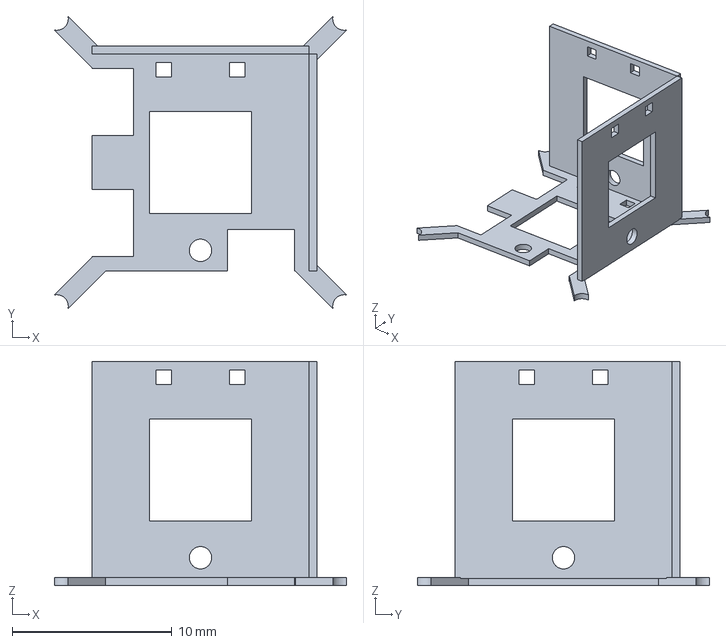
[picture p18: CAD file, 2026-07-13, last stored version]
01_PhD_Research/09/sources/phd/P/01/05_HSX_ChatGPT_Windows_App/outputs/cad/30D_BRACKET_NFF.step
18.3 x 18.3 x 14.1 mm

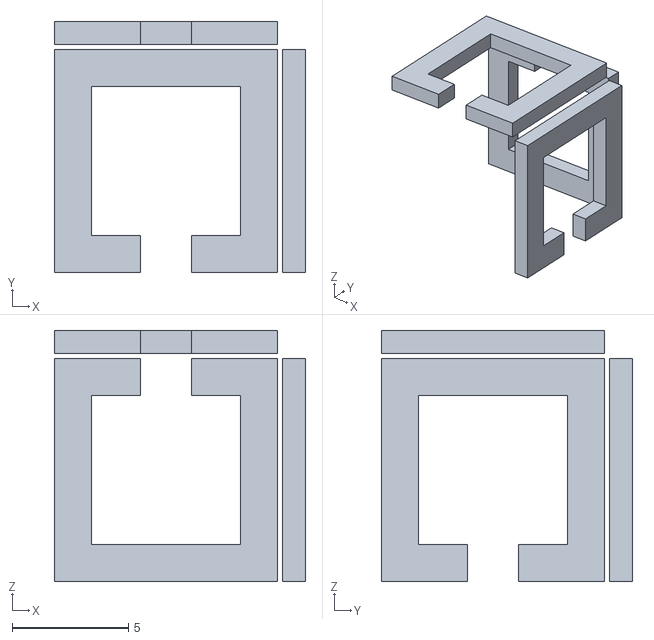
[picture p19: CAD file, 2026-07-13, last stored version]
01_PhD_Research/09/sources/phd/P/01/05_HSX_ChatGPT_Windows_App/outputs/cad/50A_CERAMIC_NFF.stl
10.8 x 10.8 x 10.8

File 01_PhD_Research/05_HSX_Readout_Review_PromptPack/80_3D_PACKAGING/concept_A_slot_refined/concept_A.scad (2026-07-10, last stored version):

// concept_A.scad — CONCEPT A "Refined slotted cube + flying leads" (baseline, §F seed S4)
// -----------------------------------------------------------------------------
// The user's slotted-cube idea made buildable:
//   - 15 mm zirconia cube; per face an OPEN-FRONT vertical slot (not an enclosed
//     internal cavity like his CAD): carrier slides DOWN from the top edge,
//     riding on two edge rails that touch ONLY the outer 0.4 mm rim of the
//     carrier back face -- die/bond wires face OUT through a 7.0 mm window
//   - BeCu bow spring at the slot back preloads the carrier against the rails
//   - Ti keeper strip across the top of each slot (1 screw) stops back-out
//   - ELECTRICAL: no contacts in the mount -- four 34 AWG Kapton-insulated
//     flying leads are pre-attached (vacuum-grade solder or parallel-gap weld)
//     to castellations 1/6/11/16 of each carrier BEFORE insertion and exit
//     through the top slot mouth. Carrier is mechanically reusable; the lead
//     attachment is semi-permanent -> fails the strict reusability gate.
// Render: openscad -o concept_A_iso.png --imgsize=1400,1050 --projection=p \
//         --camera=0,0,0,55,0,25,0 --viewall --autocenter concept_A.scad
// -----------------------------------------------------------------------------

SECTION = 0;

ENV_D = 31.75; ENV_H = 27.5; show_envelope = true;
LCC = 8.89; LCC_T = 1.65; CAV_OP = 6.10;

CUBE   = 15.0;
SLOT_W = 9.30;      // slot width across carrier (LCC max 9.14 + clearance)
SLOT_T = 2.60;      // slot depth into face: carrier 1.65 + bow spring 0.95
WIN    = 7.0;       // front window (die + bond wires look out through this)
RAIL   = 0.9;       // rail overlap on the carrier front rim (outside seal ring)
STAND_H= 6.5; BASE_T= 2.0; BASE_D = 18.0; EAR_Y = 12.5;
Z0 = STAND_H + BASE_T; ZC = Z0 + CUBE/2;

echo(str("cube corner radius = ", CUBE*sqrt(2)/2, " mm (<= ", ENV_D/2, ")"));
echo(str("stack height = ", Z0 + CUBE + 1.5, " mm (<= ", ENV_H, ")"));

$fn = 48;
module envelope() { color([0.8,0.1,0.1,0.10]) cylinder(h=ENV_H, d=ENV_D); }

// local coords: face at z=CUBE/2, +z out; slot opens toward +y (local "up")
module slot_cuts() {
  // slot body: from just behind the window rails to depth SLOT_T
  translate([0,1,CUBE/2-SLOT_T/2-RAIL/2+0.01])
    cube([SLOT_W, CUBE/2+SLOT_W/2-2, SLOT_T+0.02], center=true);
  // front window (rails remain each side, width (SLOT_W-WIN)/2)
  translate([0,0,CUBE/2-RAIL/2+0.01]) cube([WIN, WIN, RAIL+0.04], center=true);
  // slot mouth at the top edge (insertion + lead exit)
  translate([0,CUBE/2-1.5,CUBE/2-SLOT_T/2-RAIL/2])
    cube([SLOT_W, 3.2, SLOT_T+0.02], center=true);
  // keeper screw hole
  translate([0,CUBE/2-2.2,CUBE/2-RAIL-SLOT_T]) cylinder(h=6, d=1.8);
}

module carrier_in_slot() {
  // carrier sits behind the rails, cavity facing OUT (local +z)
  translate([0,0,CUBE/2-RAIL-LCC_T]) {
    color([1,0.95,0.72]) difference() {
      linear_extrude(LCC_T) square(LCC, center=true);
      translate([0,0,LCC_T-0.75]) linear_extrude(1) square(CAV_OP, center=true);
      translate([0,0,LCC_T-1.15]) linear_extrude(1) square(4.06, center=true);
    }
    color([0.25,0.28,0.32]) translate([0,0,0.6]) linear_extrude(0.35) square(2.5, center=true);
  }
  // bow spring behind the carrier
  color([1.0,0.84,0.2]) translate([0,0,CUBE/2-RAIL-LCC_T-0.5])
    linear_extrude(0.4) square([2.5, LCC-1], center=true);
  // 4 flying leads out the slot mouth (schematic)
  color([0.85,0.55,0.25]) for (i=[-1.5:1:1.5])
    translate([i*1.2, LCC/2+0.2, CUBE/2-RAIL-LCC_T+0.6])
      rotate([-90,0,0]) cylinder(h=CUBE/2-LCC/2+2, d=0.4);
  // Ti keeper strip
  color([0.62,0.65,0.68]) translate([0,CUBE/2-2.2,CUBE/2-0.01])
    linear_extrude(0.8) difference() { square([SLOT_W+2,2.6], center=true); circle(d=1.8); }
  color([0.55,0.58,0.62]) translate([0,CUBE/2-2.2,CUBE/2+0.79]) cylinder(h=1.0, d=3.0);
}

module on_px() { translate([0,0,ZC]) rotate([0, 90,0]) rotate([0,0,90]) children(); }
module on_py() { translate([0,0,ZC]) rotate([-90,0,0]) rotate([0,0,180]) children(); }
module on_pz() { translate([0,0,ZC]) children(); }

module zirconia_body() color([0.93,0.92,0.86]) difference() {
  union() {
    translate([0,0,ZC]) cube(CUBE, center=true);
    translate([0,0,STAND_H]) cylinder(h=BASE_T, d=BASE_D);
    for (s=[1,-1]) translate([0,0,STAND_H]) linear_extrude(BASE_T) hull() {
      translate([0, s*EAR_Y]) circle(d=5); translate([0, s*7]) circle(d=5); }
  }
  on_px() slot_cuts();
  on_py() slot_cuts();
  on_pz() slot_cuts();
  for (s=[1,-1]) translate([0,s*EAR_Y,STAND_H-1]) cylinder(h=BASE_T+2, d=2.2);
}

module standoffs() color([0.55,0.58,0.62]) for (s=[1,-1])
  translate([0,s*EAR_Y,0]) { cylinder(h=STAND_H, d=4.8, $fn=6);
    translate([0,0,STAND_H]) cylinder(h=BASE_T+1.0, d=2.0); }

module assembly() {
  standoffs(); zirconia_body();
  on_px() carrier_in_slot();
  on_py() carrier_in_slot();
  on_pz() carrier_in_slot();
}

difference() {
  union() { assembly(); if (show_envelope && SECTION==0) envelope(); }
  if (SECTION) translate([-50,-100,-10]) cube([100,100,60]);
}

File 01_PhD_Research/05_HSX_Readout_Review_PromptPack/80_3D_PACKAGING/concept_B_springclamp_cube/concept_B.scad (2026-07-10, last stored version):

// concept_B.scad — CONCEPT B "SpringClamp Cube"  (RECOMMENDED)
// -----------------------------------------------------------------------------
// Monolithic yttria-stabilized ZIRCONIA cube (15 mm) + integral base flange.
// Per carrier face (+X, +Y, +Z):
//   - drop-in pocket 9.4 sq x 2.15 deep (NO sliding -- carrier placed face-up)
//   - PEEK contact insert 9.3 sq x 1.0 carrying 4 gold-plated BeCu leaf springs
//     at the LCC mid-side pad positions (pads 1/6/11/16 per ST7)
//   - Ti grade-2 picture-frame clamp 13.4 sq x 1.0, window 7.0 sq (clears the
//     open cavity + bond wires), bearing on the carrier's outer/seal-ring rim
//   - 2x Ti M1.6 through-bolts to hex nuts on the opposite (bare) face; frame
//     lands METAL-ON-CERAMIC FLUSH -> preload set by spring geometry (0.35 mm
//     deflection), NOT by screw torque -> cannot crush the carrier
// Wire grooves (2.0 x 1.5) green-machined into the faces route each face's 4
// conductors to the bottom center hole -> down between the two Sub-C towers.
// Render: openscad -o concept_B_iso.png --imgsize=1400,1050 --projection=p \
//         --camera=0,0,0,55,0,25,0 --viewall --autocenter concept_B.scad
// Section: add -D SECTION=1
// -----------------------------------------------------------------------------

SECTION = 0;                 // 1 = cut away y>0 half for section view

// ---- envelope (hard constraints) ----
ENV_D = 31.75;               // cylinder diameter [mm]
ENV_H = 27.5;                // cylinder height   [mm] (from flange face z=0)
show_envelope = true;

// ---- LCC02046 carrier ----
LCC    = 8.89;               // body square [mm] (+0.254/-0.127 tol)
LCC_T  = 1.65;               // thickness [mm]
SEAL_OD= 7.98;               // seal-ring band OD (frame bears outside cavity)
CAV_OP = 6.10;               // cavity opening (keep-out: die + bond wires)

// ---- structure ----
CUBE     = 15.0;             // zirconia cube edge
POCKET   = 9.40;             // pocket square (LCC max 9.14 + 0.26 as-sintered margin)
POCK_D   = 2.15;             // total pocket depth = PEEK 1.0 + carrier seat 1.15
PEEK_T   = 1.0;              // contact-insert thickness
PROUD    = LCC_T - (POCK_D - PEEK_T);   // carrier proud of face = 0.50 mm
DEFLECT  = 0.35;             // spring working deflection (sets preload)
FRAME    = 13.4;             // Ti clamp frame square
FRAME_T  = 1.0;
WIN      = 7.0;              // frame window (<= SEAL_OD; > CAV_OP + margin)
STAND_H  = 6.5;              // Ti standoff height (ADJUSTABLE - Sub-C tower
                             // protrusion UNVERIFIED; spacer washers trim this)
BASE_T   = 2.0;              // integral zirconia base flange thickness
BASE_D   = 18.0;
EAR_Y    = 12.5;             // heritage 1D-mount standoff pattern (measured)
GROOVE_W = 2.0; GROOVE_D = 1.5;
Z0 = STAND_H + BASE_T;       // cube bottom face
ZC = Z0 + CUBE/2;            // cube center height

// screw line offsets per face — all magnitudes distinct so no two through-
// bolts intersect inside the cube (see doc §B)
SX = [[ 5.05,-5.05],[-5.05, 5.05]];   // +X face (u,v = y,z_local)
SY = [[ 5.15, 4.90],[-5.15,-4.90]];   // +Y face
SZ = [[ 4.95,-5.20],[-4.95, 5.20]];   // +Z face

// ---- envelope-fit echoes ----
r_frame_corner = sqrt(pow(CUBE/2+FRAME_T+1.3,2)+pow(FRAME/2,2));
echo(str("corner radius, side frame + screw head = ", r_frame_corner,
         " mm  (must be <= ", ENV_D/2, ")"));
echo(str("ear radius = ", EAR_Y+2.5, " mm (<= ", ENV_D/2, ")"));
echo(str("stack height = ", Z0+CUBE+FRAME_T+1.3, " mm (<= ", ENV_H, ")"));
echo(str("carrier proud of face = ", PROUD, " mm; spring deflection = ", DEFLECT));

$fn = 48;

module envelope() { color([0.8,0.1,0.1,0.10]) cylinder(h=ENV_H, d=ENV_D); }

// ---------- per-face features, local coords: face plane at z=CUBE/2, +z out --
module face_cuts(scr) {                       // subtracted from the cube
  // pocket
  translate([0,0,CUBE/2-POCK_D/2+0.01]) cube([POCKET,POCKET,POCK_D+0.02],center=true);
  // wire groove: from pocket -v edge to face edge (runs "down" local -y)
  translate([0,-(POCKET/2+(CUBE/2-POCKET/2)/2),CUBE/2-GROOVE_D/2+0.01])
    cube([GROOVE_W, CUBE/2-POCKET/2+0.05, GROOVE_D+0.02], center=true);
  // through-holes for the 2 frame bolts
  for (p = scr) translate([p[0],p[1],0]) cylinder(h=CUBE+6, d=1.8, center=true);
}

module peek_insert() color([0.82,0.71,0.55]) // PEEK, 4 BeCu contact bumps gold
  translate([0,0,CUBE/2-POCK_D]) {
    linear_extrude(PEEK_T) difference() {
      square(POCKET-0.1, center=true);
      square(3.0, center=true);              // wire-tail exit window
    }
    // 4 gold leaf-spring crowns at LCC mid-side pad positions
    for (a=[0:90:270]) rotate([0,0,a]) translate([3.55,0,PEEK_T])
      color([1.0,0.84,0.2]) scale([1.4,2.2,1]) sphere(d=0.9);
  }

module carrier() color([1,0.95,0.72]) {       // LCC02046, cavity up, compressed
  translate([0,0,CUBE/2-POCK_D+PEEK_T+DEFLECT]) difference() {
    linear_extrude(LCC_T) square(LCC, center=true);
    translate([0,0,LCC_T-0.75]) linear_extrude(1) square(CAV_OP, center=true);
    translate([0,0,LCC_T-1.15]) linear_extrude(1) square(4.06, center=true);
  }
  // die
  translate([0,0,CUBE/2-POCK_D+PEEK_T+DEFLECT+0.6]) color([0.25,0.28,0.32])
    linear_extrude(0.35) square(2.5, center=true);
}

module frame(scr, nut_drop=0) {                           // Ti clamp frame + button screws
  zf = CUBE/2;                                // lands flush on the ceramic face
  color([0.62,0.65,0.68]) translate([0,0,zf]) linear_extrude(FRAME_T) difference() {
    square(FRAME, center=true);
    square(WIN, center=true);
    for (p = scr) translate(p) circle(d=1.8);
  }
  // window inner relief chamfer pressing the carrier rim (visual: thin land)
  color([0.62,0.65,0.68]) translate([0,0,zf-PROUD+DEFLECT])
    linear_extrude(PROUD-DEFLECT+0.01) difference() {
      square(WIN+1.4, center=true); square(WIN, center=true); }
  for (p = scr) {
    color([0.55,0.58,0.62]) translate([p[0],p[1],zf+FRAME_T])
      cylinder(h=1.2, d=3.0);                                    // head
    color([0.55,0.58,0.62]) translate([p[0],p[1],-zf-1.3-nut_drop])
      cylinder(h=1.3, d=3.4, $fn=6);                             // hex nut
  }
}

module face_pack(scr, nut_drop=0) { peek_insert(); carrier(); frame(scr, nut_drop); }

// rotations mapping local +Z to +X / +Y / +Z
module on_px() { translate([0,0,ZC]) rotate([0, 90,0]) children(); }
module on_py() { translate([0,0,ZC]) rotate([-90,0,0]) children(); }
module on_pz() { translate([0,0,ZC])                    children(); }

module zirconia_body() color([0.93,0.92,0.86]) difference() {
  union() {
    translate([0,0,ZC]) cube(CUBE, center=true);
    translate([0,0,STAND_H]) cylinder(h=BASE_T, d=BASE_D);
    for (s=[1,-1]) translate([0,0,STAND_H])                  // ear tabs
      linear_extrude(BASE_T) hull() {
        translate([0, s*EAR_Y]) circle(d=5); translate([0, s*7]) circle(d=5); }
  }
  on_px() face_cuts(SX);
  on_py() face_cuts(SY);
  on_pz() face_cuts(SZ);
  // bottom-face wire grooves to center + center pass-through
  translate([0,0,STAND_H-0.01]) cylinder(h=BASE_T+GROOVE_D, d=5.0);
  for (a=[0,90,180,270]) rotate([0,0,a]) translate([CUBE/4,0,Z0-0.01])
    cube([CUBE/2+2, GROOVE_W, GROOVE_D*2], center=true);
  // vertical wire runs down the bare -X and -Y faces (top-face + side wires)
  translate([-CUBE/2+GROOVE_D/2-0.01,0,ZC]) cube([GROOVE_D,GROOVE_W,CUBE+0.1],center=true);
  translate([0,-CUBE/2+GROOVE_D/2-0.01,ZC]) cube([GROOVE_W,GROOVE_D,CUBE+0.1],center=true);
  // ear holes for M2 standoff screws
  for (s=[1,-1]) translate([0,s*EAR_Y,STAND_H-1]) cylinder(h=BASE_T+2, d=2.2);
}

module standoffs() color([0.55,0.58,0.62]) for (s=[1,-1])
  translate([0,s*EAR_Y,0]) { cylinder(h=STAND_H, d=4.8, $fn=6);
    translate([0,0,STAND_H]) cylinder(h=BASE_T+1.0, d=2.0); } // M2 Ti screw

module assembly() {
  standoffs();
  zirconia_body();
  on_px() face_pack(SX);
  on_py() face_pack(SY);
  on_pz() face_pack(SZ, BASE_T);
}

difference() {
  union() { assembly(); if (show_envelope && SECTION==0) envelope(); }
  if (SECTION) translate([-50,-100,-10]) cube([100,100,60]);   // cut y<0
}

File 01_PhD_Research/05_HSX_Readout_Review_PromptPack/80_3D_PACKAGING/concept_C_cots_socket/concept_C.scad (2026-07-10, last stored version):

// concept_C.scad — CONCEPT C "COTS LCC-20 socket per face" (§F seed S3) — REJECTED
// -----------------------------------------------------------------------------
// Screening model: three commercial LCC-20 open-top burn-in/test sockets
// (generic Aries/Plastronics-class geometry: ~16.5 mm sq body, ~7 mm tall,
// requires a carrier PCB ~1.6 mm) mounted on the faces of a 14 mm cube.
// PURPOSE OF THIS MODEL: show the envelope violation quantitatively.
//   socket corner radius = cube/2 + PCB + socket height, out at the socket
//   body corners -> ~17.9 mm > 15.875 mm allowed  => DOES NOT FIT (3 faces).
// Independent kill criteria (see PACKAGING_3D_DESIGN.md §C-C):
//   - contacts are Au OVER NICKEL plated BeCu (ferromagnetic Ni) per Aries
//     materials spec -> disqualified next to a Hall plate
//   - socket plastics (glass-filled PPS/LCP) unrated for UHV outgassing
//   - rated -55..+150 C (burn-in), marginal for in-vessel bake
//   - needs a PCB (FR4/polyimide + ENIG = more Ni) to terminate to
// Render: openscad -o concept_C_iso.png --imgsize=1400,1050 --projection=p \
//         --camera=0,0,0,55,0,25,0 --viewall --autocenter concept_C.scad
// -----------------------------------------------------------------------------

SECTION = 0;

ENV_D = 31.75; ENV_H = 27.5; show_envelope = true;
LCC = 8.89; LCC_T = 1.65;

CUBE   = 14.0;      // even with a minimal cube...
SOCK   = 16.5;      // generic LCC-20 open-top socket body square [mm]
SOCK_H = 7.0;       // body height incl. latch lid (typ. class value)
PCB_T  = 1.6;       // socket must be soldered to a board
STAND_H= 5.0; BASE_T= 2.0; BASE_D = 18.0; EAR_Y = 12.5;
Z0 = STAND_H + BASE_T; ZC = Z0 + CUBE/2;

r_sock = sqrt(pow(CUBE/2+PCB_T+SOCK_H,2)+pow(SOCK/2,2));
echo(str("VIOLATION: side-socket corner radius = ", r_sock,
         " mm  > allowed ", ENV_D/2, " mm"));
echo(str("VIOLATION: socket body corner (radial faces) = ",
         sqrt(2)*SOCK/2 + 0, " mm half-diag on a ", CUBE, " cube"));
echo(str("stack height = ", Z0+CUBE+PCB_T+SOCK_H, " mm (limit ", ENV_H, ")"));

$fn = 48;
module envelope() { color([0.8,0.1,0.1,0.10]) cylinder(h=ENV_H, d=ENV_D); }

module socket_stack() {  // local: face at z=CUBE/2, +z out
  color([0.2,0.5,0.2]) translate([0,0,CUBE/2])                  // PCB
    linear_extrude(PCB_T) square(SOCK+1.5, center=true);
  color([0.15,0.15,0.18]) translate([0,0,CUBE/2+PCB_T]) {       // socket body
    linear_extrude(SOCK_H-2.2) square(SOCK, center=true);
    translate([0,0,SOCK_H-2.2]) linear_extrude(2.2) difference() {
      square(SOCK, center=true); square(SOCK-4, center=true); } // open-top lid
  }
  color([1,0.95,0.72]) translate([0,0,CUBE/2+PCB_T+2.0])        // LCC inside
    linear_extrude(LCC_T) square(LCC, center=true);
}

module on_px() { translate([0,0,ZC]) rotate([0, 90,0]) children(); }
module on_py() { translate([0,0,ZC]) rotate([-90,0,0]) children(); }
module on_pz() { translate([0,0,ZC]) children(); }

module body() color([0.93,0.92,0.86]) {
  translate([0,0,ZC]) cube(CUBE, center=true);
  translate([0,0,STAND_H]) cylinder(h=BASE_T, d=BASE_D);
  for (s=[1,-1]) translate([0,0,STAND_H]) linear_extrude(BASE_T) hull() {
    translate([0, s*EAR_Y]) circle(d=5); translate([0, s*7]) circle(d=5); }
}

module standoffs() color([0.55,0.58,0.62]) for (s=[1,-1])
  translate([0,s*EAR_Y,0]) cylinder(h=STAND_H, d=4.8, $fn=6);

module assembly() {
  standoffs(); body();
  on_px() socket_stack(); on_py() socket_stack(); on_pz() socket_stack();
}

difference() {
  union() { assembly(); if (show_envelope && SECTION==0) envelope(); }
  if (SECTION) translate([-50,-100,-10]) cube([100,100,60]);
}

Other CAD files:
01_PhD_Research/09/sources/phd/P/01/05_HSX_ChatGPT_Windows_App/outputs/cad/50B_SERVICE_KEEPOUTS_NFF.step
01_PhD_Research/09/sources/phd/P/01/05_HSX_ChatGPT_Windows_App/outputs/cad/50A_HARNESS_KEEPOUTS_NFF.step
01_PhD_Research/09/sources/phd/P/01/05_HSX_ChatGPT_Windows_App/outputs/cad/30A_triplate_cage_ceramic_NOT_FOR_FABRICATION.stl
01_PhD_Research/09/sources/phd/P/01/05_HSX_ChatGPT_Windows_App/outputs/cad/30C_split_cassette_ceramic_NOT_FOR_FABRICATION.stl
01_PhD_Research/05_HSX_Readout_Review_PromptPack/80_3D_PACKAGING/concept_D_triplate_corner/concept_D.scad
01_PhD_Research/05_HSX_ChatGPT_Windows_App/outputs/cad/30A_triplate_cage_ceramic_NOT_FOR_FABRICATION.stl
01_PhD_Research/05_HSX_ChatGPT_Windows_App/outputs/cad/30B_monolithic_core_NOT_FOR_FABRICATION.step
01_PhD_Research/05_HSX_ChatGPT_Windows_App/outputs/cad/30B_monolithic_core_ceramic_NOT_FOR_FABRICATION.stl
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

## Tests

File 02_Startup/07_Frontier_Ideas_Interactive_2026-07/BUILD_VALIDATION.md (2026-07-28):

# Build validation

Build date: 2026-07-27

## Imported data

- Uploaded package SHA-256 verified:
  `9846F5E2B06804690A74A0F57313109B62B7E3ECE0E5238755F7084D1FB578AA`.
- `src\06` contains exactly 419 files.
- All 419 files match `SOURCE_SHA256.json`.
- Frozen counts independently verified:
  - 126 raw ideas / 126 unique IDs;
  - 65 longlist ideas / 65 unique IDs;
  - 1,289 source rows / 1,289 unique IDs / 1,182 accepted;
  - historical completed 24/10 selection and ten deep dives.
- The uploaded package contained no completed top-level rerun output, state, or
  logs to import.

## Fresh implementation

The active scripts, hooks, settings, route, and prompts were rebuilt. The
previous stream-JSON parser, exact text sentinel, stage child launcher, budget
flags, turn caps, and non-persistent sessions are not used.

## Offline tests completed in the build workspace

- Parsed all new JSON configuration and fixture files.
- Verified all frozen source hashes and counts.
- Built deterministic fixtures for every pilot and full stage.
- Verified fixture cardinalities and cross-stage identities:
  65 → 30 → 24 → 10.
- Verified source-pack 20/7/5 quotas.
- Verified ten deep-dive fixtures and actual word counts.
- Verified final 24-row CSV and final PASS audit fixture.
- Checked balanced strings, parentheses, brackets, and braces in every active
  PowerShell script.
- Scanned active launch paths for package-defined monetary, turn, and
  no-persistence flags; none are present.
- Maximum static relative path is 75 characters. Extraction to `C:\AI\F06I`
  leaves substantial Windows path headroom.

## Runtime gates

This build environment is not Windows and cannot execute the user's exact
Windows PowerShell binary or authenticated Claude account. Therefore the
package deliberately performs these gates locally on the user's machine before
the first model call:

1. exact Windows PowerShell 5.1.26100.8875 / Desktop / build / CLR check;
2. native PS5.1 parser check for every active script;
3. package and source SHA-256 verification;
4. all eight stage/pilot fixtures through `VALIDATE.ps1`;
5. SessionStart, status, event, Stop-guard, first-retry, and second-pause hook
   fixtures;
6. Claude Code presence and version display;
7. actual interactive SessionStart model capture and live status effort/
   performance logging.

Claude is not launched if any offline/runtime prerequisite fails. Live research
cannot be pre-executed without the user's Claude authentication and usage
allocation; it is the intended work performed after the one-command gates.

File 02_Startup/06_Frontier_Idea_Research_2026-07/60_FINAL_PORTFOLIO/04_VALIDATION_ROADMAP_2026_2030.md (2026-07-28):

# Validation roadmap, 2026-2034

The filename is retained for compatibility; the operating roadmap extends through 2034.

## Portfolio sequence

| Year | Decision objective | Required evidence | Kill rule |
|---|---|---|---|
| 2026 | Freeze exact product jobs and interfaces | Named buyer workshops, incumbent teardowns, standards map, facility-access quotes | Stop any idea whose buyer owns no separable merchant socket |
| 2027 | Build the minimum falsifier | Traceable prototype or emulator, blinded protocol, signed data/access terms | Stop on physics shortfall, unsafe integration, or incumbent parity |
| 2028 | Run independent qualification | Repeatable third-party results across representative loads | Stop if the edge disappears outside the home bench |
| 2029 | Secure procurement engagement | Paid evaluation, design-in memorandum, budget line, or qualification slot | Stop without a buyer-controlled next step by year-end |
| 2030 | Make launch decisions | Frozen v1, qualified supply chain, service model, compliance checklist | Launch only the few ideas with evidence, not the whole portfolio |
| 2031-2032 | Convert pilots to repeatable sales | Acceptance dossier, field reliability, price and service benchmarks | Stop custom projects that cannot become repeatable products |
| 2033-2034 | Expand ratings and adjacent buyers | Reference deployments, recurring calibration/support, second-source readiness | Stop if the original trigger sunsets or an incumbent bundles the wedge |

## Cheapest decisive experiments

| Idea | Budget | Test | Procurement signal by 2029 |
|---|---:|---|---|
| `P3R2-C-01` | $48,000 | Merchant-module boundary falsification (4 months; $48,000). Pre-register: Freeze combined-module boundary, three required counterparties, evidence form, 2029 design-in horizon, and no-credit rules for verbal interest. Pass: Two integrators provide written requirement redlines; At least one counterparty signs a paid evaluation assigning protection, precharge, IMD, and sequencing to a replaceable third-party module through 2029. Kill: All counterparties allocate functions to fuses, internal shelves, or platform standards; No paid evaluation or replaceable socket. Budget: specification mapping $10,000, fmeca and safety case $6,000, interface control document $8,000, integrator workshops $8,000, china screening and counsel $8,000, evaluation contracting $4,000, independent review $4,000. | Required and immediately testable |
| `P5-USSCI2-S01` | $94,000 | 2027-2028, nine months: procure at least 12 CVD diamond films spanning thickness and doping; laser/RIE thin them; apply two NEA treatments and two electrode schemes; map reflection and transmission electron yield in UHV before and after a 200 C bake and after an accumulated input charge test. Pass only if four membranes independently show transmission yield >=8 at <=3 keV, within-wafer yield coefficient of variation <=15%, dark current <=10 nA at the operating bias, <=10% yield loss after bake, and <=20% loss after the accelerated charge dose. Kill on surface instability in air transfer, destructive charging, timing spread >50 ps attributable to the dynode in a pulsed-electron test, or if two tube integrators say the mount cannot be sealed. | Required and immediately testable |
| `P3R2-C-13` | $72,000 | Cross-market make-versus-buy and paid-evaluation gate (5 months; $72,000). Pre-register: Name prospects, freeze interface and claimed telemetry/TMI value, minimum $25,000 evaluation, incompatible-control rule, and no-credit rules for host-system spending. Pass: Two paid evaluations >=$25,000 each, one per market; Both accept a merchant electrical interface; US controls remain compatible with a fully separated screened CN line. Kill: Fewer than two paid evaluations; OEMs keep drivers as core IP; Required cross-market controls make the economics nonviable. Budget: interface bom and safety plan $12,000, tmi and health data room $10,000, twelve oem workshops $18,000, export and counterparty screening $12,000, paid evaluation contracting $10,000, independent make buy analysis $5,000, contingency $5,000. | Required and immediately testable |
| `P3R2-C-08` | $65,000 | Incumbent-limit and buyer-funded qualification gate (5 months; $65,000). Pre-register: Freeze VPE/Heatric comparison, full-core transient envelope, required measured incumbent failure, funding threshold, and no-credit rule for missing public datasheets. Pass: Buyer provides a measured incumbent transient limit; Buyer names a required target the incumbent cannot meet; Paid development agreement funds the subsequent $400k-$600k core program. Kill: No measured incumbent gap; Buyer will not fund development; Target is already inside incumbent capability. Budget: transient requirement definition $12,000, oem epc workshops $14,000, incumbent gap benchmark $10,000, paid development contracting $8,000, bonder and test quotes $8,000, fto and code review $9,000, independent review $2,000, contingency $2,000. | Required and immediately testable |
| `P3R2-B-01` | $55,000 | Incumbent teardown and paid leak-direction requirement gate (4 months; $55,000). Pre-register: Freeze Envicool comparison, inward-leak definition, three buyer targets, mandatory paid-criterion evidence, and incumbent-addability rule. Pass: One buyer states inward-leak behavior is mandatory and unmet; Buyer signs paid evaluation; Incumbent cannot add feature without material redesign. Kill: Incumbent already controls subatmospheric pressure; No buyer prices leak direction; Feature is an easy incumbent firmware/control addition. Budget: incumbent material and teardown $10,000, function map $8,000, three cn buyer workshops $12,000, standards and service analysis $8,000, paid evaluation contracting $8,000, ip and licensing counsel $5,000, independent review $2,000, contingency $2,000. | Required and immediately testable |
| `P3R2-E-04` | $60,000 | Post-2029 external-I/O architecture socket test (3 months; $60,000). Pre-register: Freeze two builders and one refrigerator OEM, 2029-2033 I/O budget fields, >=1,000-channel external socket, cold-mux accounting, and 20% demo funding threshold. Pass: One written post-2029 external loader socket >=1,000 channels; One buyer funds >=20% of the later integration demo; Refrigerator OEM accepts interface. Kill: All roadmaps internalize into cold electronics/modular links/incumbent stack; No buyer funding; No refrigerator interface. Budget: io architecture model $12,000, two builder workshops $12,000, refrigerator oem workshop $8,000, export classification $8,000, integration socket memorandum $8,000, paid codevelopment negotiation $6,000, independent review $4,000, contingency $2,000. | Required and immediately testable |
| `P3R2-F-12` | $75,000 | Standalone marine-stack RFQ and class-boundary test (5 months; $75,000). Pre-register: Freeze competitor scope, separable stack boundary, three non-integrated buyer targets, minimum funding, screened-partner rule, and evidence form. Pass: Two buyers issue standalone RFQs or paid design letters; One funds >=$25,000; A screened non-CSSC-affiliated manufacturer accepts architecture; Class adviser confirms a separable approval path. Kill: Functions remain bundled with battery/BMS; No funded study; No screened manufacturing path; No separable class scope. Budget: ccs concept review $15,000, competitor certificate map $12,000, interface architecture $10,000, shipyard and integrator workshops $12,000, partner screening $8,000, paid design contracting $8,000, independent class adviser $6,000, contingency $4,000. | Required and immediately testable |
| `P3R2-G-03` | $38,000 | Paid commissioning-socket test (6 months; $38,000). Pre-register: Name 15 US operators/commissioners and 10 screened CN integrators, freeze the swept-impedance/IT-network scope, current-stack comparison, evidence form, and geographic pass rules. Pass: One US counterparty pays >=$15,000 for a controlled pilot; One CN counterparty signs an enforceable paid pilot or frame term naming a test its current stack cannot perform. Kill: No paid product-specific demand in either geography; All buyers accept load-bank or incumbent commissioning without the proposed method. Budget: protocol and analyzer emulator $10,000, structured us and cn workshops $12,000, legal and counterparty diligence $8,000, paid pilot contracting $4,000, independent decision audit $4,000. | Required and immediately testable |
| `P3R2-F-23` | $45,000 | Three-party command, warranty, and finance-rights gate (4 months; $45,000). Pre-register: Freeze variables, command authority, warranty consequence, data rights, minimum $25,000 follow-on funding, and no-credit rule for generic lender interest. Pass: Three-party signed term sheet grants command authority; Logged variables explicitly affect warranty or financing; At least $25,000 follow-on funding. Kill: OEM controller remains sole authority; Lender accepts only OEM/EPC guarantees; No data rights or funding. Budget: warranty and command matrix $8,000, oem developer workshops $10,000, lender technical adviser $8,000, legal and data rights $8,000, term sheet negotiation $5,000, controller mockup $3,000, independent review $2,000, contingency $1,000. | Required and immediately testable |
| `P3R2-F-06` | $35,000 | Unbundled wideband-sensor socket test (6 months; $35,000). Pre-register: Freeze DC-to-100 kHz requirement, incumbent baseline request, six targets, unbundled interface, and paid NRE threshold. Pass: One buyer signs paid evaluation/NRE; Agreement names unbundled interface and supplies incumbent baseline; Requirement is not met by vertically integrated sensor. Kill: All buyers require proprietary station package; No paid evaluation; No buyer-valued bandwidth/accuracy gap. Budget: requirement architecture $8,000, oem epc workshops $10,000, interface and baseline definition $5,000, qualification and export review $4,000, paid evaluation contracting $4,000, independent review $2,000, contingency $2,000. | Required and immediately testable |
| `P3R2-F-03` | $68,000 | Electrical-cartridge OEM socket test (4 months; $68,000). Pre-register: Freeze one narrow rating, price, warranty, service scope, eight OEMs, minimum $150,000 co-development, and no-credit rules for integrated end-customer orders. Pass: Two unrelated OEMs externalize the same electrical island; One commits >=$150,000 paid NRE or purchase; Interface excludes incumbent-integrated cases. Kill: Fewer than two externalize; No paid commitment; Only complete-turbine vendors show demand. Budget: interface and rating specification $12,000, oem workshops $16,000, make buy and warranty model $10,000, lifecycle cost model $8,000, export and standards $6,000, paid nre negotiation $8,000, independent review $4,000, contingency $4,000. | Required and immediately testable |

## Portfolio operating rules

1. Run merchant-socket and acceptance-boundary tests before expensive hardware whenever that is the load-bearing uncertainty.
2. Pre-register thresholds and name the incumbent benchmark. A favorable demo without a kill threshold does not advance an idea.
3. Keep US and China validation evidence separate. Success in one country does not establish the other route.
4. Refresh facility schedules, standards, restricted-party screening, and procurement records every six months through launch.
5. Preserve a barbell: several cheap commercial falsifiers, plus only a few capital-intensive physics programs after access is signed.

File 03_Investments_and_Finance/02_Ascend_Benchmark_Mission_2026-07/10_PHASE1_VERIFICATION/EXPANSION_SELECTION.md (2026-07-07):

Educational benchmark for a paper-trading learning exercise. Simulated allocations, not investment advice or recommendations.

# EXPANSION_SELECTION — accuracy-patch PP1: +5 names (selection rationale)

Date: 2026-07-07. Selector: orchestrator (session model), per PATCH_BRIEF PP1.
Criteria (binding, from the brief): (1) lead strength — tier-B-or-better evidence
plausibly available from filings/named media; (2) layer diversity vs the existing
14-name universe. Candidate pool = **documented leads only** — no new discovery searching
was done for this selection; every candidate below cites where v1 or the prior corpus
recorded it. This file ranks nothing and implies nothing about any existing name's score.

## Layer coverage of the existing 14 (from 05_STATE/UNIVERSE.csv)

server distribution (000034); server integrator (000628, 002261, 600839); advanced
packaging OSAT (002156); optical modules (002281, 300308); fab equipment (002371);
PCB/substrate (002916); liquid cooling (301018); ISV/all-in-one (301236); server+optical
(600498); high-speed connectors (688629); foundry (688981).
**Absent layers with documented leads:** power (PSU/power ICs), packaging materials,
switching silicon, upstream CCL. **Thin:** PCB/substrate (one name, tier C).

## Candidate pool (all documented leads)

| Candidate | Layer | Documented lead | Pool tier |
|---|---|---|---|
| 华虹半导体 688347 | foundry | v1 DISCOVERY in V_688981 (S285: TrendForce 2026-02-25 names Hua Hong alongside SMIC in the Ascend-950-driven 7/5nm-class buildout); logged noted-not-added in A10 | **B** (already on file) |
| 意华股份 002897 | connectors | S204 西部证券 weekly bare-list; RB_02 [S009] | C (bare-list) |
| 航天电器 002025 | connectors | S204 西部证券 weekly bare-list only | C (bare-list) |
| 科大讯飞 002230 | AI applications | A10: rejected — chain role is Ascend compute BUYER, not supplier | n/a (fit fails) |
| 泰嘉股份 002843 | power (PSU, via 深圳雅达) | RB_02 power row [S009] | C |
| 杰华特 688141 | power (DrMOS/DC-DC ICs) | RB_02 power row [S009] | C |
| 英维克 002837 | liquid cooling | RB_02 [S008;S009]; A10: did NOT clear tier ≤B for Ascend during v1 wave-3 verification | <B (documented negative) |
| 兴森科技 002436 | PCB / IC substrate | RB_02 PCB/CCL/substrate row, tier B–C [S009;S010] | B–C |
| 南亚新材 688519 | CCL | RB_02 same row [S009;S010]; also named in the S009 Ascend-chain roll | B–C |
| 华海诚科 688535 | packaging materials (EMC) | RB_02: "Molding compound for Ascend" [S009] | C |
| 盛科通信 (STAR; ticker not recorded in RB_02) | switching silicon | RB_02 switching row [S008] | C |

## Selected 5

1. **华虹半导体 688347 — foundry.** The single strongest documented lead in the pool:
   the only candidate already substantiated at tier B this mission (V_688981 DISCOVERY,
   S285), and the brief's priority class (a). Adds a second foundry data point; per A20
   it shares the foundry cap-group with 688981, so the value is evidence depth on the
   chain's bottleneck layer, not layer count. Auditor hypotheses to test: does any
   filing/IR reply tie 华虹 capacity to Huawei/Ascend-linked demand; mature-node
   (power/driver IC) share vs advanced-logic claims; A-share (688347) vs H-share
   (1347.HK) disclosure differences.
2. **杰华特 688141 — power management ICs (absent layer).** RB_02 documents the
   DrMOS/DC-DC server-power lead. STAR-board listing means a prospectus + 问询函 trail
   with named customers/shareholders is likely retrievable — a realistic tier-A/B path.
   Auditor hypotheses: any Huawei-affiliated shareholder in the prospectus top-10 list;
   any 互动易/上证e互动 reply on 华为/昇腾/服务器电源; design-win disclosures for
   AI-server power stages.
3. **兴森科技 002436 — PCB / IC substrate (thin layer, tier-C incumbent).** RB_02
   carries it at B–C for ABF/FCBGA substrate — the package-substrate chokepoint that
   advanced-packaging of AI silicon depends on. The layer's current evidence base is
   weak (incumbent 002916 verified at tier C / NOT-ESTIMABLE in v1), so a second,
   possibly better-disclosed name raises the layer's answer-key quality either way.
   Auditor hypotheses: FCBGA substrate capacity/qualification disclosures (珠海 lines);
   any named domestic AI-chip or HiSilicon-linked substrate business in filings/IR.
4. **华海诚科 688535 — packaging materials, EMC (absent layer).** RB_02's lead is
   Ascend-specific on its face ("molding compound for Ascend"). Small STAR-board
   specialty-materials name; recent-IPO prospectus + 问询函 give a plausible tier-A/B
   documentation path (named OSAT customers; advanced-packaging EMC qualification).
   Auditor hypotheses: which OSATs it supplies (通富/长电/华天), whether any disclosure
   ties EMC grades to AI/advanced packaging, revenue scale of that grade.
5. **南亚新材 688519 — CCL, upstream laminate (absent sub-layer).** Named in both
   prior-corpus sources for the layer [S009;S010]. CCL for AI-server boards is the
   materials input one step above 002916/002436; historic Huawei-qualified-supplier
   status is a commonly repeated claim the auditor must confirm or kill from filings/IR.
   Per A20 it caps with the boards/substrate group. Auditor hypotheses: any named
   Huawei/server-customer disclosure; high-speed (M6/M7-grade) laminate revenue share;
   AI-server-linked volume statements with dates.

## Not selected (documented reasons; no ranking implied)

- **意华股份 002897 / 航天电器 002025** — lead is a bare-list mention in one 西部证券
  weekly (S204, confirmed bare by two independent reads in v1); the connector layer is
  already covered at tier A/B by 688629. Both A10 rejection reasons stand unchanged.
- **科大讯飞 002230** — buyer of Ascend compute, not a supply-chain member; fit fails
  (A10 reasoning stands).
- **英维克 002837** — v1 wave-3 already searched and found the Ascend link does not
  clear tier ≤B (A10); no new documented lead has appeared since. Re-selecting it would
  spend a slot re-running a documented negative.
- **泰嘉股份 002843** — legitimate power-layer lead (via 深圳雅达), but one power name
  covers the absent layer and 杰华特's STAR-board disclosure trail offers the stronger
  tier-A/B path; taking both would double one layer while packaging materials or CCL
  went uncovered.
- **盛科通信** — weakest documented lead in the pool (single tier-4-sourced row, no
  ticker recorded in the corpus) plus a structural reason for doubt: Huawei designs its
  own switching silicon, so a Huawei-chain supplier role is likelier to verify UNVERIFIED
  than B-or-better. With five slots, expected evidence strength loses to the picks above.

## Mechanics

Universe: 14 → 19 (within no cap — v1's ≤18 cap governed v1 Phase 1; the patch brief
fixes the addition count at exactly +5). S-ID blocks per A17: 688347 S900–S919, 688141
S920–S939, 002436 S940–S959, 688535 S960–S979, 688519 S980–S999 (PP2/PP3 blocks in
A17). Full v1 treatment: filing-auditor → fundamentals-analyst → valuation-analyst,
same schemas and gates as v1; transport per A18. No existing name's row, tier, or file
is modified by this selection.

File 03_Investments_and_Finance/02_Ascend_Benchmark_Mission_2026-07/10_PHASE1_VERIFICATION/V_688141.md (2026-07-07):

Educational benchmark for a paper-trading learning exercise. Simulated allocations, not investment advice or recommendations.

# V_688141 — 杰华特 Joulwatt Microelectronics (SSE-STAR) — Huawei/Ascend link verification

Audited: 2026-07-07 (accuracy-patch PP1). Process note: the assigned filing-auditor run was
interrupted before writing output; this audit was rerun inline by the orchestrator in the same
session (CLAUDE.md rule 10), same procedure and standards. Sources S920–S931.

## Claim under test

RB_02 power row [S009, tier 4]: 杰华特 supplies DrMOS / DC-DC power-management silicon into the
Huawei/Ascend AI-server chain. Secondary hypothesis (EXPANSION_SELECTION): a Huawei-affiliated
shareholder appears in the register — an ecosystem-affinity fact, not a supply link.

## Evidence walk

**1. Own filings (tier 1).** FY2025 annual report full text (fetched via 新浪财经 statutory
disclosure reproduction [S920]): revenue CNY 2,655,024,754.75 (+58.15% YoY); 归母净利润
−717,124,210.22 (loss); R&D CNY 957.28M = 36.06% of revenue; product split: DC-DC CNY 1,414.85M
(53.29% of revenue), AC-DC CNY 513.45M, 信号链 CNY 257.13M, BMS CNY 22.60M. Top-5 customers =
CNY 1,068.83M = 40.26%, all anonymized. **The extract surfaced no 华为/昇腾/鲲鹏 mention anywhere
in the AR business text** — the company's own FY2025 filing does not name Huawei or Ascend.
H1-2025 report and announcement 2025-051 PDFs: password-protected to both WebFetch and the
local-Read fallback (trail below), so an in-filing Huawei-mention scan of those two docs was not
possible this session.

**2. Customer concentration, three years (tier 3 cross-table [S925], consistent with AR [S920]).**
FY2023: top-5 46.46%, #1 = 30.66%. FY2024: top-5 40.70%, #1 = 26.44%. FY2025: top-5 40.26%,
#1 = 30.04% (≈CNY 798M). One dominant, never-named customer has held ~26–31% of revenue for three
straight years. IPO-era precedent for aggressive anonymization [S926, 2022-04-14]: related-party
"A公司" was 2020's largest customer (CNY 41.46M, >10% of revenue; prospectus declined to describe
its background), replaced by "B公司" at 32% of 2021 1–9月 revenue (CNY 213M). No source in this
audit identifies any of A公司/B公司/current 第一名. Per rule A8 the anonymous #1 is NOT equated
with Huawei.

**3. Huawei equity link (fact, but equity ≠ revenue).** 哈勃系 (Huawei's Hubble vehicles) held
3.48% + 0.93% = 4.41% pre-IPO (prospectus-era reporting [S927 snippet]); 哈勃科技创业投资 held
3.03% as of the FY2023 AR, alongside Intel Asia-Pacific R&D 2.96% and 中信证券 2.02% [S922,
fetched, 2025-02-20]. Establishes ecosystem affinity only.

**4. Named sell-side placement in the Ascend chain (tier 3, the B-tier anchor).** 国盛证券
Ascend-supply-chain deep-dive, 2025-05-06, named analysts 郑震湘/佘凌星/刘嘉元 [S924, fetched]:
"杰华特DrMOS和多相控制器产品已量产爬坡" — stated inside the report's domestic-compute power
section, whose same section notes "Atlas系列服务器电源模块也在升级". Caveat recorded: the report
places 杰华特's product ramp in the Ascend-chain context; it does NOT state a direct
杰华特→Huawei/Atlas supply contract, and no company filing or IR reply found this session does
either. Product-level server-power capability is corroborated by media coverage of 30A–90A DrMOS
and 6/8/12-phase controllers in mass-production ramp for server/AI applications (search color,
multiple outlets, e.g. relayed AR language "高集成度电源管理芯片在服务器领域渗透率显著提升"
[S929, snippet]).

**5. Rejected tier-4 lead.** 东方财富财富号 blogger post "杰华特：营收大增，绑定华为昇腾！"
(2026-04-26) [S930]: the "绑定" (locked-in) claim has zero primary or named-media corroboration —
logged as lead-only, non-load-bearing per SOURCE_STANDARDS.

**6. Context (snippet, color only).** H-share listing: applied 2025-05-30, resubmitted 2026-01-13,
draft status [S928]; 10M-2025 revenue CNY 2,113M; Frost & Sullivan 2024: #6 global / #2 China in
DC-DC ICs (1.9% share), #13 global analog (0.9%) [S928]. FY2025 guidance range 26.0–27.5亿
published 2026-02-02 [S931]; actual 26.55亿 [S920] landed inside it. FY2025 loss drivers per the
abnormal-fluctuation notice relay [S921, 2026-06-11]: sustained R&D/market/admin spend; Q1-2026
归母净利润 −276M (扣非 −294M).

## Tier ruling: **B**

A named major-house sell-side report (tier 3 per SOURCE_STANDARDS → evidence tier B) explicitly
situates 杰华特's server-power silicon ramp in the Ascend chain [S924]; the Hubble equity stake is
filing-grade but is an investment link, not a customer link; the company's own FY2025 AR text
names neither Huawei nor Ascend [S920], and no 互动易/上证e互动 company reply on the subject could
be retrieved this session (trail below). Not A (no own-filing/official-reply naming); well above
UNVERIFIED/C (multiple named, dated, non-forum sources).

## Exposure estimate: **NOT-ESTIMABLE (point); ceilings stated**

No source decomposes revenue by end-customer or end-system. Two non-Huawei-specific ceilings,
both gross over-statements of any true Ascend share: (a) anonymous #1 customer = 30.04% of FY2025
revenue [S925; identity unproven, per A8 not equated with Huawei]; (b) DC-DC product line = 53.29%
of FY2025 revenue [S920; spans PC/auto/industrial/comms end-markets, not only servers]. The
Ascend-specific slice within either cut is undisclosed → NOT-ESTIMABLE.

## Key quotes

- "杰华特DrMOS和多相控制器产品已量产爬坡" — 国盛证券昇腾产业链深度, 2025-05-06 [S924]
- "高集成度电源管理芯片在服务器领域渗透率显著提升" — FY2025 AR language, press relay 2026-03-31
  [S929, snippet]
- FY2025 top-5 customers 40.26%, 第一名 30.04%, all anonymized [S920; S925]

## Search/fetch failure trail (documented per Gate G1)

- e互动 (sns.sseinfo.com) user/reply pages ×4 URLs from search: render platform boilerplate only,
  no Q&A content retrievable; 3 distinct searches for 杰华特 e互动/业绩说明会 华为/昇腾 replies
  surfaced no accessible company-voice reply.
- finance.ce.cn 2022-04-03 article: https→http 301 redirect loop, 2 attempts, not fetchable.
- static.cninfo.com.cn/finalpage/2025-09-02/1224633054.PDF (公告2025-051): WebFetch returned
  encrypted stream; local saved-copy Read: "PDF is password-protected". Same signature as the v1
  mission-wide cninfo limitation.
- file.finance.sina.com.cn H1-2025 report PDF (11355226.PDF): identical password-protected
  failure on both WebFetch and local Read.
- Net: 1 tier-1 primary fetched in full text [S920] + documented per-URL failures above (v1
  precedent: names below the 2-primary threshold pass G1 with a documented trail).

## Sources used

S920 (T1 fetched) FY2025 AR full text, sina statutory reproduction; S921 (T3 fetched) 中国基金报
2026-06-11; S922 (T3 fetched) 瑞财经 2025-02-20; S923 (T3 fetched) 同花顺F10; S924 (T3 fetched)
国盛证券 2025-05-06 via 发现报告; S925 (T3 fetched) 理杏仁 customer table; S926 (T3 fetched)
新浪科技 2022-04-14; S927 (T3 snippet) 财联社 数读IPO; S928 (T3 snippet) 新浪科技 2026-01-15;
S929 (T3 snippet) 新浪科技 2026-03-31; S930 (T4 snippet, rejected lead) 财富号 2026-04-26;
S931 (T3 snippet) 证券之星 2026-02-02.

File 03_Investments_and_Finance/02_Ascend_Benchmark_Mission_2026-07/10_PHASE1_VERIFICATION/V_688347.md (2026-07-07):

Educational benchmark for a paper-trading learning exercise. Simulated allocations, not investment advice or recommendations.

# V_688347 — 华虹公司/华虹宏力 Hua Hong, SSE-STAR 688347 (dual-listed 1347.HK)

Watchlist entry under test: not on the original v1 watchlist. Added under PATCH_BRIEF PP1
per `EXPANSION_SELECTION.md` candidate #1, sourced from the DISCOVERY note in `V_688981.md`:
"[S285] (TrendForce, 2026-02-25, citing Nikkei Asia/Mydrivers) explicitly names Hua Hong
alongside SMIC as jointly 'driving' China's push to boost 7nm/5nm-class output in the same
article that names Huawei's 2026 Ascend 950PR/950DT chipset launches as the demand driver."

## Claim under test

**Primary (advanced-node) hypothesis:** Hua Hong participates in the Huawei/Ascend-linked
foundry buildout named by TrendForce 2026-02-25. **Secondary hypothesis:** Hua Hong supplies
mature-node power-management/driver-IC product to Ascend-adjacent systems. Both are audited
against Hua Hong's own FY2025 annual results (published 2026-03-27) and Q1 2026 quarterly
results (published 2026-05-14) — the filing vintage fixed by A3 — plus dedicated 上证e互动
searching and four independently-dated 2026 tier-3 sources.

**This audit's central finding, established before any tier ruling can be made:** the
TrendForce/Reuters reporting chain that names "Hua Hong" in connection with Huawei's Ascend
buildout is, on close reading, about **上海华力微电子有限公司 (Shanghai Huali Microelectronics
Corporation, "Huali")** — a legally separate sister company under the same ultimate parent
(上海华虹集团, Hua Hong Group) — **not** about 688347/1347.HK (Hua Hong Semiconductor Limited,
the audited entity) directly. Hua Hong Semiconductor Limited is in the process of **acquiring**
Huali (a major asset restructuring, announced 2025-08-17, still pending final CSRC registration
as of 2026-07-04 — see "Corporate structure" section below), but that deal had **not closed**
as of either the FY2025 annual report or the Q1 2026 quarterly report. This is the single most
important fact this file establishes and it governs the tier/exposure reasoning throughout:
per the same discipline as assumption A8 (never silently equate an anonymized top customer
with Huawei), this file does **not** silently equate a not-yet-consolidated sister company's
reported activity with the audited entity's own current financials.

## Filings/results fetched

**Tier-1 (official primary): none successfully rendered.** Every direct attempt at a
688347/1347.HK-filed PDF this session failed with the same binary/FlateDecode-stream signature
documented elsewhere in this mission (see "Documented gap" below for the full per-URL list —
12 distinct failed fetches across cninfo, HKEXnews (×2), SSE's own sns.sseinfo.com e互动
system, cninfo's dataclouds IR-record host, 中财网, and a sell-side PDF host). This is a
stronger, more consistent PDF-failure rate than several other tickers in this mission,
matching the pattern the task's own briefing anticipated ("full annual-report PDFs on
cninfo/xueqiu are often password-protected/unparseable").

**Workaround used (per task's documented environment-limitation guidance):** every
quantitative claim below is instead sourced from named, dated financial-media HTML pages that
did render cleanly — 证券时报/STCN, 新浪财经, 财联社, 东方财富/caifuhao, fxbaogao.com,
BigGo Finance, and (for the Huawei/Ascend claim itself) TrendForce and The Substrate. Per
SOURCE_STANDARDS' mirror rule, every citation is logged at the tier of the page actually
fetched (tier 3), never promoted to tier 1, even where the content relays the company's own
filed figures. Gate check: 0 directly-fetched tier-1 PDFs; 16 fetched tier-3 sources used
instead (S900–S915); several report the same underlying filed figures independently and
cross-validate exactly (see arithmetic checks below) — the same evidentiary pattern
`V_301236.md` treated as sufficient, though (unlike that file) the Huawei-specific claim here
does **not** reach Tier A, for reasons given below.

## Own-filing structural facts (FY2025 + Q1 2026, RMB unless noted; all 亿元 figures manually
rescaled — 1亿 = 100,000,000 = one-tenth of one billion — after this session's tools
repeatedly mis-scaled 亿-denominated figures by 10x, a documented pattern in this mission;
every correction is noted explicitly)

**Revenue:**
- FY2025 (year ended 2025-12-31): **RMB 17.291 billion (172.91亿元)**, +20.18% YoY — quoted
  directly: *"华虹公司(688347.SH)发布2025年度业绩...营业收入为172.91亿元，同比增长20.18%"*
  [S900, tier 3, as-of 2026-03-27]. (Manual correction flagged: a fetch of a different mirror
  of the same result rendered this as "172.91 billion yuan" — a 10x tool mis-scaling error;
  172.91亿元 = RMB 17.291bn, confirmed by the independent USD cross-check below.)
- Same period in USD: **$2,402.1 million (~$2.402bn), +19.9% YoY** [S902, tier 3, as-of
  2026-03-27; consistent across three independently-worded fetches/searches]. Cross-check:
  $2.402bn × ~7.2 CNY/USD ≈ RMB 17.3bn, matching the RMB figure above almost exactly — the
  small 20.18% (RMB) vs 19.9% (USD) variance is an FX-translation effect, not a data conflict,
  the same pattern V_688981 documented for SMIC.
- Q1 2026 (quarter ended 2026-03-31): **RMB 4.625 billion (46.25亿元)**, +18.22% YoY [S904,
  tier 3, as-of 2026-05-14]. Same quarter in USD (per the company's own Q1 2026 earnings call,
  chairman/president 白鹏 Bai Peng): **$660.9 million, +22.2% YoY**. Cross-check:
  RMB4.625bn/$660.9M ≈ 7.0 CNY/USD — internally consistent.

**Profitability:**
- FY2025 gross margin: **11.8%**, +1.6 percentage points YoY [S902, tier 3, as-of 2026-03-27].
- FY2025 net profit attributable to shareholders: **RMB 377 million (3.77亿元)**, **-1.04%**
  YoY — quoted directly: *"归母净利润3.77亿元，下降1.04%"* [S900, tier 3, 2026-03-27]. FY2025
  non-recurring-adjusted net profit: RMB 229 million (2.29亿元), -6.66% YoY [S900].
  **Flagged conflict (SOURCE_STANDARDS rule 5, recorded not resolved):** one independently
  fetched USD-denominated aggregator page states FY2025 as a **"Net Loss: $110.8 million
  (improved 21.1% from 2024)"** [S902] — this conflicts in *sign* with the RMB-denominated
  positive-profit figure above and with Q1 2026's own YoY comparison base (which implies a
  positive prior-year profit). Given S900's figure is a direct, explicit, dated quote of the
  company's own reported RMB net-profit line, and is internally consistent with every other
  fetched source (Q1 2026 comparison bases, R&D-ratio arithmetic below), this file treats the
  RMB377m **positive**-profit figure as the reliable one and does **not** use the $110.8m loss
  figure as load-bearing anywhere — flagged here only so a later phase does not treat the two
  as reconcilable without checking.
- Q1 2026 net profit attributable: **RMB 140 million (1.4亿元 / 13,956.26万元)**, **+513.10%**
  YoY (prior-year-quarter profit was much smaller, not negative) [S904, tier 3, 2026-05-14],
  driven by *"平均销售价格及付运晶圆数量上升使得毛利上升，及本期为汇兑收益而上年同期为汇兑
  损失"* (higher ASP and wafer shipments lifting gross profit, plus an FX gain this quarter vs.
  an FX loss the prior-year quarter) [S904]. Q1 2026 gross margin (USD basis, company's own
  earnings-call figure): **13.0%**, +3.8 percentage points YoY.

**R&D (cross-validated, two independent sources agree exactly):** FY2025 R&D spend **RMB 1.994
billion (19.94亿元), 11.53% of revenue**, +21.37% YoY [S901, S903, both tier 3, 2026-03-27].
Arithmetic check: 1.994bn ÷ 17.291bn = 11.53% — exact match, confirming both the revenue and
R&D figures are correctly scaled.

**Capacity/utilization:** FY2025 overall capacity utilization **106.1%**; both 8-inch and
12-inch lines individually above 100% [S900, S901, S902 — three independent sources converge].
12-inch wafers ≈60% of FY2025 revenue [S900]. FAB9 (Wuxi, 12-inch) phase 1 targets achieved by
end-2025; phase 2 equipment installation targeting full capacity by Q3 2026 [S901].

**Specialty-process platform growth, FY2025 (own-filing content, relayed, all tier 3, 2026-03-27,
S901/S902 agree):** standalone non-volatile memory +44.2% YoY; embedded NVM (eFlash) +16.2%
YoY; analog & power management (BCD) +41.4% YoY; power discrete (IGBT) growing via process
iteration; logic & RF: 40nm ultra-low-power entering mass production. **No application/segment
revenue table (consumer vs. industrial vs. automotive vs. computing) and no customer-
concentration table were recoverable from any tier-3 relay fetched this session** — both are
disclosed only inside the full annual report, which could not be rendered (see Documented gap).

**Named non-Huawei fabless customers (search-derived from industry commentary, illustrative of
Hua Hong's typical customer profile, not independently fetched from a single primary source
this session — presented as color):** 新洁能 (IGBT/superjunction), 斯达半导 (IGBT), 艾为电子
(MCU), 卓胜微 (RF), 格科微 and 韦尔股份/豪威 (CIS) — all Chinese fabless analog/power/RF/CIS
design houses, none is Huawei. Consistent with Hua Hong's own description of itself as serving
"超800家客户" (over 800 customers) across a diversified mature-node base.

## Corporate structure: 688347 vs. Huali (华力微) — why this matters for the claim under test

**Group structure (established across multiple convergent, dated sources):** 上海华虹（集团）
有限公司 (Hua Hong Group, state-owned parent) is the ultimate controlling shareholder of BOTH
(a) 华虹半导体有限公司 (Hua Hong Semiconductor Limited, 688347.SH/1347.HK — the audited entity,
whose own operating subsidiary is 上海华虹宏力半导体制造有限公司, "Fab 7," 12-inch), and (b)
上海华力微电子有限公司 (Huali, operator of "Fab 5" — 65/55nm-40nm, built 2011 — and "Fab 6," a
28/22nm-baseline facility built 2018) — historically majority-owned **directly by Hua Hong
Group**, not by 688347.

**The acquisition (in progress, not yet complete):** 688347 announced (2025-08-17, trading
halted) a plan to acquire **97.4988% of Huali** via share issuance + cash, deal value RMB 8.268
billion (82.68亿元 — corrected from a tool mis-scaling that rendered this as "82.68 billion"),
plus a companion fundraise of up to RMB 7.556 billion (75.56亿元, also corrected from the same
error), to resolve an IPO-era same-industry-competition commitment (Hua Hong Group pledged to
inject Huali into the listco within 3 years of the STAR listing). Per Hua Hong's own board/
shareholder-meeting timeline (shareholder approval 2026-02-10; SSE inquiry-response process
through May 2026) and the most recent status update found this session: *"收购华力微电子97.5%
股权无条件过会，仅待注册批复"* (the acquisition of 97.5% of Huali has unconditionally passed
[SSE] review, pending only CSRC registration approval), expected to complete **in the second
half of 2026** [S913, tier 3, as-of 2026-07-04 — three days before this audit]. **As of today
(2026-07-07), the deal has not closed.** It was also not closed as of either the FY2025 annual
report (2026-03-27) or the Q1 2026 quarterly report (2026-05-14/earnings call), both of which
predate even the "unconditionally passed review" milestone.

**The 7nm/Huawei-linked activity is attributed to Huali, not to 688347's existing lines:**
per TrendForce citing Reuters, *"Huali's research and development of 7-nm chips at its Hua
Hong Fab 6 site began last year with support from Huawei-backed SiCarrier"* and *"Huali is
planning an initial production capacity of a few thousand 7-nm wafers a month by the end of
2026"* [S909, tier 3, 2026-04-29]. Separately, the disclosed, quantified capacity Hua Hong
itself is adding via the acquisition is described as mature-node: Huali's Fab 5 alone adds
**38,000 wafers/month of 65/55nm and 40nm capacity** [S914, tier 3]; no fetched source
attributes a 7nm production figure to 688347's own (pre-acquisition) fab base. **Net structural
finding: any Huawei/Ascend-linked advanced-node activity currently sits at Huali, a company
688347 does not yet own; even after the deal closes, the disclosed 7nm capacity figure (\"a
few thousand wafers/month\") is tiny relative to Hua Hong's overall $2.4bn+ revenue base.**
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

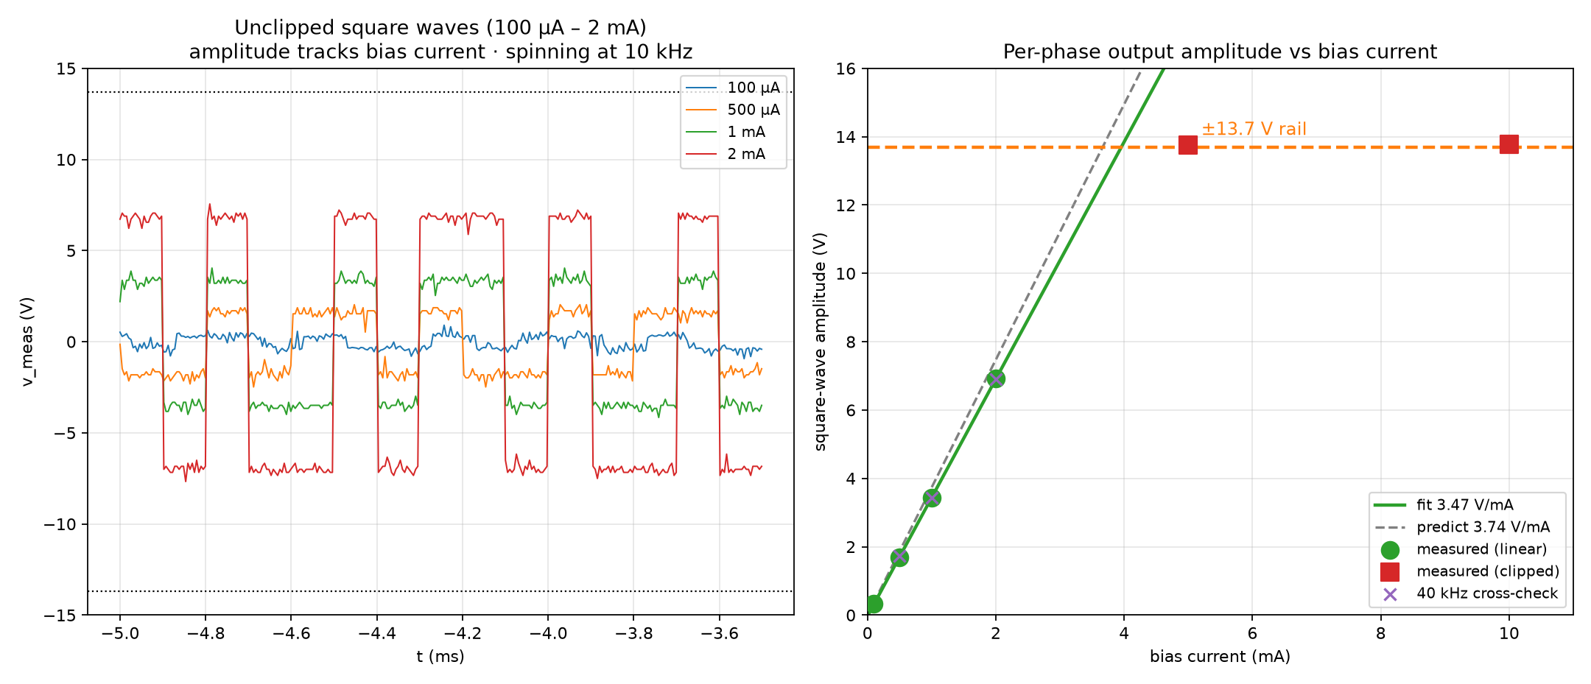
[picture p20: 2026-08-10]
01_PhD_Research/02_HSX_Hall_Sensor_Readout/analysis/figures/2026-07-10_bias_sweep_results.png

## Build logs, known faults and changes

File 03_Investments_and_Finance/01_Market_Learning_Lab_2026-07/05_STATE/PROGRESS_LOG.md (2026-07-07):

# PROGRESS_LOG

[2026-07-05] stage=0 setup: lab scaffolded; RB_01 + RB_02 seeded with 16 sources; watchlist seeded (13 names, tiers B/C); prediction P001 opened.

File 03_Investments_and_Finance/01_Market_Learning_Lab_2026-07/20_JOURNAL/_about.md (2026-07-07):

# 20_JOURNAL

Entries: `YYYY-MM-DD_W##_topic.md`. Weekly review from `_TEMPLATE_weekly_review.md`
every Sunday. The journal is the actual product of this lab — the paper portfolio just
generates material for it.

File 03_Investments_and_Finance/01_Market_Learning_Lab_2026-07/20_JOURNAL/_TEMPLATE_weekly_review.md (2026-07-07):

# Weekly Review — YYYY-MM-DD (W##)

## Time spent
~X h. Stage N of roadmap.

## What I learned (3 bullets max, concrete)
-

## Predictions
- Opened: P0##. Resolved: P0## → brier=. Running mean brier=.

## Paper portfolio
- Actions this week + one-line reason each. Current open positions: N.

## Mistake of the week
One honest one. What check would have caught it?

## Next week
Single highest-value task:

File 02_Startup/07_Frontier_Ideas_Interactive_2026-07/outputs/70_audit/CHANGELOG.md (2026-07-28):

# Stage 70 changelog

**No repairs were made to any canonical file.** All twenty files copied
into FINAL/ (eight portfolio documents, ten deep dives, GEOGRAPHY.md,
SELECTION.json) are SHA-256-identical to their accepted upstream
originals in outputs/60_synth, outputs/50_deep, and outputs/40_select.
FINAL/SOURCES.json is the one newly assembled artifact — the
deduplicated authoritative source subset (281 unique records: the 231
normalized 45_packs pool plus 50 frozen-atlas records cited by
FINAL/SELECTION.json, each tagged with record_origin) — assembled per
the stage contract, not a repair.

Findings documented without repair (see AUDIT.md for full detail):

- P3R2-A-10 and P3R2-F-01 carry G6 recorded as fail-as-frozen with
  `advance_with_repair` dispositions; the repairs were executed in
  stages 30-60 and the released base cases are the restructured ones.
  The as-frozen records are truthful history and remain untouched.
- Four minor open items (IEC 61788 unfetched; L05-028/L05-035 figures
  pending re-fetch; G-03 legacy penetration figures to re-source;
  JRC source annual refresh) are pre-disclosed at their points of use
  and carried in AUDIT.json as unresolved_minor.

No upstream output was edited at any point during this stage.

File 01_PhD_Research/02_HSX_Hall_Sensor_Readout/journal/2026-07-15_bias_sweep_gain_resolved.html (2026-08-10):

Reader view generated 2026-08-10 from 2026-07-15_bias_sweep_gain_resolved.md — the markdown is the source of truth (regenerate with python3 tools/md2html.py).

# Research Journal — 2026-07-10 bench session (presented 2026-07-15)

## Bias-current sweep on the emulator — the 109× magnitude anomaly is closed

Owner: Y. "Tim" Zhao · Project: 02_HSX_Hall_Sensor_Readout · Session type: sensorless (emulator) bring-up, plan §4 Day 3–4.

Captures: 2026-07-10, 18:32–18:42 (10 kHz set) and 19:08–19:10 (40 kHz set with sync), DSO-X 4022A. Presented in the 2026-07-15 group meeting, slides 4–6.

Primary data is in the repository: data/2026-07-10_bias_sweep/ (nine DSO-X CSV exports). Everything below is computed from it by analysis/bias_sweep_analysis.py; summary in data/2026-07-10_bias_sweep_summary.csv, figures in analysis/figures/. This entry originally quoted points digitized off the slide; those have been replaced by the measured values, which shifted the small-current points by up to 40 % and the fitted slope by 0.3 %.

Headline: the ~109× shortfall from 2026-07-08 is resolved. The readout tracks the bridge model to ~7 %, and the amplifier is demonstrably running at its design gain. Two things are newly open: the effective bridge imbalance, and the choice of spin rate (§5).

## 1. What was measured

Same emulator as 2026-07-08 — four 680 Ω arms with 2.2 kΩ across one of them — with the bias current swept instead of parked at 20 mA.

Amplitude is the mean |per-state mean − pedestal| after folding on the recovered phase rate and discarding 45 % of each phase at its edges.

Bias | Amplitude | V/mA | Regime
100 µA | 0.330 V | 3.30 | linear
500 µA | 1.694 V | 3.39 | linear
1 mA | 3.436 V | 3.44 | linear
2 mA | 6.915 V | 3.46 | linear
5 mA | 13.754 V | — | clipped at the rail
10 mA | 13.766 V | — | clipped at the rail

Fit over the unclipped points: 3.469 V/mA least-squares (intercept −29 mV), 3.450 V/mA through the origin. The slide prints 3.46 V/mA — reproduced to 0.3 %. Supply rail ±13.7 V.

The per-state model on slide 5 gives the differential at the amplifier input as ±37.26 Ω · I, with the eight signed products summing to zero (data/2026-07-15_emulator_phase_table.csv).

### Spin rate — not stated on the slide, recovered from the data

The captures do not record the phase rate, so it was recovered by folding (grid-search the phase duration, score the residual about the eight per-state means) and cross-checked against sync where available:

Set | Phase | Phase rate | Sampling | Fold score
100 µA, 500 µA, 1 mA, 2 mA, 5 mA, 10 mA | 100.0 µs | 10.0 kHz | 195.5 kSa/s | 0.98–1.00
500 µA, 1 mA, 2 mA _v2 | 25.0 µs | 40.0 kHz | 3.906 MSa/s | 0.99–1.00

The _v2 captures recorded sync on CH1; its period gives 40.013 kHz, agreeing with the folded 39.5–40.4 kHz to better than 2 %. Only two of the six 10 kHz folders were labelled _10khz; all six are at 10 kHz.

Slide 6 is therefore the 10 kHz set — a quarter of the 40 kHz SPECS nominal. The 40 kHz _v2 set is later, better instrumented, and is not on the slide.

## 2. Verification — is the anomaly actually resolved?

Yes. Three independent checks agree.

### 2.1 The prediction line is the same model that produced "~75 V"

37.26 Ω × 100.3 = 3.737 V/mA, which is the "predict 3.74 V/mA" printed on slide 6. Extrapolated to the old operating point: × 20 mA = 74.7 V, matching the "~75 V" in the 2026-07-08 entry. So this sweep is compared against exactly the model the anomaly was defined against.

### 2.2 The discrepancy collapsed from 109× to 1.08×

| 2026-07-08 | 2026-07-10
Predicted | 74.7 V @ 20 mA | 3.737 V/mA
Measured | 0.686 V | 3.469 V/mA
Ratio | 109× low | 1.08× low (7.2 %)

### 2.3 The clipping proves the gain independently of any fit

At 5 mA the differential into the amplifier is only 37.26 Ω × 5 mA = 186 mV, yet the output is hard against the ±13.7 V rail. Reaching that rail from 186 mV requires a gain of at least 74. No curve-fitting is involved. Under the failed-gain hypothesis (G ≈ 1) the 10 mA point would have produced 0.373 V; it produced a clipped 13.77 V.

## 3. What the original fault was

The 2026-07-08 entry listed two candidates and the test that would separate them: differential ≈ 0.75 V ⇒ candidate 1 (gain is not ~100× in operation); ≈ 7 mV ⇒ candidate 2 (the 2.2 kΩ imbalance is ineffective).

- Bridge differential at 20 mA = 37.26 Ω × 20 mA = 745 mV.
- Measured on 2026-07-08 = 686 mV.
- 686 / 745 = 0.92 — a signal chain running at ~unity gain, not 100.3.
- 100.3 / 0.92 = 109.0 — the anomaly factor, exactly.

So on 2026-07-08 the scope was reading the bridge differential essentially unamplified: candidate 1, to three significant figures.

Candidate 2 is ruled out. If the 2.2 kΩ were not unbalancing the bridge, the output could not scale as ~37 Ω · I · G, nor clip at 5 mA.

⚠️ Inference, not a recorded fact. Nothing in the deck or the captures states what changed between 08 and 10 July — an R_G/in-amp contact, a probe on the wrong node, a scope setting. The magnitude evidence is strong and self-consistent, but the physical root cause should be written down from bench memory.

## 4. Open — the effective bridge imbalance

The deck models 37.26 Ω. From the ideal schematic on slide 5 (four 680 Ω arms, 2.2 kΩ across one, current in at the top node, sense across the two mid-nodes):

R2 ∥ R5 = 680·2200/2880       = 519.4 Ω
branches: 1360 Ω  and  1199.4 Ω
|V(L) − V(R)| per amp of bias  = 42.66 Ω

Three values disagree: 34.59 Ω measured (3.469 V/mA ÷ 100.3), 37.26 Ω deck, 42.66 Ω ideal schematic. Against the schematic the measurement is 19 % low, not 7 %.

Candidates, none verified: mux on-resistance inside the sensed arms shifting the divider; resistor tolerance (the imbalance is a difference of near-equal quantities, so 1 % parts move it several percent — but 19 % is a stretch); or a correction already folded into the deck's 37.26 Ω that isn't written down.

Second-order, and it does not affect §2 — but the absolute V/T calibration must not be locked to the emulator until this is reconciled.

## 5. Spin rate — 10 kHz is too slow, 40 kHz costs nothing

The _v2 set repeats three bias points at 40 kHz, which makes this a controlled comparison:

Bias | 10 kHz | 40 kHz | Δ
500 µA | 1.694 V | 1.729 V | +2.1 %
1 mA | 3.436 V | 3.437 V | +0.1 %
2 mA | 6.915 V | 6.908 V | −0.1 %

Slope 3.450 V/mA at 10 kHz vs 3.451 V/mA at 40 kHz. Quadrupling the spin rate costs no amplitude. The +2.1 % at 500 µA is the noisiest point, not a trend.

Why: settling after a phase edge, ensemble-averaged over the 3.9 MSa/s captures, reaches 5 % of the step at 3.6 µs and 1 % at 3.8 µs (the floor is the scope's ~167 mV quantization, so the true settling is at least this fast). Against a 25 µs phase that is 14 %; against 100 µs, 4 %. Both are comfortable — 10 kHz just wastes the margin.

What the spin rate buys, given 8 states per cycle (update = f/8, signal bandwidth ≤ f/16). Blanking the leading 4.6 µs of every phase (3.8 µs measured settling × 1.2 margin) sets the duty actually integrated; at equal averaging time the noise penalty is √(duty_ref/duty):

f | Phase | Duty | Update | Signal BW | Noise vs 10 kHz
10 kHz | 100 µs | 95 % | 1.25 kHz | ≤ 0.62 kHz | 1.00×
20 kHz | 50 µs | 91 % | 2.5 kHz | ≤ 1.25 kHz | 1.02×
40 kHz (nominal) | 25 µs | 82 % | 5 kHz | ≤ 2.5 kHz | 1.08×
60 kHz | 16.7 µs | 73 % | 7.5 kHz | ≤ 3.75 kHz | 1.15×
80 kHz | 12.5 µs | 64 % | 10 kHz | ≤ 5 kHz | 1.23×
100 kHz (ceiling) | 10 µs | 54 % | 12.5 kHz | ≤ 6.25 kHz | 1.32×
160 kHz | 6.25 µs | 27 % | 20 kHz | 10 kHz | 1.88×

The physics target is ~1 kHz (stored-energy tracking on ms timescales; the coil ramp is 800 ms). 10 kHz delivers 0.62 kHz — below requirement. 40 kHz delivers 2.5 kHz for an 8 % noise penalty and no measured amplitude loss.

Why 10 kHz was probably chosen: the sweep was captured at 195.5 kSa/s, which is only 4.9 samples per phase at 40 kHz — too few to resolve the settled level. The _v2 set fixed that with 3.9 MSa/s but bought only 0.5 ms of record (2.5 cycles). At 40 kHz plan for ~1 MSa/s and the deepest record the scope allows; that is a DAQ constraint, not a circuit one.

Recommendation: run at 40 kHz. It is the SPECS nominal, it costs nothing in amplitude, it gives 4× the demodulated bandwidth, and it keeps the blanking window generous. 80 kHz is available if bandwidth is the binding constraint; 100 kHz is the practical ceiling.

The 10 kHz bandwidth on slide 2 is not reachable with 8-state spinning. It needs f = 160 kHz, where settling eats 56 % of every phase — above the SPECS "10k–100k usable" range and with no usable settled window left. The plan already anticipates this (§8 of the bring-up plan): record raw v_meas and demodulate offline, or use the static-phase "fast mode" (mode-2 firmware) for fast events. Slide 2's claim should be restated as the raw-chain bandwidth, with the demodulated bandwidth quoted separately.

## 6. Consequences for the real sensor

- Linear to ~2 mA, clipped by 5 mA on this emulator at G = 100.3.
- Rail-limited maximum differential ≈ 13.7 V / 100.3 = 137 mV.
- The intended ≤ 1 mA die operating point sits inside the linear range — at 1 mA the emulator gave 3.44 V, ~25 % of full scale. Good headroom without self-heating the die.
- 20 mA is past clipping; the 2026-07-08 magnitudes must not be re-used.

## 7. Plan status change (§4 Day 3–4)

Plan item | Was | Now
ΔV gain verification, G = 100.3 ±1 % | ✗ TOP PRIORITY | ✓ in effect — ≥74 from rail clipping, 92.8 % of prediction by slope. Not yet a formal ±1 % ΔV measurement.
Absolute-magnitude anomaly | ◑ open | ✓ closed
Sync-channel capture | ✗ not done | ✓ done (the three _v2 captures)
Bias-current linearity / headroom | not on the plan | ✓ done
Frequency study | ◑ partial | ◑ two points (10 and 40 kHz, identical amplitude); 100 k still untested
Effective bridge imbalance model | not on the plan | ◑ new open item

Still outstanding: static 8-state DMM survey, noise-floor PSD, rail-ripple spectrum, board log.

## 8. Next session

1. Move the spin rate to 40 kHz and re-take the sweep (§5).
2. Write down what was actually fixed between 08 and 10 July (§3).
3. Reconcile the bridge imbalance (§4): DMM the arms in-circuit and measure the amp-input differential directly at a held state; compare against 34.59 / 37.26 / 42.66 Ω.
4. Extend the frequency study to 80 and 100 kHz — settling says both should work; confirm the amplitude holds and watch the blanking fraction.
5. Noise-floor PSD, now that sync capture works and the record isn't quantization-limited.
6. Only after (3): set the operating point and start absolute calibration.

## 9. Also in the deck (not readout data)

Slide 3 shows a 3-axis package concept — three sensor bodies on a CF flange with a multipin feedthrough, ~1.250 in diagonal envelope. That belongs to 03_HSX_Vector_Probe_RSI2026. Slide 8 (Magnify) is out of scope by request and was not read.

↑ top

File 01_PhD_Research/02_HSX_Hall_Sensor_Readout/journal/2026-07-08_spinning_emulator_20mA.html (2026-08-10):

Reader view generated 2026-08-10 from 2026-07-08_spinning_emulator_20mA.md — the markdown is the source of truth (regenerate with python3 tools/md2html.py).

# Research Journal — 2026-07-08

Added 2026-08-09 — the §3 anomaly in this entry is CLOSED. The bias sweep of 2026-07-15 showed the readout tracking the bridge model to 7.4 % (3.46 vs 3.74 V/mA), and the 686 mV recorded below turns out to be the unamplified bridge differential (745 mV predicted) — the chain was running at gain ≈ 1 rather than 100.3, and 100.3/0.92 = 109.0. That is candidate 1 in §3. See journal/2026-07-15_bias_sweep_gain_resolved.md. Nothing below has been edited — it is the record as written on the day, and its magnitudes are still not usable for calibration.

## HSX Hall-sensor readout — first dynamic spinning run on the bridge emulator (20 kHz, 20 mA)

Owner: Y. "Tim" Zhao · Project: 02_HSX_Hall_Sensor_Readout · Session type: sensorless (emulator) bring-up, plan §4 / §6.1.

Today was the first end-to-end current-spinning run: Pico 2 clock → board → bridge emulator → AD8429 → oscilloscope capture → offline demodulation. Headline: the spinning-current offset cancellation works; one absolute-magnitude anomaly remains open and is the first task next session.

## 1. Configuration (as-run)

Parameter | Value
Bias current | 20 mA, external source
Spinning phase rate f | 20 kHz (8 × 50 µs = 400 µs full cycle; 2.5 kHz update)
Emulator bridge | 4 × 680 Ω ring, p1–p2–p3–p4
Parallel resistor | 2.2 kΩ across the p1–p2 arm (DMM-confirmed 2.2 kΩ)
Amplifier gain resistor R_G | 60.4 Ω — SMD code "76X" (EIA-96: 76→604, X→×0.1), DMM-confirmed connected → nominal G = 1 + 6000/60.4 = 100.3
Current-sense resistors | R9 = R10 = 100 Ω; both read 2.0 Vdc at 20 mA
Oscilloscope | Keysight DSO-X 4022A, CH2 = v_meas (J4), ~971 kSa/s, 8-bit (~33 mV LSB)
Firmware | firmware/pico2/main.py single-file build, MODE 1 (spin + scope), DEFAULT_FREQ = 20 kHz
Raw data | data/2026-07-08_test_spin.csv — v_meas only; sync (CH-b) NOT captured

## 2. Observations

- Clean 8-state staircase, period exactly 400 µs → the ADG1209/ADG5236 muxes are stepping through all eight states correctly at 20 kHz.
- Settled per-state levels: lows ≈ −0.40 V, highs ≈ +0.85 … +1.07 V, about a +0.27 V pedestal (the amplifier offset × G, constant across states). Offset staircase amplitude A ≈ 0.686 V. Raw per-state sign pattern + − − + − + + − — matches the spec emulator offset pattern.
- Phase-edge settling spikes to ~+4.8 V — normal mux charge injection; blanked 45 % before averaging.
- R9 = R10 = 2.0 V → 20 mA in = 20 mA out. Leakage check PASSED (plan §4 Day 3: V(R9)/R9 = V(R10)/R10) — the bias current genuinely flows through the bridge; no bias-loop leak.

Figure: analysis/figures/2026-07-08_spin_verify.png. Reproduce: python3 analysis/spin_verify_nosync.py data/2026-07-08_test_spin.csv --f 20000 --arm 680 --par 2200 --ibias 0.020.

## 3. Analysis

Offset cancellation — PASS. Sync wasn't captured, so phase was reconstructed by folding at the known 20 kHz. Demodulating (sign = +1 if a0 == a2 else −1) collapses the 686 mV raw offset swing to a residual ≤ 5 mV — and that 5 mV is just the DSO-X's 8-bit quantization (≈33 mV LSB) over only ~5 captured cycles, i.e. the measurement floor, not circuit error. So the spinning suppresses the offset by ≥ ~130× (measurement-limited). This is the core Week-1 §6.1-step-5 result.

Absolute-magnitude anomaly — OPEN. With every parameter above taken as confirmed — 680 Ω arms, an effective 2.2 kΩ imbalance, 20 mA through the bridge, gain 100.3 — the exact bridge model predicts a per-state amplifier output of ~75 V, i.e. pinned hard at the ±13.5 V rail. The scope shows a clean, unclipped 0.686 V. The measured offset is ~109× smaller than the confirmed components predict. This is a real inconsistency, not a rounding issue.

What today's data already rules in/out: - Current leakage — ruled OUT. R9 = R10 = 2.0 V ⇒ 20 mA reaches the bridge. - R_G value — ruled OUT as the cause by resistance alone. 60.4 Ω present and connected (measured).

Remaining candidates (either would explain a ~100× shortfall): 1. In-operation differential gain is not actually ~100× — e.g. an in-amp / R_G contact issue a static Ω check wouldn't catch, or the amp not settling at G=100 under this common-mode. Static resistance ≠ dynamic gain. 2. The 2.2 kΩ is not electrically unbalancing the bridge — an open solder joint on it, or it bridges the wrong node (a diagonal instead of the p1–p2 arm), leaving four matched 680 Ω arms whose residual tolerance offset happens to land near 0.686 V.

Decisive next test (NOT yet run): the ΔV gain check (plan §4 Day 3–4). Static-hold one state and either (a) inject a known ~1 mV differential on the sense pair and read ΔV_out/ΔV_in, or (b) DMM the differential right at the amp inputs (IN+ − IN−): - differential ≈ 0.75 V ⇒ candidate 1 (gain is not ~100× in operation); - differential ≈ 7 mV ⇒ candidate 2 (2.2 kΩ imbalance ineffective).

## 4. Verdict

The method and the signal chain are working: firmware/clocking, mux stepping, sync-less demod, and bias-loop integrity (R9 = R10) are all good, and current-spinning demonstrably cancels the bridge offset. The absolute offset magnitude is unexplained (~100× low) versus the confirmed component values — this is a consistency/measurement question to resolve with the ΔV gain check, not a demonstrated failure of the readout concept. Do not calibrate against these magnitudes until the anomaly is closed.

Side note: 20 mA is fine for the resistor emulator (~7 mW/arm) but is ~20× above the ≤ 1 mA operating point intended for the real GaN die (self-heating) — keep the real sensor ≤ 1 mA.

## 5. Plan comparison — This Week (Jul 6–12), §4 / §6.1 sensorless verification

Plan item | Status | Note
Cold checks / DMM value audit / J3 pin order (Day 1) | ◑ partial | as-built values being captured; not a full board log yet
First power: ±15 V rails, quiescent I, thermal (Day 1–2) | ◑ implied | board operating normally; not formally logged
DC/DC rail ripple spectrum (§2.5) | ✗ not done
Logic bring-up: a0/a1/a2/sync/EN edges, ground bond (Day 2) | ✓ done | 20 kHz spin + clean staircase confirms clocks; EN verified earlier
Emulator build + install (Day 3) | ✓ done | 680 Ω ring + 2.2 kΩ on p1–p2
Current source + R9/R10 leakage check (Day 3) | ✓ done | 20 mA; R9 = R10 = 2.0 V (passed)
Static 8-state survey, DMM per state (Day 3) | ✗ not done | do next session
ΔV gain verification, G = 100.3 ±1% (Day 3–4) | ✗ not done | TOP PRIORITY — resolves the §3 anomaly
Dynamic spinning + demod; residual ≈ 0 (Day 4–5) | ✓ core done | offset 686 mV → ≤ 5 mV; ◑ absolute magnitude anomaly open
Glitch / blanking / frequency study (Day 4–5) | ◑ partial | 45 % blanking at 20 kHz only; no 10k/40k/100k sweep
Noise floor PSD, µT/√Hz (Day 4–5) | ✗ not done | capture too short + quantization-limited
Sync-channel capture for the standard demod | ✗ not done | v_meas only; phase reconstructed offline
Week-1 deliverables (board log, sensorless memo, demod script) | ◑ in progress | this journal + spin_verify_nosync.py; board log + gain/noise pending

Legend: ✓ done · ◑ partial · ✗ not done.

## 6. Next session — priorities

1. ΔV gain check — static-hold a state, DMM the amp-input differential (or inject a known ~1 mV). Resolves the magnitude anomaly (gain vs imbalance). Everything else waits on this.
2. Static 8-state survey with a DMM per state (record v_meas vs the §1 sign table).
3. Re-capture with the sync channel (CH-b = GP19) and a longer window / finer vertical scale — then hsx_demod_scope_csv.py runs directly and the noise floor isn't quantization-limited.
4. Blanking + frequency study: repeat at f = 10 k / 40 k / 100 k.
5. Log rails/quiescent + DC-DC ripple spectrum if not already.
6. Once the magnitude is understood, set the deliberate emulator operating point and (for the real sensor) drop bias to ≤ 1 mA.

## 7. Artifacts (this session)

- data/2026-07-08_test_spin.csv — DSO-X 4022A capture (v_meas, 20 kHz, 20 mA)
- analysis/figures/2026-07-08_spin_verify.png — verification figure (raw, folded staircase, cancellation, verdict)
- analysis/spin_verify_nosync.py — reusable no-sync fold/demod/consistency analyzer

↑ top

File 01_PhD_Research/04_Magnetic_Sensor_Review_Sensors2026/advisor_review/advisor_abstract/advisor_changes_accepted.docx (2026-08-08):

“A Review of Magnetic-Field Sensing Technologies: Applications in Energy,
Transportation & Industry”

Version: July 31, 2026

Yiming Zhao¹, Blas L. Pérez Henríquez², and Debbie G. Senesky¹,³

Electrical Engineering, Stanford University
School of Humanities and Science, Stanford University
Aeronautics and Astronautics, Stanford University

Abstract (254 words):

Magnetic-field sensors enable non-invasive contactless measurement of electrical current and magnetic field levels emitting from a wide range of energy, transportation, and industrial systems (e.g., grid transformers, automotive drive trains, and robotic motion tracking). These sensors can assess the state of, mechanical motion, material characteristics, and equipment condition across energy, transportation, and industrial systems for prediction, control and forecasting, which can improve reliability, cost, and efficiency. A clear understanding of sensor operating principles, and transduction mechanisms, and operational limits helps identify suitable end applications and clarify the technical value of each technology. In this review, we compare established and emerging magnetic-field sensing technologies, as well as their use with new artificial intelligence (AI) tools. WeIt relates their performance and commercial maturity to representative applications in a range of these commercial domains. In addition, ourThe review also examines the implementation effects of data-driven methods with non-invasive magnetic-field sensing to enable real-time and in situ measurement of performance and digital twins of complex systems, as well as smart, seamless, adaptive and reliable and operational reliability under realistic and dynamic conditions. Leveraging this advanced sensing system approach, which fully exploits each technology’s strengths and improves measurement quality, and system capability, and decision making.Future progress will depend on closer integration between sensing hardware and computation. In addition, sSuch sensor integration must also support traceability and compliance with relevant industry standards and government policy. By connecting sensing principles with application value and technology readiness, this detailed review provides a practical framework for magnetic-field sensing technology development and research.

Magnetic-field sensors enable non-invasive measurement of current and magnetic field levels emitting from a wide range of energy, transportation, and industrial systems (e.g., grid transformers, automotive drive trains, and robotic motion tracking). These sensors can assess the state of mechanical motion, material characteristics, and equipment condition for prediction, control and forecasting, which can improve reliability, cost, and efficiency. A clear understanding of sensor operating principles, transduction mechanisms, and operational limits helps identify suitable end applications and clarify the technical value of each technology. In this review, we compare established and emerging magnetic-field sensing technologies, as well as their use with new artificial intelligence (AI) tools. We relate their performance and commercial maturity to representative applications in a range of commercial domains. In addition, our review examines the implementation of data-driven methods with non-invasive magnetic-field sensing to enable real-time and in situ measurement of performance and digital twins of complex systems, as well as smart, seamless, adaptive and reliable operation under realistic and dynamic conditions. Application-driven sensor selection involves matching device properties to the operating environment. Leveraging this advanced sensing system approach, which fully exploits each technology’s strengths and improves measurement quality,system capability, and decision making. This perspective also shifts attention from individual device specifications to complete sensing-system performance. Future progress will depend on closer integration between sensing hardware and computation. In addition, such sensor integration must support traceability and compliance with relevant industry standards and government policy. By connecting sensing principles with application value and technology readiness, this detailed review provides a practical framework for magnetic-field sensing technology development and research.

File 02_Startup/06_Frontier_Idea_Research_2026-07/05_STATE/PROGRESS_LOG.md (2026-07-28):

# Progress log

Append: `[ISO timestamp] phase= wave= status= reviewed= accepted= peer_reviewed= ideas= files= note=`

[2026-07-12T07:31:54.797123+00:00] phase=P0 wave=0 status=complete reviewed=0 accepted=0 peer_reviewed=0 ideas=0 files=05_STATE/ANTI_ANCHORING_PLAN.md,05_STATE/ASSUMPTIONS.md note=P0 initialized; folder structure verified; launcher model probes confirmed; anti-anchoring plan written
[2026-07-12T07:59:00.698423+00:00] phase=P1 wave=1-scouts status=complete reviewed=219 accepted=0 peer_reviewed=0 ideas=0 files=10_SOURCE_ATLAS/L01-L04 note=wave 1 scouts done; all Sonnet 5 confirmed; effort not exposed to subagents, logged unknown
[2026-07-12T08:25:14.024297+00:00] phase=P1 wave=1 status=checkpoint reviewed=271 accepted=206 peer_reviewed=110 ideas=0 files=90_BIBLIOGRAPHY/sources.json note=wave1 merged; T1 56.8% below 70% floor - waves 2-4 biased to T1 primary works; asia gate already met
[2026-07-12T08:49:04.184046+00:00] phase=P1 wave=2-scouts status=complete reviewed=217 accepted=0 peer_reviewed=0 ideas=0 files=10_SOURCE_ATLAS/L05-L08 note=wave 2 scouts done with T1 bias
[2026-07-12T09:07:54.873273+00:00] phase=P1 wave=2 status=checkpoint reviewed=555 accepted=405 peer_reviewed=220 ideas=0 files=90_BIBLIOGRAPHY/sources.json note=8 lanes merged; T1 65.4% - waves 3-4 keep T1 bias; asia/local/industry gates met
[2026-07-12T09:38:37.384239+00:00] phase=P1 wave=3-scouts status=complete reviewed=219 accepted=0 peer_reviewed=0 ideas=0 files=10_SOURCE_ATLAS/L09-L12 note=wave 3 scouts done; L09 fetch coverage weak, verifier must re-fetch aggressively
[2026-07-12T10:00:08.795703+00:00] phase=P1 wave=3 status=checkpoint reviewed=822 accepted=613 peer_reviewed=331 ideas=0 files=90_BIBLIOGRAPHY/sources.json note=12 lanes merged; 600-accepted floor crossed; T1 66.4% and peer 331/360 remain; wave 4 strict T1 mandate
[2026-07-12T18:23:08.445241+00:00] phase=P1 wave=4-scouts status=complete reviewed=207 accepted=0 peer_reviewed=0 ideas=0 files=10_SOURCE_ATLAS/L13-L16 note=wave 4 scouts done after one interrupted-session redispatch; strict T1 mandate; per-lane T1 85.5/74.1/89/77 pct approx; verifiers next
[2026-07-12T18:46:37.233407+00:00] phase=P1 wave=4 status=checkpoint reviewed=1066 accepted=804 peer_reviewed=443 ideas=0 files=90_BIBLIOGRAPHY/sources.json note=16 lanes merged; all mix gates pass except T1 69.5 pct vs 70 floor (need +13 net T1); top-up wave targets L01/L02/L04/L09 strictly-T1
[2026-07-12T19:03:03.155236+00:00] phase=P1 wave=t1topup-scouts status=complete reviewed=60 accepted=0 peer_reviewed=0 ideas=0 files=10_SOURCE_ATLAS/L01+L02+L04+L09_t1topup_raw_sources.json note=4 strictly-T1 top-up scouts done (41 academic candidates); verifiers next; L04 press-release-as-T1 flagged for verifier recheck
[2026-07-12T19:16:34.987868+00:00] phase=P1 wave=t1topup status=complete reviewed=1125 accepted=862 peer_reviewed=484 ideas=0 files=90_BIBLIOGRAPHY/sources.json note=T1 top-up verified+merged; ALL P1 gates pass: T1 71.2 pct, peer 484/360, demand 201/120, per-lane min 43; P1 COMPLETE, entering P2
[2026-07-12T19:24:48.656574+00:00] phase=P2 wave=validator status=pass reviewed=1125 accepted=860 peer_reviewed=484 ideas=0 files=90_BIBLIOGRAPHY/sources.json note=validate_sources PASS after 4-record repair; T1 614/860=71.4 pct; Fable atlas adjudication begins
[2026-07-12T19:30:02.717351+00:00] phase=P2 wave=atlas status=complete reviewed=1125 accepted=860 peer_reviewed=484 ideas=0 files=10_SOURCE_ATLAS/ATLAS.md note=P2 COMPLETE: validator PASS + Fable atlas adjudication PASS (demand real; L11 electrolyzer weakness and 8 enthusiasm zones documented); entering P3
[2026-07-12T20:34:49.136254+00:00] phase=P3 wave=scope-patch status=checkpoint reviewed=1125 accepted=860 peer_reviewed=484 ideas=0 files=CLAUDE.md,01_MISSION,05_STATE,20_OPPORTUNITY_POOL note=user geography directive applied: only US/CN/JP/TW target markets; IN/KR/SG excluded; pre-directive seed batches reconciled before longlist
[2026-07-12T21:08:28.859144+00:00] phase=P3 wave=us-china-weighting-patch status=checkpoint reviewed=1125 accepted=860 peer_reviewed=484 ideas=0 files=CLAUDE.md,01_MISSION,05_STATE,.claude/agents,tools note=latest user directive installed: regenerate >=80 P3R2 seeds; US/CN dominant; JP/TW/KR optional side markets; IN/SG excluded; second Fable/xhigh elegance pass required; no downgrade
[2026-07-12T23:56:53.392218+00:00] phase=P2A wave=india-origin-prefilter status=checkpoint reviewed=1118 accepted=833 peer_reviewed=474 ideas=0 files=90_BIBLIOGRAPHY/sources.json,10_SOURCE_ATLAS/L*_verified_sources.json,05_STATE/INDIA_SOURCE_ORIGIN_PREFILTER.* note=27 confirmed India-origin/India-only records quarantined as discovery-only; mixed academic exception preserved; all provisional numeric gates remain above thresholds; full accepted-source audit and atlas repair required before Fable/xhigh P3
[2026-07-13T00:08:02.423040+00:00] phase=P2A wave=2030-launch-patch status=checkpoint reviewed=1118 accepted=833 peer_reviewed=474 ideas=0 files=CLAUDE.md,01_MISSION,05_STATE,.claude/agents,tools note=2030 company-launch constraint installed; reuse durable 2026 technical baseline, refresh mutable evidence, require 2026-2029 preparation plus 2030-2034 trigger and G7 timing fit; P3 remains Fable 5/xhigh two-pass after P2A
[2026-07-13T01:04:31.685971+00:00] phase=P2A wave=full-origin-audit status=checkpoint reviewed=1118 accepted=818 peer_reviewed=468 ideas=0 files=05_STATE/INDIA_SOURCE_ORIGIN_AUDIT.md,05_STATE/INDIA_SOURCE_ORIGIN_AUDIT.json,90_BIBLIOGRAPHY/sources.json,10_SOURCE_ATLAS note=12/12 audit batches merged (818 pass, 15 new quarantines, 0 multinational exceptions); lane briefs + ATLAS scrubbed of 42 excluded IDs and derivative claims; validate_sources PASS; Fable/xhigh origin adjudication next
[2026-07-13T01:30:59.159530+00:00] phase=P2A wave=fable-adjudication status=complete reviewed=1118 accepted=818 peer_reviewed=468 ideas=0 files=99_AUDIT/P2A_FABLE_ORIGIN_ADJUDICATION.md note=P2A COMPLETE: validator PASS + Fable/xhigh origin adjudication PASS (80 sampled, 42 exclusions, 24 web checks, 20 fixes, L15-010 affirmed, L16-045 corrected); founder-fit cap typo in ATLAS fixed to 2/100; entering P3 round 2 under 2030 timing contract
[2026-07-13T05:30:26.478885+00:00] phase=P3 wave=r2-generation status=complete reviewed=1118 accepted=818 peer_reviewed=468 ideas=100 files=20_OPPORTUNITY_POOL/P3R2_A-E note=five Fable/xhigh batches produced 100 P3R2 seeds (A22 US, B22 CN, C22 dual, D20 wildcards, E14 JP/TW/KR-side); mechanical seed validation PASS (16 lanes, all contract fields, citations eligible); independent elegance adjudication next
[2026-07-13T11:00:46.791233+00:00] phase=P3 wave=longlist-freeze status=complete reviewed=1118 accepted=818 peer_reviewed=468 ideas=65 files=30_SCREENING/LONGLIST.json,30_SCREENING/LONGLIST.md,20_OPPORTUNITY_POOL/P3R2_* note=P3 COMPLETE: 126 seeds generated (A-G), three independent Fable/xhigh elegance adjudications, fixes applied and verified, longlist frozen at 65 ideas (16 lanes, US 54/36, CN 38/36, dual 27/24, JP/TW/KR 0/8 ALL GATES PASS), founder-fit appended post-freeze; entering P4
[2026-07-13T13:07:24.956476+00:00] phase=P4 wave=analysis status=checkpoint reviewed=1417 accepted=1112 peer_reviewed=470 ideas=65 files=30_SCREENING/EVIDENCE note=13/13 analyst groups complete (65 ideas, ~295 new accepted evidence sources all origin-audited); ledger curated and merged; cohort-aware validator PASS (atlas 72.6 pct T1, P4 evidence 92.2 pct T1+T2); cohort decision logged in ASSUMPTIONS for P8 scrutiny; Fable gate/score pass next
[2026-07-13T23:00:34-07:00] phase=P4 wave=chatgpt-recovery-global-calibration status=complete reviewed=1417 accepted=1112 peer_reviewed=470 ideas=65 files=30_SCREENING/SCORECARDS/P4_SCORES_ALL.json,30_SCREENING/SCORECARDS/P4_SCORES_ALL.md,30_SCREENING/SCORECARDS/P4_GLOBAL_CALIBRATION_LOG.md,tools/validate_p4.py note=P4 COMPLETE: malformed S2 preserved/regenerated; S4 generated; S1/S3 defects repaired; all 65 fully scored; 30 survivors/35 eliminated; batch and authoritative P4 validation PASS; source validation PASS; entering P5

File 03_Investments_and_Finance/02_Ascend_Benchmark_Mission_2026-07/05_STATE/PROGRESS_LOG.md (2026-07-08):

# PROGRESS_LOG
(one line per phase/wave: [ISO ts] phase= wave= names_done= sources= notes=)

[2026-07-06T22:52:34-07:00] phase=0 wave=- names_done=0 sources=16 notes=P0 done: UNIVERSE.csv written (13 names, ticker order, no ranking); sources.json seeded with 16 prior-corpus snippet entries; frag dirs created; P1 wave plan 4+4+4+remainder
[2026-07-06T23:45:00-07:00] phase=1 wave=1 names_done=4 sources=67 notes=000034/000628/002156/002261 audited; tiers A/A/C/A; 51 sources merged (S100-S156, no collisions); env limitation logged: full annual-report PDFs unparseable (no poppler) -> workers use 摘要/quarterlies/IR records; VERIFIED_WATCHLIST.csv assembly deferred to end of P1
[2026-07-07T00:20:00-07:00] phase=1 wave=2 names_done=8 sources=125 notes=002281/002371/002916/300308 audited; tiers C/B/C/B; 002916 downgraded from prior B (current filings anonymize customers); 300308 exposure ceiling = domestic 9.42% of FY2025 rev; 45 sources merged S160-S204 + 13 self-merged S205-S217 by 300308 worker (dedupe checked); discovery lead logged: 西部证券 2026-03-29 names 意华股份/航天电器/华丰科技 backplane connectors (S204)
[2026-07-07T01:10:00-07:00] phase=1 wave=3 names_done=12 sources=183 notes=301018/600498/600839/688629 audited; tiers C/A/A/B; 600839 debunk (listed co never held 华鲲振宇; parent did); 600498 confirm (长江计算 consolidated 70.71%); 688629 top customer 60.52% corroborated-Huawei; 58 sources merged after fixing 301018 frag CSV-style quote escaping (A11); universe 13->14 (301236 added per A10); wave 4 = 688981 + 301236
[2026-07-07T02:05:00-07:00] phase=1 wave=4 names_done=14 sources=213 notes=688981/301236 audited (B/A); GATE G1 PASS: 14/14 V_ memos + VERIFIED_WATCHLIST.csv (14 rows) + ledger 213 entries no dupes; 5 names below 2-primary threshold all carry documented per-URL failure trails (PDF tooling limitation); 688347 discovery noted-not-added (A10); moving to phase 2
[2026-07-07T02:50:00-07:00] phase=2 wave=1 names_done=4 sources=254 notes=F_ files for 000034/000628/002156/002261; missing cells 0/3/0/1 all justified (top5 conc gaps); 41 sources merged; ops learnings propagated to wave 2: Read-on-WebFetch-cache PDF trick, 万元-unit vigilance, F10/sina wrong-company cross-validation requirement
[2026-07-07T03:30:00-07:00] phase=2 wave=2 names_done=8 sources=301 notes=F_ files for 002281/002371/002916/300308; missing 1/0/1/0 justified; conflicts resolved not averaged (002281 NP bases; 300308 GM triangulation; 002371 common-control restatement); 47 sources merged; aggregator errors caught and discarded in 3 of 4 audits
[2026-07-07T04:10:00-07:00] phase=2 wave=3 names_done=12 sources=347 notes=F_ files for 301018/301236/600498/600839; missing 0/0/3/3 justified (top5 conc unavailable outside unparseable/password-protected full reports); DEFECT CAUGHT: V_600839 mislabeled 利润总额 as attributable NP - corrected via appended note, true FY2025 NP=988.89M; 46 sources merged; wave 4 = 688629 + 688981
[2026-07-07T05:00:00-07:00] phase=2 wave=4 names_done=14 sources=370 notes=F_ files for 688629 (rerun after mid-write API failure, recovered via resume) + 688981; GATE G2 PASS: FUNDAMENTALS.csv 42 rows, 0 empty cells, 16 MISSING all justified; ledger 370 no dupes; moving to phase 3 valuation
[2026-07-07T06:30:00-07:00] phase=3 wave=val-1..4+scoring names_done=14 sources=424 notes=all 14 VAL_ files + VALUATION.csv done (13 PFP + 1 NEUTRAL flags; quotes as-of 2026-07-07 close, dual-vendor consistency-checked); initial SCORES.csv + SCORING_NOTES.md written per rubric (no rankings in this log per rule 4); scoring conventions logged as A12; CSV disclaimer convention A13 applied; 6 red-team targets selected by initial totals; RT wave 1 of 2 launching
[2026-07-07T08:15:00-07:00] phase=3 wave=redteam names_done=14 sources=464 notes=GATE G3 PASS: 6 REDTEAM_ memos (40 challenges incl. new load-bearing facts: Entity-List closure, 1260H, in-house-optics precedent, tender tables, core-loss quarterly splits); ALL answered in REDTEAM_RESPONSES.md (R0 uniform rulings + per-cell accept/rebut); SCORES.csv rewritten post-rescore; citation defects conceded and corrected; 6 rt frags merged (S700-S747, no dupes); zero names clear 3.0 bar -> P4 cash-heavy construction per rubric rule; moving to phase 4
[2026-07-07T09:00:00-07:00] phase=4 wave=- names_done=14 sources=464 notes=GATE G4 PASS: BENCHMARK_PORTFOLIO.csv (constructed per SCORING_RUBRIC construction rule; layer caps honored; composition/weights withheld here per rule 4, see 40_PHASE4_PORTFOLIO/ only), ANSWER_KEY_BENCHMARK.md, SELF_TEST.md (Spearman+overlap+disagreement protocol), PREDICTIONS_APPEND.csv (7 dated falsifiable calls, A15 schema), BENCHMARK_WORKBOOK.xlsx (6 tabs, openpyxl round-trip PASS); disclaimers verified on all 10_/20_/30_/40_ files incl. patched _about.md; spoiler scan clean (all hits false-positive); launching P5 source-auditor
[2026-07-07T10:30:00-07:00] phase=5 wave=- names_done=14 sources=464 notes=GATE/AUDIT PASS: 99_AUDIT/AUDIT_REPORT.md written; ledger 464 entries/0 dupe ids/tier1=35(>=25)/tier4 never load-bearing (5 spot-checked); 20/20 number-truth spot-check figures confirmed against fresh independent re-fetch (4 via co-cited alternate source after a primary cninfo/xueqiu PDF proved password-protected this session); quota checks (universe 14/14, FUNDAMENTALS 42 rows/16 justified MISSING, SCORES.csv cell_sources complete, redteam coverage correct, disclaimers 62/62) all PASS; spoiler-boundary scan found+fixed one mechanical leak (this log's own prior line 15 named the portfolio's equity-name count/cash-pct in parens -> redacted to a process-only description, no rankings restated here per rule 4); workbook structurally verified (6 worksheet parts confirmed, build script logic correct) though a live openpyxl re-run was outside this auditor session's toolset. mission=COMPLETE.

# ACCURACY PATCH (PP0–PP4 per 01_MISSION/PATCH_BRIEF.md; A## numbering continues in ASSUMPTIONS.md)
[2026-07-07T10:05:00-07:00] phase=PP0 wave=- names_done=0 sources=464 notes=patch setup: MASTER_STATE=COMPLETE verified; v1 artifacts all present (14 V_/F_/VAL_, 6 REDTEAM_, 4 CSVs, portfolio set, ledger 464, audit PASS); PATCH_STATE initialized; A17-A20 logged (S-ID blocks S900+, transport, new-name baseline scoring, layer cap-groups); EXPANSION_SELECTION.md written (5 selected from documented leads: 688347/688141/002436/688535/688519; no rankings); UNIVERSE.csv 14->19; host clock 10:05 (v1 final line's 10:30 stamp was an estimate that overshot; append order is authoritative); PP1 wave 1 launching (4 filing-auditors)
[2026-07-07T11:25:00-07:00] phase=PP1 wave=p1 names_done=5 sources=549 notes=5 patch V_ files + VERIFIED_WATCHLIST rows merged (tiers: 688347 B not-yet-consolidated Huali nuance; 688141 B named-sell-side, own-AR silent; 002436 C Ascend-specific vs A generic-Huawei; 688535 C weakest-hop-capped w/ Hubble 3.00pct equity fact; 688519 B w/ 17.70pct segment ceiling); 688141 worker interrupted mid-run -> audit rerun INLINE by orchestrator per rule 10 (harness declined worker respawn), 7 fetched + 5 snippet sources, PDF failures documented (password-protected, matches v1 limitation); ledger spliced 464->549 entries 0 dupes; rows/ transport cleaned; P2 fundamentals wave 1 launching (4 sonnet workers)
[2026-07-07T12:20:00-07:00] phase=PP1 wave=p2 names_done=5 sources=612 notes=5 patch F_ files + 15 FUNDAMENTALS.csv rows merged (all 0-MISSING 27/27 grids); 002436 worker API-drop resumed mid-task and completed; conflicts resolved-not-averaged per SOURCE_STANDARDS (688347 NP consolidated-vs-attributable bridge shown + GM CNY-vs-USD conflict documented UNRESOLVED; 688535 audited-AR NP supersedes 业绩快报, FY25 includes ~2mo 衡所华威 consolidation flagged; 688519 10jqka GM/RD figures discarded on line-item-identity contradiction, top5_conc newly filled); aggregator wrong-company/wrong-figure failures caught in 3 of 5 audits; ledger 549->612 0 dupes; cr_flags parked in PATCH_STATE for FR reviewers; P3 valuation wave launching (4 sonnet workers, quotes 2026-07-07 close)
[2026-07-07T13:45:00-07:00] phase=PP1 wave=p3+gate names_done=5 sources=632 notes=GATE PG1 PASS: 5 VAL_ files + 5 VALUATION.csv rows merged (all quotes 2026-07-07 16:14-16:15 CST close, dual-vendor gtimg+eastmoney price-x-shares reconciled; ttm P/E built from genuine quarterly NP where fetchable); ledger 612->632 entries 0 dupes, no S-ID collisions across S900-S1144 patch blocks; 19/19 universe now has V_/F_/VAL_ coverage; baseline scores for the 5 additions written to SCORING_NOTES_v2.md per A19 (no v1 scores restated); MASTER_STATE counters refreshed to 19/632 with patch pointer; PP2 critical-review batch 1 launching (3 parallel per F2)
[2026-07-07T14:55:00-07:00] phase=PP2 wave=cr-batch1 names_done=4/19 sources=632+frags notes=SAFE-STOP checkpoint per F2: FR_ files done for 688347/688141/002436/688535 (no deltas >=0.5, 0 re-redteam triggers so far; per-cell deltas and tier rulings in FR_ files, no totals restated here per rule 4); fr_ frags pending ledger splice at batch cadence; batch 2 launching (688519 + first v1 names, 3 parallel)
[2026-07-07T16:10:00-07:00] phase=PP2 wave=cr-batch2 names_done=8/19 sources=632+frags notes=SAFE-STOP checkpoint per F2: FR_ done for 688519/688629/600839/000034; ONE |delta|>=0.5 re-redteam trigger so far (600839; queued for re-red-team after consolidation; per-name cell movement and trigger mechanism withheld here per rule 4, see 30_); all 5 new names now reviewed; batch 3 launching (300308/688981/002281, then 002916)
[2026-07-07T17:30:00-07:00] phase=PP2 wave=cr-batch3 names_done=12/19 sources=632+frags notes=SAFE-STOP checkpoint per F2: FR_ done for 300308/688981/002281/002916 (688981 reviewer API-drop resumed and completed on budget); no new re-redteam triggers (600839 remains the only one); W4 anchor clarified via 002916 review: the anchor's evidence tier binds to the growth NARRATIVE being priced, not the Ascend link already penalized in W1/W2; principle to be applied to remaining PFP-on-tier-C names and codified in consolidation (per-name cell outcomes withheld here per rule 4, see 30_ SCORES_v2.csv/SCORING_NOTES_v2.md); batch 4 launching (002261/301236/002156, then 002371)
[2026-07-07T18:50:00-07:00] phase=PP2 wave=cr-batch4 names_done=16/19 sources=632+frags notes=SAFE-STOP checkpoint per F2: FR_ done for 002261/301236/002156/002371; second re-redteam trigger queued (002156; trigger class = rank-motion per brief, attribution withheld here per rule 4, see 30_); W2 conventions now fully reconciled across reviews (point-or-proven-minimum in band -> band score; band-spanning bound alone -> 0; per-name cell applications withheld here per rule 4, see 30_ SCORES_v2.csv/SCORING_NOTES_v2.md); 301236 gained its first tier-1 artifact (jina render of cninfo abstract, all figures exact); batch 5 launching (301018/600498/000628, 3 parallel - final batch)
[2026-07-07T19:55:00-07:00] phase=PP2 wave=cr-batch5+consolidation names_done=19/19 sources=671 notes=ALL 19 FR reviews complete (301018/600498/000628 all confirmed; 000628 debunk re-verified against full 2026 YTD announcement list); 19 fr_ frags spliced, ledger 632->671 entries 0 dupes; SCORES_v2.csv consolidated (schema v1+total_v1/delta/fr_status, all 19 rows REVIEWED, no FR-DEFERRED); re-redteam triggers finalized: 4 names queued under the brief's two trigger classes (|delta|>=0.5 / rank-motion), set visible from 30_ REDTEAM_*_v2 file names, per-name trigger attribution withheld here per rule 4; re-red-team wave launching 3 parallel (Fable-inherited red-team-critic), REDTEAM_<t>_v2.md outputs; no rankings restated here per rule 4
[2026-07-07T22:40:00-07:00] phase=PP2 wave=re-redteam+responses names_done=19/19 sources=698 notes=GATE PG2 PASS: 5 re-red-team memos (600839/002156/688519/688347/688141; per-name trigger attribution in 30_ only per rule 4) + 26 challenges + 3 defect demands ALL answered in REDTEAM_RESPONSES_v2.md (R5.1-R5.5); new cross-cutting rulings R0.5-R0.8 codified (W4 chain-nexus, W2 bound conventions restated, regulator-axis W3, entity-scope W1); orchestrator verification fetches settled the 688347 deal-perimeter question (Fab-5-only, Ascend-linked Fab 6 excluded - S1350) and surfaced the 688141 statutory loss-trigger agenda item (S1352); two FR upgrades reversed on adversarial review, one survived; SCORES_v2.csv FINAL (19 rows, cells+totals+ranks post-RT2, citation defects fixed incl. 688519 S1166->S1167 and 600839 R0.1-basis superseded); corrections appended to VAL_688347/FR_688347 (deal-size 7.48x restatement); one additional rank-motion trigger ruled satisfied by existing v1+FR coverage (name and reasoning in REDTEAM_RESPONSES_v2 status note only); ledger 671->698 entries 0 dupes; SCORING_NOTES_v2 §2 filled with conventions + full v1->v2 movement table; moving to PP3 deliverables
[2026-07-08T00:15:00-07:00] phase=PP3 wave=- names_done=19/19 sources=698 notes=GATE PG3 PASS: ANSWER_KEY_BENCHMARK_v2.md (full 19-name reasoning + CHANGELOG with per-name deciding evidence, v1 file untouched); BENCHMARK_PORTFOLIO_v2.csv (construction rules honored: 5 names all in distinct A20 layer-groups + cash per <3.0 rule); SELF_TEST.md §7 v2 addendum appended (blind attempt not yet made -> v2 is the key; n=19 Spearman; extra-credit entity-scope drill); PREDICTIONS_APPEND_v2.csv (PB08-PB14, 7 new dated falsifiable calls); BENCHMARK_WORKBOOK_v2.xlsx via build_workbook_v2.py (6 tabs, 19 names, v1/v2 side-by-side in Scores tab via total_v1/delta; openpyxl round-trip PASS + row-count assertions PASS; one CSV-quoting defect in SCORES_v2 cell_sources caught by column-count check and fixed before gate); disclaimers 108/108 md+csv in 10_/20_/30_/40_; spoiler scan run and 3 rank-class leaks in this log's own PP2 lines redacted to process-only language (v1-audit fix pattern); PATCH_STATE totals scrubbed to 30_-only per rule 4; PP4 source-auditor launching
[2026-07-08T01:05:00-07:00] phase=PP4 wave=- names_done=19/19 sources=698 notes=GATE PG4 / PATCH AUDIT PASS: 99_AUDIT/PATCH_AUDIT.md written by source-auditor; 12/12 changed-figure re-fetches confirmed exact (incl. CJH segment split, 688347 deal perimeter + issue terms, 688519 by-grade mix + SSE inquiry, 002156 net debt + AMD 8-K, 688141 top-1 + S1282 roadshow silence, 002916/002281 concentration); ledger 698 entries (464 v1 + 234 patch) 0 dupe ids, tier discipline confirmed, tier-4 never load-bearing; deliverables checklist complete (PP1/PP2/PP3), v1 artifacts verified untouched; auditor found+fixed 3 further per-ticker cell-value leaks in this log's PP2 lines (mechanical redaction, no scores altered); 688141 FY2025 audit-opinion type reproduced-unverifiable on the actual document (password-protected, 4th attempt) - open item, no score impact; no audit frag minted (re-fetches of already-ledgered URLs). PATCH_STATE=COMPLETE; MASTER_STATE patch pointer updated. patch=COMPLETE.

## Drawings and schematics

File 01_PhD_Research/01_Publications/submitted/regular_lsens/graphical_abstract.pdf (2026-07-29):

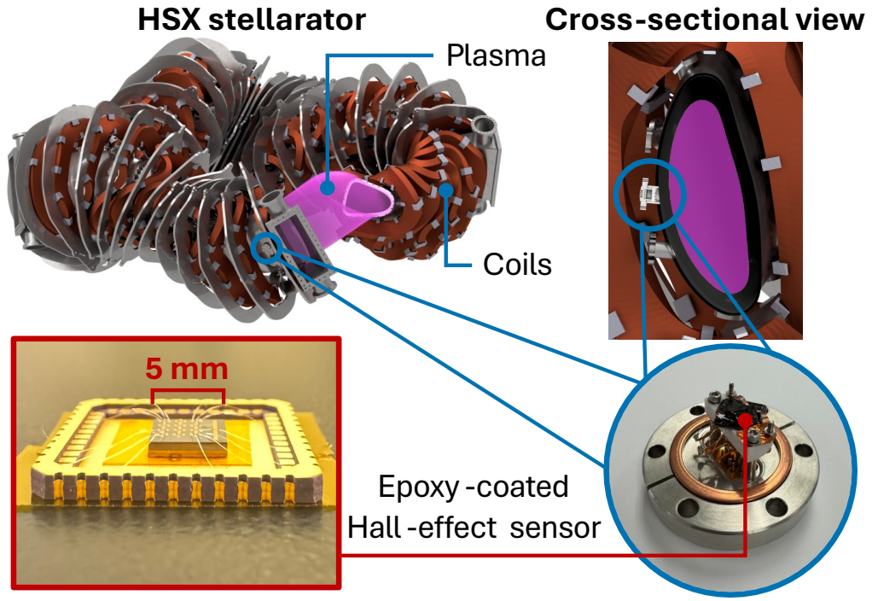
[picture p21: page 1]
HSX stellarator; Cross-sectional view; Plasma; Coils

Epoxy -coated
Hall -eect sensor

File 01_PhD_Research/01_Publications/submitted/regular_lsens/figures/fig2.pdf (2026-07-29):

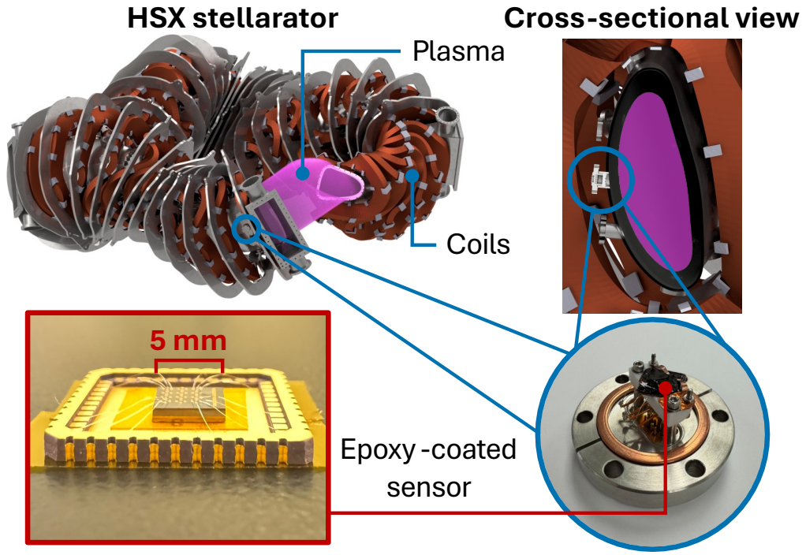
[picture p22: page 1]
HSX stellarator; Cross-sectional view; Plasma; Coils; Epoxy -coated sensor

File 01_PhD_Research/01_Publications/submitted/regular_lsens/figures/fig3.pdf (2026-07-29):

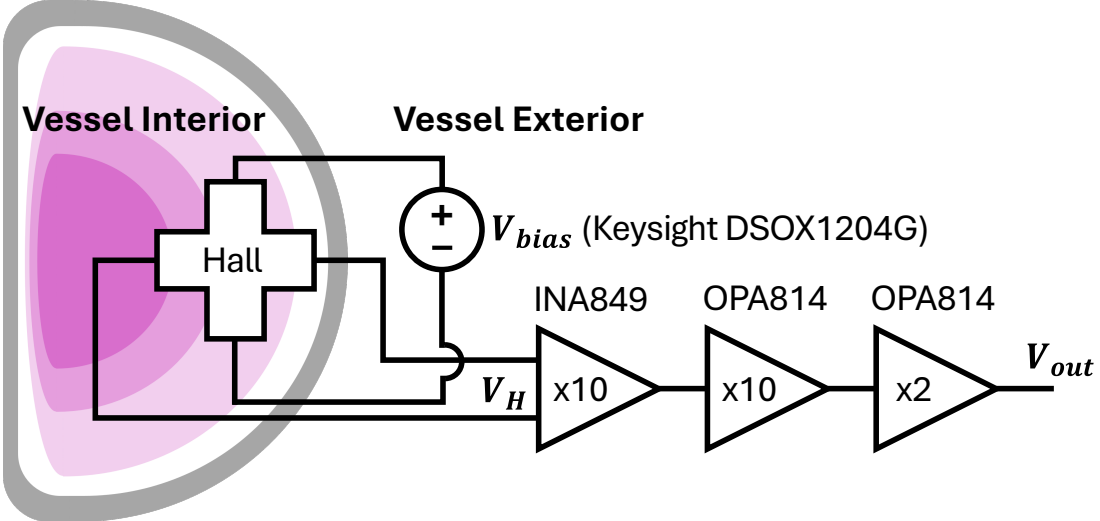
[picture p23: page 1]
Hall; Vessel Interior; INA849; OPA814 OPA814; Vessel Exterior; (Keysight DSOX1204G)

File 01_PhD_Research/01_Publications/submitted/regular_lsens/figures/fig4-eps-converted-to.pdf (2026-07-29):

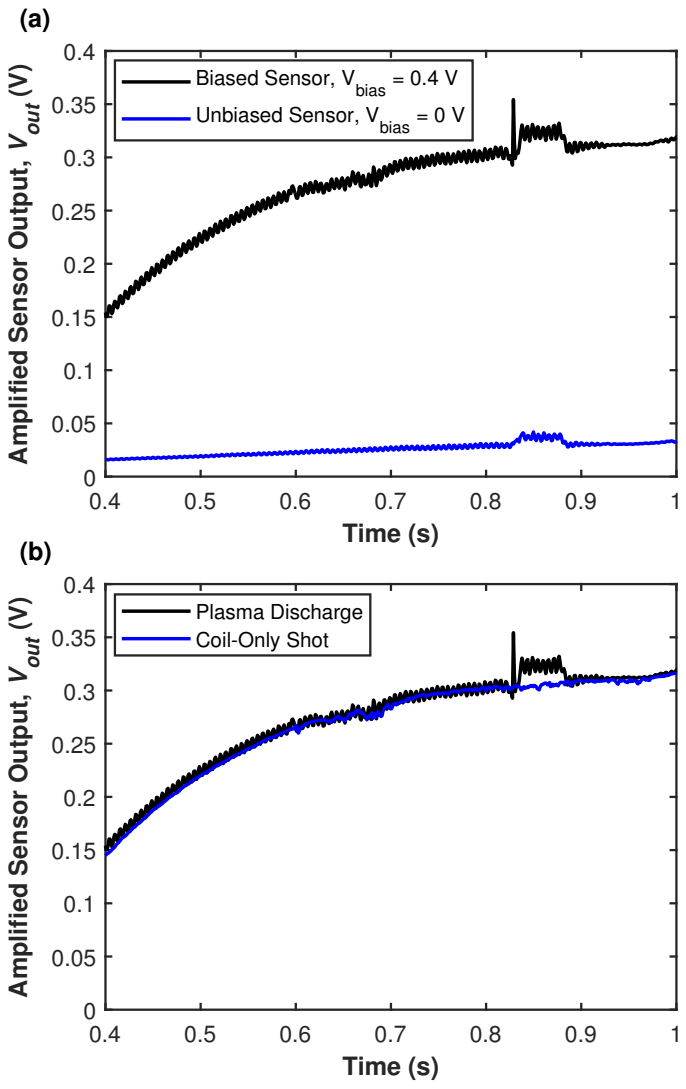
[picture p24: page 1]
Time (s)

Amplified Sensor Output, Vout (V)

Biased Sensor, Vbias = 0.4 V
Unbiased Sensor, Vbias = 0 V

Plasma Discharge
Coil-Only Shot

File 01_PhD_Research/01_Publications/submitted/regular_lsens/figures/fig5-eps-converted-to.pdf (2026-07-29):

60 | (a)
0.5 | (a')

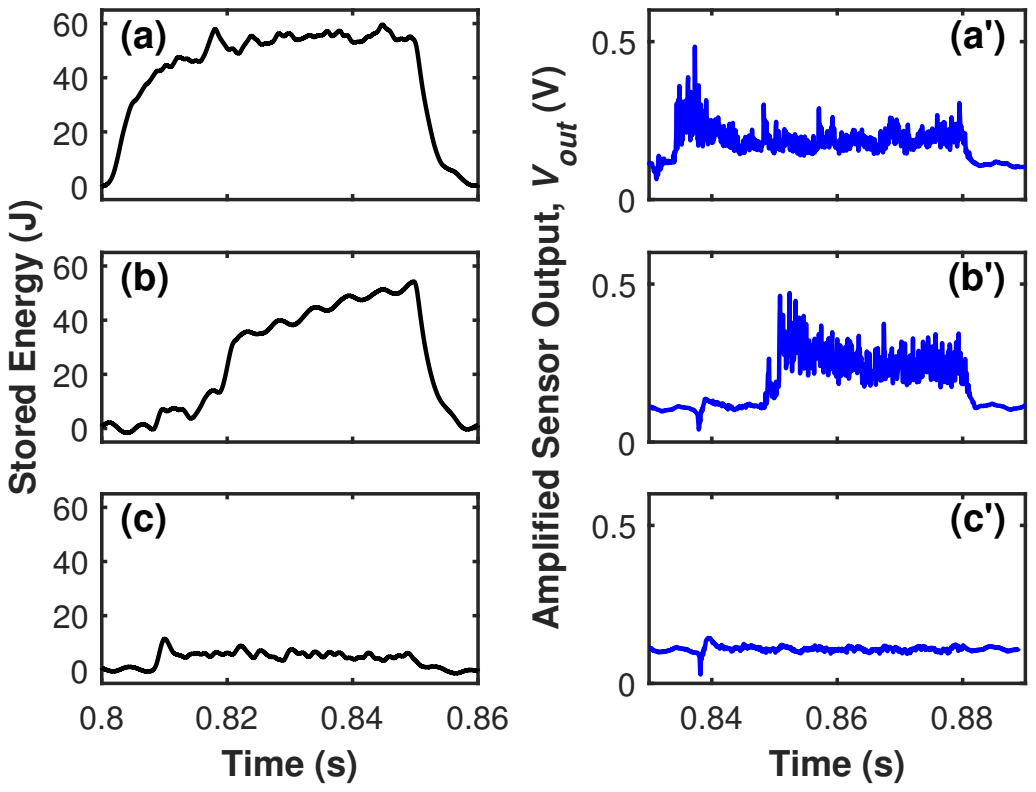
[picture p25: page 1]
Stored Energy (J); Time (s)

Amplified Sensor Output, Vout (V)

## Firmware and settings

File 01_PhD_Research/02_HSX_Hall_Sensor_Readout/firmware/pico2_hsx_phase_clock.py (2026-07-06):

"""
pico2_hsx_phase_clock.py
------------------------
Raspberry Pi Pico 2 (RP2350) firmware for the HSX Hall-sensor readout board.

Generates the three spinning-mux clocks a0/a1/a2 (a 3-bit binary counter,
one increment per phase) plus a frame-sync pulse, using one PIO state
machine so all four outputs update on the SAME clock edge -- no software
GPIO skew between bits, which is what "atomic" meant in the bring-up plan.
EN is driven from a plain GPIO, separately, with explicit sequencing.

WIRING (change PIN_* below if you use different GPIOs)
  Pico GP16 -> J3 pin 3 (a0)
  Pico GP17 -> J3 pin 2 (a1)
  Pico GP18 -> J3 pin 1 (a2)
  Pico GP19 -> scope channel 2 / trigger input (sync pulse, NOT to J3)
  Pico GP20 -> J3 pin 4 (en)
  Pico GND  -> board GND1 (bond separately -- J3 has no ground pin)

SAFE SEQUENCE (matches the runbook)
  1. Power the board, confirm +-15V on the scope.
  2. Bond Pico GND to GND1 if not already done.
  3. Run start(f) -- this raises EN, THEN starts the clock.
  4. To connect/disconnect the sensor or emulator plug: run stop() first,
     which stops the clock and drops EN before you touch the connector.

USAGE (from the MicroPython REPL / Thonny Shell, after saving this file
to the Pico as main.py or importing it interactively):

    >>> import pico2_hsx_phase_clock as pc
    >>> pc.start(40000)     # begin spinning at f = 40 kHz
    >>> pc.status()
    >>> pc.stop()           # stop clock, drop EN, safe to unplug sensor
    >>> pc.hold_state(0b011)   # freeze at one static 8-state code (a2 a1 a0)
    >>> pc.menu()           # optional interactive text menu, see HELP below

f is the *phase rate*: each of the 8 states lasts 1/f seconds, so the full
demod cycle is 8/f seconds (200 us / 5 kHz update rate at f = 40 kHz), and
a0 itself toggles at f/2 -- matching "a0 = square wave, period 2/f" in the
bring-up plan.
"""

import machine
import rp2
from machine import Pin

# ---------------------------------------------------------------- config --
PIN_A0 = 16     # base pin of the 4-pin PIO "set" group -- must be contiguous:
PIN_A1 = 17     #   PIN_A0, PIN_A0+1, PIN_A0+2, PIN_A0+3 = a0, a1, a2, sync
PIN_A2 = 18
PIN_SYNC = 19
PIN_EN = 20     # plain GPIO, controlled directly (not part of the PIO group)

DEFAULT_FREQ = 40_000   # Hz, phase rate (matches the bring-up plan's nominal f)

_SM_ID = 0


# ------------------------------------------------------------ PIO program --
# One "set pins" instruction per phase, 1 SM clock cycle each (no delay
# field used), so running the state machine at freq=f makes every phase
# last exactly 1/f seconds. wrap() loops back to state 0 for free (no
# extra cycle cost), so the cycle is a clean, jitter-free 8/f seconds.
#
# Bit mapping within each 4-bit value (matches the demod convention
# state = (a2<<2)|(a1<<1)|a0 from the bring-up plan):
#   bit0 -> a0   bit1 -> a1   bit2 -> a2   bit3 -> sync
# sync is high only during state 0 (a0=a1=a2=0), giving one sync pulse,
# 1/f seconds wide, at the start of every 8-phase cycle.
@rp2.asm_pio(set_init=(rp2.PIO.OUT_LOW,) * 4)
def _phase_gen():
    wrap_target()
    set(pins, 0b1000)   # state 0: a2,a1,a0 = 0,0,0   sync = 1
    set(pins, 0b0001)   # state 1: a0 = 1
    set(pins, 0b0010)   # state 2: a1 = 1
    set(pins, 0b0011)   # state 3: a1,a0 = 1,1
    set(pins, 0b0100)   # state 4: a2 = 1
    set(pins, 0b0101)   # state 5: a2,a0 = 1,1
    set(pins, 0b0110)   # state 6: a2,a1 = 1,1
    set(pins, 0b0111)   # state 7: a2,a1,a0 = 1,1,1
    wrap()


# ------------------------------------------------------------- EN control --
_en_pin = Pin(PIN_EN, Pin.OUT, value=0)   # boot low = matches board pulldown


def enable():
    """Drive EN high. Muxes only respond once V_INH (~2 V) is exceeded."""
    _en_pin.value(1)


def disable():
    """Drive EN low. Do this before connecting/disconnecting the sensor."""
    _en_pin.value(0)


def en_state():
    return _en_pin.value()


# --------------------------------------------------------- state machine --
_sm = rp2.StateMachine(_SM_ID, _phase_gen, freq=DEFAULT_FREQ,
                        set_base=Pin(PIN_A0))
_current_freq = DEFAULT_FREQ


def set_freq(f):
    """Reconfigure the phase rate without starting/stopping EN. Returns the
    achieved frequency (the RP2350 clock divider is 16.8 fixed-point, so
    round target frequencies against machine.freq() -- e.g. 10k/40k/100k
    against a 150 MHz sys clock -- land on an exact integer divisor)."""
    global _current_freq
    was_active = _sm.active()
    _sm.active(0)
    _sm.init(_phase_gen, freq=int(f), set_base=Pin(PIN_A0))
    _current_freq = f
    if was_active:
        _sm.active(1)
    divider = round(machine.freq() / f)
    achieved = machine.freq() / divider
    print("target {:.1f} Hz -> achieved {:.3f} Hz (sys clock {} Hz, divider {})"
          .format(f, achieved, machine.freq(), divider))
    return achieved


def start(f=None):
    """Raise EN, then start spinning at frequency f (Hz, phase rate).
    Call only after +-15V rails are confirmed and Pico GND is bonded to
    GND1. If f is None, keeps whatever frequency was last set."""
    if f is not None:
        set_freq(f)
    enable()
    _sm.active(1)
    print("spinning at {:.0f} Hz phase rate, EN high".format(_current_freq))


def stop():
    """Stop the clock and drop EN. Do this before touching the DSUB
    connector (sensor or emulator plug)."""
    _sm.active(0)
    disable()
    print("stopped, EN low -- safe to (dis)connect the sensor")


def hold_state(state):
    """Freeze a0/a1/a2/sync at one of the 8 static codes (0-7) for the
    manual Day-3 survey (probe with a DMM/scope while stepping through
    all 8 by hand). Stops the running clock first. EN is left as-is --
    call enable() separately if it isn't already on."""
    state &= 0x7
    value = state | (0b1000 if state == 0 else 0)
    _sm.active(0)
    # Documented MicroPython technique: StateMachine.exec() runs one
    # instruction directly on a paused SM. "0" here is the PIO SET
    # destination code for pins (see rp2.StateMachine.exec in the
    # MicroPython docs), not the symbolic "pins" keyword used inside
    # the @asm_pio-decorated program above.
    _sm.exec("set(0, {})".format(value))
    print("held at state {:03b} (a2 a1 a0), sync={}".format(
        state, 1 if state == 0 else 0))


def status():
    print("EN     : {}".format("HIGH" if _en_pin.value() else "low"))
    print("running: {}".format(_sm.active()))
    print("freq   : {:.0f} Hz phase rate ({:.0f} Hz update rate, "
          "8-phase cycle)".format(_current_freq, _current_freq / 8))
    print("sys clk: {} Hz".format(machine.freq()))


# ------------------------------------------------------- optional menu ----
HELP = """
HSX phase-clock control -- commands:
  start [f]     raise EN and start spinning (Hz, e.g. 'start 40000')
  stop          stop spinning and drop EN (do this before (dis)connecting sensor)
  en            raise EN only
  dis           drop EN only
  freq f        change phase rate without touching EN (e.g. 'freq 100000')
  hold n        freeze at static state n = 0-7 (binary a2 a1 a0), e.g. 'hold 5'
  status        show EN / running / frequency
  help          show this message
  quit          stop and exit the menu
"""


def menu():
    print(HELP)
    while True:
        try:
            cmd = input("pico> ").strip()
        except (EOFError, KeyboardInterrupt):
            break
        if not cmd:
            continue
        parts = cmd.split()
        c = parts[0].lower()
        try:
            if c in ("h", "help", "?"):
                print(HELP)
            elif c in ("start", "s"):
                start(int(parts[1]) if len(parts) > 1 else None)
            elif c in ("stop", "x"):
                stop()
            elif c == "en":
                enable()
            elif c in ("dis", "disable"):
                disable()
            elif c == "hold":
                hold_state(int(parts[1], 0))
            elif c in ("freq", "f"):
                set_freq(int(parts[1]))
            elif c in ("status", "st"):
                status()
            elif c in ("q", "quit", "exit"):
                stop()
                break
            else:
                print("unknown command -- type 'help'")
        except (ValueError, IndexError):
            print("bad arguments -- type 'help'")
        except Exception as e:
            print("error:", e)


if __name__ == "__main__":
    # Only runs if this file is executed directly (e.g. saved as main.py
    # and the board is reset). Does NOT auto-start spinning -- boots to
    # a safe idle state (EN low, SM inactive) and drops into the menu.
    menu()

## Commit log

2026-07-04 Add final research
    [SCORING_MATRIX.csv, source_evidence_ledger.csv, source_evidence_ledger_v1.csv]
2026-07-04 Add new strategy planning
    [SCORING_MATRIX.csv, source_evidence_ledger.csv, source_evidence_ledger_v1.csv]
2026-07-06 Add 03
    [SCORING_MATRIX.csv]
2026-07-07 Add finance and investment
    [PAPER_PORTFOLIO.csv, PREDICTIONS_LOG.csv, WATCHLIST.csv]
2026-07-07 Add more 03
    [BENCHMARK_PORTFOLIO_v2.csv, BENCHMARK_WORKBOOK_v2.xlsx, FUNDAMENTALS.csv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]
2026-07-08 Add cocktail
    [BOM.csv]
2026-07-08 uploaded 07/08 progress
    [2026-07-08_test_spin.csv]
2026-07-10 Begin review paper
    [reference_registry.csv]
2026-07-10 Add 05
    [bom_verdict.csv, concept_A.scad, concept_A.stl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]
2026-07-27 Add new things
    [00_CLAIM_BASELINE.csv, 00_REQUIREMENTS_TRACE.csv, 01_EVIDENCE_MAP.csv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]
2026-07-29 Sync new
    [00_CLAIM_BASELINE.csv, 00_REQUIREMENTS_TRACE.csv, 01_EVIDENCE_MAP.csv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]
2026-08-08 Reorganize 01_PhD_Research and 02_Startup; import HSX IP/arXiv package
    Import
    - Add 01_PhD_Research/10_HSX_IP_and_arXiv_Screen_2026-08 from the uploaded
    HSX_IP_ARXIV_2026-08 package, flattening its redundant double nesting.
    Recovered content
    - 01_Publications/submitted/regular_lsens/ — the LaTeX project for the
    manuscript submitted 2026-07-02 existed only inside a package input
    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
    [00_CLAIM_BASELINE.csv, 00_REQUIREMENTS_TRACE.csv, 01_EVIDENCE_MAP.csv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]
2026-08-08 Add the unified startup source database and portfolio-level docs
    02_Startup/00_SOURCE_DATABASE/ merges every source record the startup
    research ever produced into one reusable, queryable corpus:
    3,432 unique sources from 14,543 raw records across 177 files in all
    seven projects. Five JSON dialects, a CSV evidence ledger, a patent
    ledger and a hand-kept markdown ledger all map onto one schema.
    Deduplication collapsed 76% of the corpus — the average document had
    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
    [sources.csv]
2026-08-08 Keep empty placeholders out of the snapshot manifests
    Every zero-byte file hashes alike, so the dedup pass mapped all 57 empty
    placeholders in the PAP06 input snapshot (.keep, .gitkeep and similar)
    onto whichever empty file sorted first in the repository — which turned
    out to be the then-empty 02_Startup_Folder_Info.md. Writing content into
    that file broke all 57 manifest rows.
    Empty files cost nothing to keep, so keep them: restore the 57 into the
    snapshot, drop their rows from the manifest, and regenerate the snapshot
    .gitignore. Manifest is now 2,236 rows and rehydrate.py --check reports
    zero drift again; the full round trip was re-verified against every
    recorded hash.
    Correct the aff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
    [SNAPSHOT_MANIFEST.csv]
2026-08-10 Close the 109x readout magnitude anomaly from the 2026-07-15 bias sweep
    The 2026-07-08 run measured 0.686 V where the bridge model predicted
    ~75 V at 20 mA — a 109x shortfall — and left two candidates open. The
    2026-07-15 group-meeting deck contains the sweep that settles it.
    Extracted from the deck (slides 4-6; Magnify slide excluded):
    - data/2026-07-15_bias_sweep.csv — amplitude vs bias current, linear to
    ~2 mA (0.1/0.5/1/2 mA) and clipped at the +/-13.7 V rail by 5 mA.
    Points are digitized off the published figure and flagged as such; the
    raw captures are not in the repo.
    - data/2026-07-15_emulator_phase_table.csv — per-state model,
    v_state = +/- 37.26 ohm * I, signed pro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
    [2026-07-15_bias_sweep.csv, 2026-07-15_emulator_phase_table.csv]
2026-08-10 Preserve the snapshot copies of files the readout update changed
    Editing SPECS.md and the 2026-07-08 journal broke three rows of the
    PAP06 snapshot manifest: a canonical file that legitimately changes can
    no longer reproduce the July copy of itself, so rehydrate.py --check
    started reporting drift.
    Materialise those three snapshot copies from the pre-edit commit,
    retire their manifest rows (2236 -> 2233), and regenerate the snapshot
    .gitignore so the now-physical files are tracked. Both rehydrate checks
    report 0 drifted again.
    This is the same class of fault as the empty-placeholder fix: the
    manifest can only carry rows whose canonical file is expected to stay
    put. Anything the research act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
    [SNAPSHOT_MANIFEST.csv]
2026-08-10 Add the primary bias-sweep captures; recover the spin rate; update the deck
    The nine unlabelled DSO-X CSVs are the primary data behind slide 6. They
    are the same instrument (MY57310245), captured 2026-07-10 18:32-19:10,
    and the six bias folders correspond one-to-one with the slide's points.
    Confirmed by re-deriving the slide: fitting the four unclipped points
    gives 3.469 V/mA, reproducing the printed 3.46 V/mA to 0.3%. Measured
    amplitudes are 0.330 / 1.694 / 3.436 / 6.915 V with 5 and 10 mA clipped
    at the +/-13.7 V rail. The earlier figure-digitized estimates were up to
    40% off at the small-current end and are now replaced.
    The spin rate is not recorded in the captures, so it is recovered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
    [100uA.csv, 10mA_10khz.csv, 1mA.csv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]
2026-08-10 Recommend 40 kHz: add the duty/noise trade behind the spin-rate choice
    The earlier table quoted settling as a percentage of the phase, which
    shows the constraint but not the cost. What actually decides the rate is
    the duty left after blanking the leading edge, since at equal averaging
    time the noise penalty is sqrt(duty_ref/duty).
    Blanking 4.6 us (3.8 us measured settling x1.2 margin): 40 kHz keeps 82%
    duty for an 8% noise penalty and 2.5 kHz bandwidth, against 95% and
    0.62 kHz at 10 kHz. The physics target is ~1 kHz, so 10 kHz is below
    requirement and 40 kHz clears it with margin at negligible cost. 100 kHz
    is the ceiling and needs the outstanding rail-ripple spectrum first, in
    case spin h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
2026-08-10 Record the possible 40 kHz interference as open — the data cannot settle it
    Checked against the 2026-07-10 captures. The question is not answerable
    from them: 40 kHz is degenerate with spin content in both sets, being the
    phase rate itself in the _v2 captures and the 32nd harmonic of the
    1.25 kHz cycle rate in the 10 kHz set, and there is no spin-off baseline
    record to compare against.
    What the captures do establish is that 40 kHz carries no operational
    penalty. With the state alignment recovered, the eight signed state means
    cancel to 4.9/2.2/0.7 mV at 10 kHz and 0.8/8.5/3.1 mV at 40 kHz — 0.01 to
    0.29% of amplitude either way, with the ordering flipping between bias
    points, so it is s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

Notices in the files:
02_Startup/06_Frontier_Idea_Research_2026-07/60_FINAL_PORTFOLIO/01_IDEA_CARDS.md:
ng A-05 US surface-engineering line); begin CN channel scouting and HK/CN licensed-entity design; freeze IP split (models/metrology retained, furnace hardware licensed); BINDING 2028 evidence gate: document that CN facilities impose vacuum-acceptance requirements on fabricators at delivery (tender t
